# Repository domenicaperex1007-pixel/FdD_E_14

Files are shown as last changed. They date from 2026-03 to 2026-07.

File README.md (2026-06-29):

# 🌍 Equipo 14 - Fundamentos de diseño
## Carrera de Ingeniería Ambiental / Informática/ Industrial
## Universidad Peruana Cayetano Heredia
## 👥Descripción del equipo

### Somos el **equipo 14** del curso de **Fundamentos de Diseño 2026-1**, conformado por estudiantes de distintas ramas de ingeniería.

### *Nuestro objetivo es aplicar la metodología de diseño para generar soluciones innovadoras, reales y con impacto social, tecnológico y ambiental.*
## 🎯 Objetivos de Desarrollo Sostenible (ODS)

*Nuestro proyecto se alinea con los siguientes ODS:*

- 💧 **ODS 6:** Agua limpia y saneamiento  
- 🏙️ **ODS 11:** Ciudades y comunidades sostenibles  
- 🌱 **ODS 13:** Acción por el clima

## 🌊 ODS 6: Agua limpia y saneamiento    

El **Objetivo de Desarrollo Sostenible 6** plantea la necesidad de garantizar el acceso universal a agua potable y servicios de saneamiento adecuados.

En el Perú, aproximadamente el 90% de la población urbana accede a agua potable, pero en zonas rurales amazónicas esta cifra puede descender a menos del 70%, evidenciando brechas significativas<sup>1</sup> . 

En la selva peruana, las inundaciones contaminan fuentes de agua con residuos, sedimentos y agentes patógenos, incrementando enfermedades como diarreas, dengue entre otras. En regiones como Loreto, donde las inundaciones afectan cada año a miles de familias, el impacto sobre el acceso a agua segura es directo. Esta situación nos demuestra que la gestión del agua no puede desligarse de la gestión del riesgo de desastres, ya que eventos extremos deterioran rápidamente las condiciones sanitarias.

## 🏙️ ODS 11: Ciudades y comunidades sostenibles

El **Objetivo de Desarrollo Sostenible 11** plantea reducir significativamente el impacto de desastres en comunidades vulnerables. 

En el Perú, las lluvias intensas e inundaciones representan más del 60% de las emergencias registradas anualmente, afectando a más de 170,000 personas en la temporada del 2022 al 2023<sup>2</sup> . En la región Loreto, provincias como Requena presentan alta vulnerabilidad debido a su ubicación en zonas inundables y su limitada conectividad. De hecho, eventos recientes han llevado a declarar estado de emergencia en distritos de Requena por inundaciones recurrentes que afectan viviendas, cultivos y servicios básicos<sup>3</sup> . 

Esta problemática nos muestra que la planificación por parte de la comunidad es clave para reducir riesgos. A su vez, la protección de infraestructuras de agua depende de una adecuada organización del territorio, lo que muestra la dependencia recíproca entre ambos objetivos.

## 🌱 ODS 13: Acción por el clima

El **Objetivo de Desarrollo Sostenible 13** se enfoca en fortalecer la resiliencia frente al cambio climático, el cual ha incrementado la frecuencia de lluvias intensas y crecidas de ríos en el Perú<sup>4</sup> . Este fenómeno agrava tanto la disponibilidad de agua segura como la sostenibilidad de las comunidades. En este contexto, la implementación de sistemas de alerta temprana resulta clave como medida de adaptación. Estos sistemas permiten anticipar inundaciones, facilitando la protección de fuentes de agua, la evacuación oportuna y la reducción de pérdidas humanas y materiales.

Por ejemplo, un sistema de alerta temprana como Llaqta Guardian podría reducir la exposición al riesgo al emitir alertas oportunas incluso en contextos de baja conectividad. De esta manera, la integración de estos tres objetivos resulta fundamental para abordar la problemática de las inundaciones en la Amazonía peruana.

## 📸 Fotografía del Equipo
<p align="center">
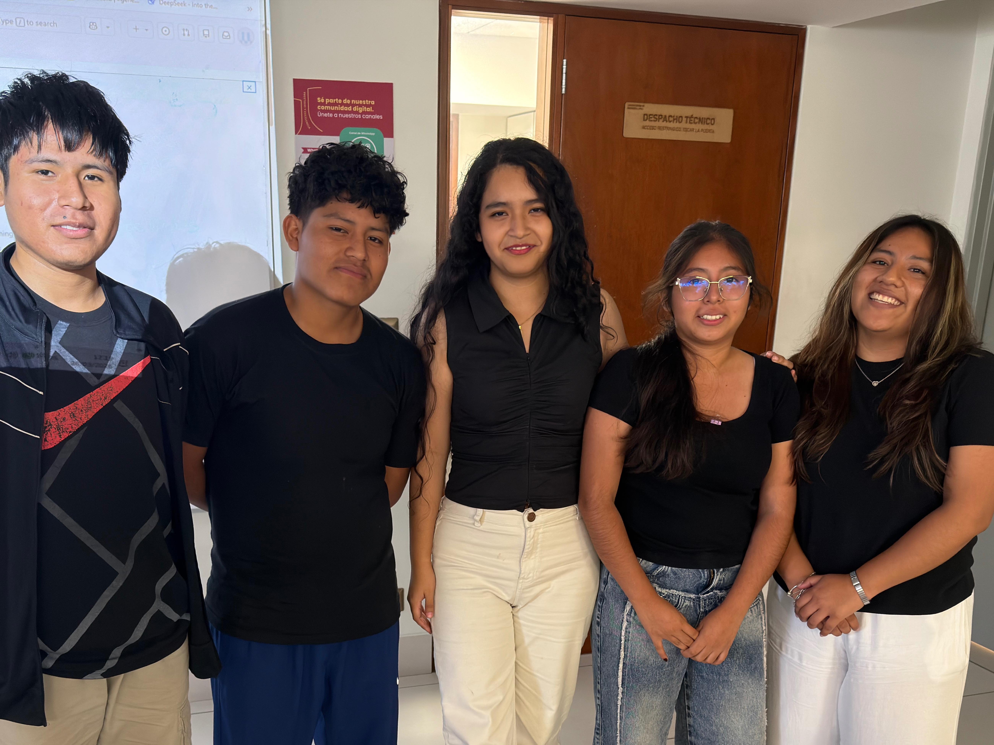
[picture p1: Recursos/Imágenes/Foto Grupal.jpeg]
  
  <br>
  <em>Figura 1. Fotografía del equipo 14</em>
</p>

## 👥 Integrantes del equipo

| Foto | Nombre | Rol | Correo electrónico | Habilidades |
|---|---|-----|---|---|
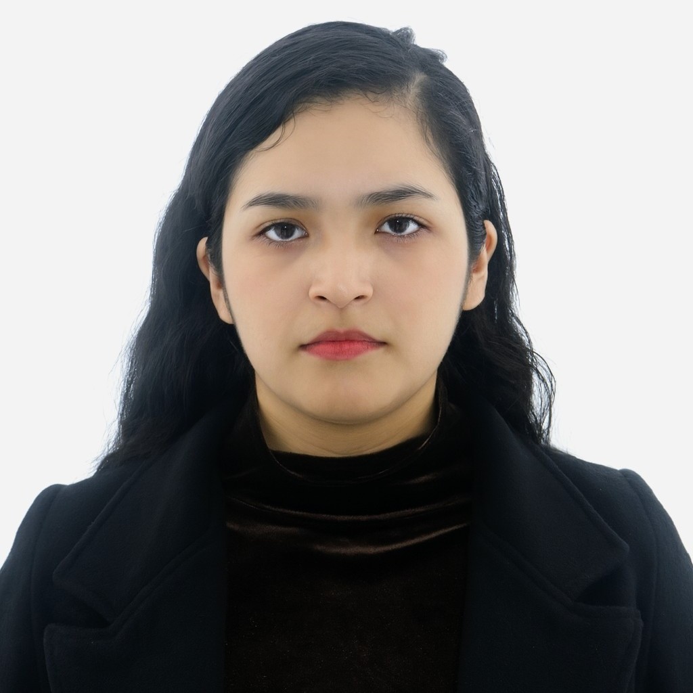
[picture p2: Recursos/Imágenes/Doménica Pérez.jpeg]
|  | Doménica Pérez | domenica.perez@upch.pe | Líder de equipo | Gestión de proyectos con enfoque en innovación social, sostenibilidad e impacto ambiental |
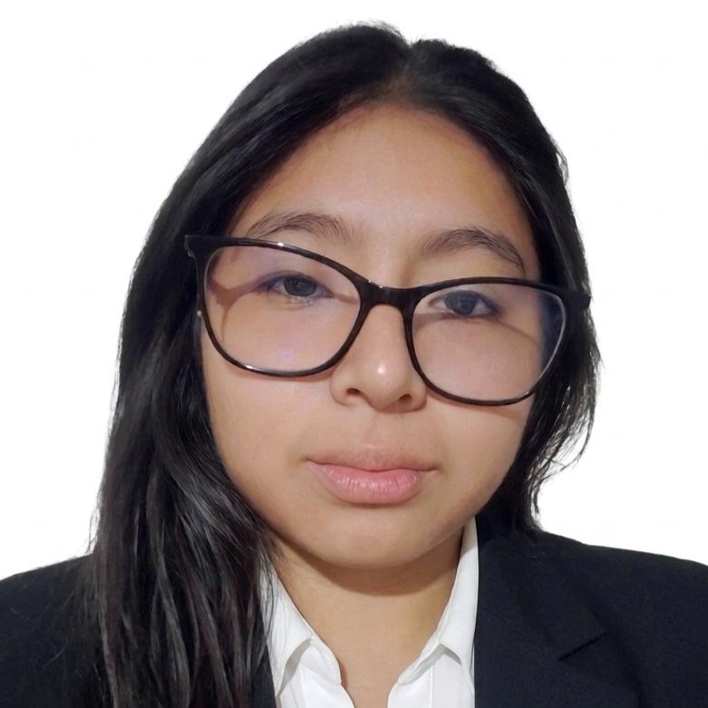
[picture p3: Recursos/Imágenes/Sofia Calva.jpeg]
|  | Sofía Calva | sofia.calva@upch.pe | Programadora | Programación, simulación y automatización de procesos |
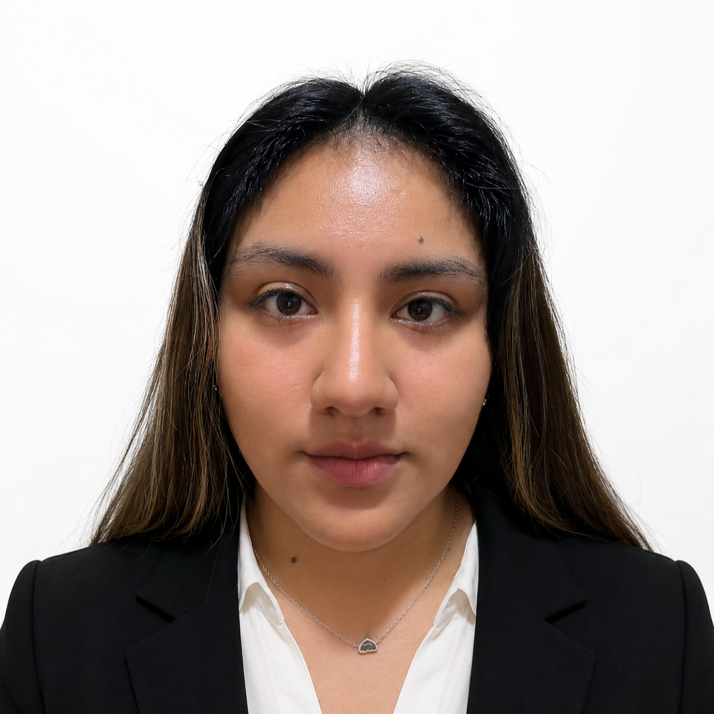
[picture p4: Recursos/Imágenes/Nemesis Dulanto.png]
|  | Némesis Dulanto | nemesis.dulanto@upch.pe | Diseñadora | Diseño de prototipos, innovación, creatividad y adaptabilidad  |
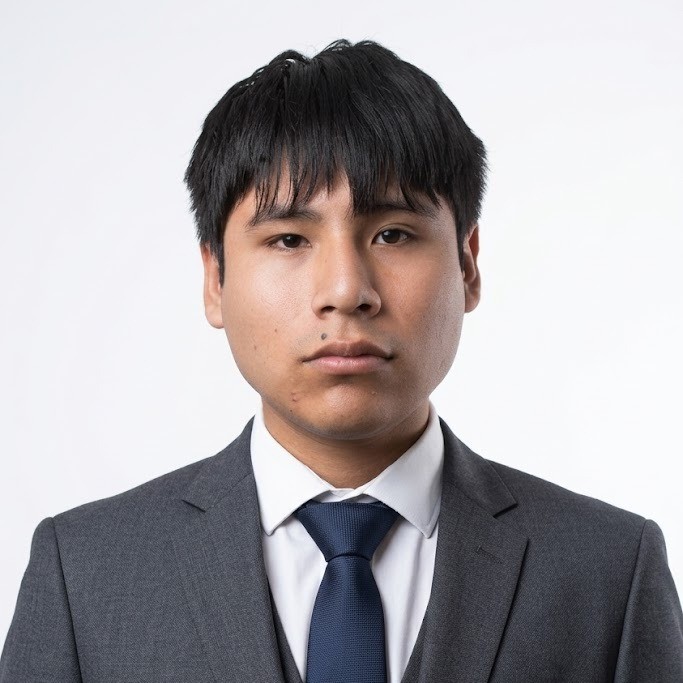
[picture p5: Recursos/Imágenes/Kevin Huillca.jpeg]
|  | Kevin Huillca | kevin.huillca@upch.pe | Investigación | Investigación de problemáticas urbanas, análisis de datos y propuestas de desarrollo comunitario sostenible |
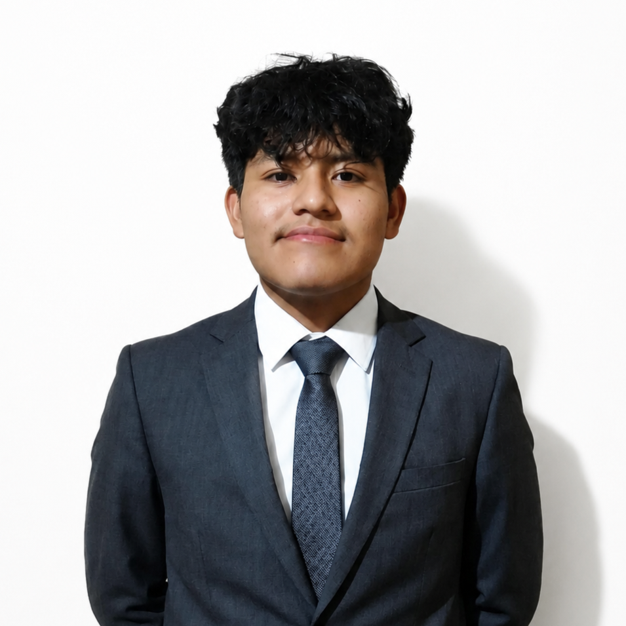
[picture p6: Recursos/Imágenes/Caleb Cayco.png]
|  | Caleb Cayco | caleb.cayco@upch.pe | Documentación | Elaboración de informes, redacción técnica y presentación de resultados |

## 📌 Resumen 

### Este repositorio presenta quiénes somos como equipo, nuestras motivaciones y los ODS en los que enfocaremos nuestro proyecto durante el curso. Buscamos desarrollar soluciones que integren tecnología, diseño e impacto social 🌍✨

### 📚 Referencias 

1. Ministerio de Vivienda, Construcción y Saneamiento (MVCS). *Acceso a agua y saneamiento en el Perú. Lima: MVCS; 2022.* Disponible en: https://www.gob.pe/vivienda

2. Instituto Nacional de Defensa Civil (INDECI). *Reporte de emergencias por lluvias intensas 2022–2023. Lima: INDECI; 2023.* Disponible en: https://sinpad.indeci.gob.pe/sinpad/

3. Gobierno del Perú. *Declaratorias de estado de emergencia por inundaciones en Loreto. Lima: PCM; 2023.* Disponible en: https://www.gob.pe/pcm

4. *Ministerio del Ambiente del Perú (MINAM). Estrategia nacional ante el cambio climático. Lima: MINAM; 2021.* Disponible en: https://www.gob.pe/minam

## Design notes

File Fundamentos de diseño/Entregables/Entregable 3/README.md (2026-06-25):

# Entregable 3: Diseño Detallado y Prototipado Final – Llaqta Guardian

Este directorio reúne la documentación técnica correspondiente al diseño físico y electrónico del sistema **Llaqta Guardian**, incluyendo los esquemáticos finales, bocetos de diseño, modelado tridimensional y los archivos necesarios para la fabricación e impresión del prototipo.

---

# Contenido del Entregable

## 1. Esquemáticos Finales

Documentación correspondiente al diseño electrónico final del sistema, donde se detallan las conexiones entre los componentes y módulos utilizados.

* [Esquemático Final del Sistema](./esquematico/EsquematicoV3final.pdf)

---

## 2. Bocetos de Diseño

Se presentan los bocetos actualizados del prototipo, incluyendo vistas externas e internas para representar la distribución física de los componentes.

* [Bocetos Actualizados (Vistas Externas e Internas)](./bocetos/README.md)

---

## 3. Modelado 3D y Fabricación

Los modelos tridimensionales del prototipo fueron desarrollados utilizando **Onshape** y posteriormente exportados en formato **STL** para su fabricación mediante impresión 3D.

---

# Modelado 3D en Onshape

## Proyecto Principal

Enlace al desarrollo del diseño tridimensional principal del sistema:

🔗 https://cad.onshape.com/documents/8baaf38552f36213a97af7a6/w/b3c742e4b1a73393e4bc2860/e/2fc9d89f6763d3e15fb233f8

---

## Ensamblaje Completo

Enlace correspondiente al ensamblaje general del prototipo con todas las piezas integradas:

🔗 https://cad.onshape.com/documents/8baaf38552f36213a97af7a6/w/b3c742e4b1a73393e4bc2860/e/559547a897bf8670bddb5d4e

---

# Archivos de Fabricación

## Plano Técnico

Documento utilizado como referencia para la fabricación y validación dimensional del prototipo.

* [Plano de Fabricación (PDF)](./modelado%20-%203D/Caja%20Drawing%201%20%281%29.pdf)

---

## Archivos STL

Archivos preparados para el proceso de impresión 3D de los componentes del prototipo.

### Caja Principal

* [Modelado Caja.stl](./modelado%20-%203D/Modelado%20Caja.stl)

### Puerta o Tapa

* [Modelado Puerta.stl](./modelado%20-%203D/Modelado%20Puerta.stl)

### Ensamblajes

* [Assembly 1 (2).stl](./modelado%20-%203D/Assembly%201%20%282%29.stl)

* [Assembly completo.stl](./modelado%20-%203D/Assembly%20completo.stl)

---

# Descripción del Prototipo

El diseño mecánico fue desarrollado para alojar y proteger los componentes electrónicos del sistema **Llaqta Guardian**, incluyendo el microcontrolador ESP32, el sistema de alimentación mediante batería recargable, la bocina de alerta, sensores ambientales y elementos estructurales de soporte.

La carcasa incorpora una puerta de acceso para facilitar el mantenimiento del sistema, además de espacios internos destinados al montaje organizado de sensores, conexiones y cableado electrónico.

Este diseño permite integrar los componentes físicos y electrónicos en una estructura compacta, resistente y adecuada para la implementación del prototipo en escenarios reales.

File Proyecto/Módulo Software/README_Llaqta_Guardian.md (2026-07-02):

# Llaqta Guardian

**Llaqta Guardian** es un prototipo de monitoreo y alerta temprana de inundaciones pensado para zonas vulnerables cercanas a ríos, como Requena, Loreto. El sistema combina un módulo físico con sensores y una plataforma web local para registrar datos, evaluar el riesgo y apoyar la toma de decisiones de dirigentes o autoridades locales.

## Funcionalidades principales

- Lectura de distancia del agua mediante sensor ultrasónico impermeable.
- Conversión de distancia a nivel de agua usando la referencia física del prototipo.
- Lectura de temperatura y humedad con DHT22.
- Detección de lluvia mediante sensor FC-37.
- Envío de datos desde ESP32 hacia una API Flask por WiFi.
- Almacenamiento histórico en SQLite.
- Dashboard web con nivel de agua, lluvia, riesgo, confianza, predicción y gráficas.
- Clasificación del estado en: `NORMAL`, `PREVENTIVO`, `ALERTA` y `CRITICO`.

## Medidas consideradas del prototipo

- Altura del sensor ultrasónico: **45 cm**.
- Distancia mínima confiable del sensor: **20 cm**.
- Nivel máximo confiable: **25 cm**.
- Umbral preventivo: **10 cm**.
- Umbral de alerta: **18 cm**.
- Umbral crítico: **23 cm**.

La fórmula usada es:

```txt
nivel_agua_cm = altura_sensor_cm - distancia_sensor_agua_cm
```

Si la distancia medida es menor o igual a 20 cm, el sistema considera que el agua llegó a la zona muerta del sensor y marca riesgo crítico por seguridad.

## Estructura del proyecto

```txt
llaqta_software/
├── app2.py
├── llaqta_guardian.db
└── templates/
    └── index2.html

sketch_jun25a/
└── sketch_jun25a.ino
```

## Tecnologías usadas

### Hardware / Arduino IDE

- ESP32.
- Sensor ultrasónico impermeable.
- DHT22.
- Sensor de lluvia.
- Módulo MP3 para mensajes de alerta.
- WiFi para comunicación con el servidor local.

### Software

- Python.
- Flask.
- Flask-CORS.
- SQLite.
- HTML, CSS y JavaScript.
- ArduinoJson para el envío de datos desde ESP32.

## Instalación del software

Instalar dependencias:

```bash
pip install flask flask-cors
```

Ejecutar el servidor:

```bash
python app2.py
```

Abrir el dashboard en el navegador:

```txt
http://127.0.0.1:5000
```

## Configuración del ESP32

En el archivo `sketch_jun25a.ino`, configurar el WiFi y la IP de la laptop donde corre Flask:

```cpp
const char* WIFI_SSID = "NOMBRE_DEL_WIFI";
const char* WIFI_PASSWORD = "CONTRASEÑA_DEL_WIFI";
const char* SERVER_URL = "http://IP_DE_LA_LAPTOP:5000/api/medicion";
```

Ejemplo:

```cpp
const char* SERVER_URL = "http://10.255.118.127:5000/api/medicion";
```

La laptop y el ESP32 deben estar conectados a la misma red WiFi.

## Endpoints principales

```txt
GET  /                 Dashboard web
POST /api/medicion     Recibe datos del ESP32
GET  /api/ultimas      Devuelve las últimas mediciones
POST /api/reiniciar    Borra el historial de mediciones
```

## Estado del proyecto

Prototipo funcional en etapa de pruebas. El sistema ya permite recibir datos del ESP32, almacenarlos, visualizarlos en un dashboard local y calcular el nivel de riesgo de inundación.

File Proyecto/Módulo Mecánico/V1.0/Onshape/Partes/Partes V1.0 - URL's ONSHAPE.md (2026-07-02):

# Modelado 3D en Onshape

## Versión 1.0

| Componente | Enlace |
|---|---|
| Caja | [Ver modelo](https://cad.onshape.com/documents/1b75a7373ed95fcd3033aad5/w/940eb8b65c2381251bd8110a/e/18b892f5a5ff7d697d1865f3) |
| Puerta | [Ver modelo](https://cad.onshape.com/documents/1b75a7373ed95fcd3033aad5/w/940eb8b65c2381251bd8110a/e/601143c99b9aa8aae80f3b4b) |
| Soporte FC37 | [Ver modelo](https://cad.onshape.com/documents/1b75a7373ed95fcd3033aad5/w/940eb8b65c2381251bd8110a/e/e0b3e0f03d1a822f4ba62ea0) |
| Estructura en L | [Ver modelo](https://cad.onshape.com/documents/430f59dfc079aeac550c5cab/w/060fb58aac5f1bf0b57e059d/e/6f8cf47fa18de8b1634f72a5) |

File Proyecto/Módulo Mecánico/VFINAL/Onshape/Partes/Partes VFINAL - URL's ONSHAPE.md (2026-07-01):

# Modelado 3D en Onshape

| Componente | Enlace |
|---|---|
| Estaca | [Ver modelo](https://cad.onshape.com/documents/173e2005808784d04f353813/w/33e4a8af6ce4369997d77d69/e/f8e8c1452dcb2406cfedd84d) |
| Puerta | [Ver modelo](https://cad.onshape.com/documents/173e2005808784d04f353813/w/33e4a8af6ce4369997d77d69/e/490dbcc43355d9157482bc95) |
| Caja | [Ver modelo](https://cad.onshape.com/documents/173e2005808784d04f353813/w/33e4a8af6ce4369997d77d69/e/a9140cbccc0b152eeb848519) |
| Dona | [Ver modelo](https://cad.onshape.com/documents/173e2005808784d04f353813/w/33e4a8af6ce4369997d77d69/e/064c26e537934850eb4c272b) |
| Ventana | [Ver modelo](https://cad.onshape.com/documents/173e2005808784d04f353813/w/33e4a8af6ce4369997d77d69/e/a6c7ab7c205cfe8a056f6825) |
| Estructura en L | [Ver modelo](https://cad.onshape.com/documents/173e2005808784d04f353813/w/33e4a8af6ce4369997d77d69/e/58b5b27754248d4fb28bbe2d) |
| Soporte FC37 | [Ver modelo](https://cad.onshape.com/documents/173e2005808784d04f353813/w/33e4a8af6ce4369997d77d69/e/971f2c3d2e04c26e01821764) |

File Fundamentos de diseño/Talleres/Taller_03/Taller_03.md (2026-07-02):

# LLAQTA GUARDIAN: Sistema Integral de Alerta Temprana para la Detección de Inundaciones Fluviales en Comunidades Rurales

# Introducción:

Las inundaciones constituyen uno de los tipos de desastres naturales más frecuentes en el Perú y el mundo. Por definición oficial, las inundaciones ocurren cuando "el agua ocupa un terreno que debería estar libre"<sup>1</sup>, es decir, por el desborde de ríos, lluvias intensas u otros eventos hídricos que cubren zonas normalmente secas. A nivel global, la Organización Meteorológica Mundial (OMM) señala que los fenómenos relacionados con el agua, entre ellos las inundaciones, dominan la lista de desastres de las últimas décadas tanto en pérdidas humanas como económicas<sup>2</sup>. Según el Atlas de la OMM sobre mortalidad y pérdidas económicas debidas a fenómenos meteorológicos, climáticos e hidrológicos extremos (1970-2019), las inundaciones causaron unas 58 700 muertes en ese período a nivel mundial<sup>2</sup>, lo que refleja el enorme impacto humano de estos eventos. En el contexto nacional, el inventario de inundaciones del SENAMHI registra que durante el período 2003-2012 las inundaciones afectaron severamente a la población peruana, documentando miles de personas damnificadas y viviendas destruidas en todo el país<sup>3</sup>. Solo en 2019 se reportaron 39 fallecidos y 8 299 afectados por inundaciones en el Perú<sup>3</sup>. Estos datos oficiales demuestran que las inundaciones son un problema recurrente y de alta prioridad en la gestión de riesgos en el Perú.

En la Amazonía peruana, las inundaciones tienen dinámicas particulares dadas la geografía y la variabilidad climática de la región. Loreto, en la cuenca del Amazonas, recibe lluvias muy intensas anualmente y está surcada por ríos de gran caudal como el Ucayali y el Marañón. Como consecuencia, la población ribereña sufre inundaciones estacionales frecuentes. Por ejemplo, durante las lluvias registradas en marzo de 2025, más de 20 000 habitantes de las provincias de Alto Amazonas, Requena y Ucayali quedaron afectados por crecidas e inundaciones<sup>4</sup>. El distrito de Requena (provincia homónima) fue especialmente golpeado: el reporte oficial indica que 53 familias y 1 500 personas quedaron damnificadas por la inundación de sus viviendas<sup>4</sup>. Estos eventos son parte de una variabilidad climática en la Amazonía peruana que implica la alternancia de fenómenos El Niño/La Niña y lluvias extremas, con crecidas cada vez más frecuentes de los ríos amazónicos.

El caso del distrito de Requena ejemplifica la vulnerabilidad local. Este distrito ribereño del Ucayali posee una topografía baja que facilita el desborde del río ante lluvias intensas. En eventos recientes, cada episodio inundó a cientos de hogares. De acuerdo con el Reporte Complementario N.º 5143 del INDECI, a consecuencia del incremento del caudal del río Ucayali y su desborde, 868 viviendas resultaron afectadas y 231 fueron destruidas en la provincia de Requena<sup>5</sup>. Estas cifras oficiales muestran que cada crecida impacta significativamente a la población y su infraestructura. Las autoridades regionales han declarado emergencias y distribuido ayuda humanitaria (albergues, insumos básicos) a los damnificados. En un territorio con alta exposición al agua, viviendas ribereñas precarias y escasas obras de defensa, este patrón evidencia que sistemas de alerta temprana locales podrían salvar vidas al ganar tiempo para la evacuación y preparación.

Ante estos daños recurrentes, el Ejecutivo ha declarado estado de emergencia en varios distritos de Loreto como Yurimaguas y Jenaro Herrera para canalizar ayuda y reforzar la prevención. Paralelamente, la Autoridad Nacional del Agua (ANA/CENEPRED) ha identificado múltiples localidades ribereñas, como Nuevo Requena y Nuevo Iquitos, en peligro inminente y con alta vulnerabilidad ante el aumento del caudal del Ucayali<sup>7</sup>. Más recientemente, el SENAMHI ha avanzado en el desarrollo de sistemas de pronóstico hidrológico para la Amazonía peruana orientados a la alerta por inundaciones, reconociendo la urgencia de proteger a las comunidades ribereñas más vulnerables<sup>6</sup>.

No obstante, pese a la existencia de sistemas de monitoreo (SENAMHI, INDECI, alertas hidrológicas, entre otros), las comunidades más vulnerables han recibido avisos tardíos o inexistentes. En muchas zonas ribereñas los canales oficiales de alerta no fueron efectivos a tiempo, lo que evidencia demoras y fallas en la comunicación. Como consecuencia, estas deficiencias en el sistema de alerta agravaron el impacto de los desastres, dejando a los pobladores sin advertencias suficientes antes de las crecidas.

Por ello, el proyecto Llaqta Guardian se plantea como un sistema de alerta temprana por inundaciones en el distrito de Requena. A través del monitoreo continuo de variables ambientales y la visualización de informacón en tiempo real, el sistema proporciona a las autoridades locales una herramienta para apoyar la toma de decisiones y coordinar acciones preventivas. Asimismo, se encuentra directamente alineado con los Objetivos de Desarrollo Sostenible (ODS) de la Agenda 2030<sup>8</sup>. Contribuye al ODS 6 (agua limpia y saneamiento) al proteger las fuentes de agua potable: anticipar crecidas puede prevenir la contaminación de pozos y asegurar la calidad del agua para las comunidades ribereñas. Fortalece el ODS 11 (ciudades y comunidades sostenibles) porque mejora la resiliencia ante desastres: una alerta oportuna permite reforzar viviendas, escuelas e infraestructura clave antes de que ocurra la inundación, reduciendo daños humanos y materiales. Además, apoya el ODS 13 (acción por el clima) al constituir una medida de adaptación ante fenómenos extremos vinculados al cambio climático. El proyecto combina ciencia hidrológica, tecnología de vigilancia y participación ciudadana para reducir las pérdidas humanas y los daños materiales. En síntesis, Llaqta Guardian traduce datos hidrológicos en acciones concretas de prevención local, promoviendo comunidades más seguras, un manejo sostenible del agua y una mayor preparación frente al cambio climático, en consonancia con la Agenda 2030<sup>8</sup>

---

# Problemática

El distrito de Requena, en Loreto, enfrenta inundaciones recurrentes provocadas por el desborde del río Ucayali. El CENEPRED identifica en la región 66 puntos críticos de inundación, casi el triple del promedio nacional, y más de 52 700 viviendas en zonas de riesgo que afectan a cerca de 211 000 personas<sup>9</sup>. La precariedad agrava esta exposición: 9 de cada 10 viviendas urbanas de Loreto fueron construidas entre 2007 y 2024 en condiciones inadecuadas<sup>9</sup>, y la inversión pública en prevención cayó un 46% anual entre 2022 y 2025, con apenas un 23% de ejecución presupuestal en 2025<sup>9</sup>.

A esto se suma la ausencia de un sistema de alerta temprana operativo a escala local. El SENAMHI reconoce que la Amazonía peruana carece de cobertura hidrometeorológica suficiente debido a la escasez de estaciones de monitoreo<sup>6</sup>, y el PNUD advierte que los sistemas de alerta existentes suelen funcionar de forma aislada de las comunidades que deben proteger, neutralizando su efectividad<sup>10</sup>. Como resultado, cada crecida del Ucayali encuentra a Requena sin avisos oportunos: el INDECI registró 868 viviendas afectadas y 231 destruidas en junio de 2023<sup>5</sup>, y en marzo de 2025 más de 1 500 personas resultaron damnificadas<sup>4</sup>. 

Frente a este escenario de vulnerabilidad estructural, desinversión y alertas ineficaces, Llaqta Guardian surge como una respuesta tecnológica urgente y necesaria para proteger a la población ribereña de Requena.

---

# Propuesta de solución innovadora: «Llaqta Guardian»

El proyecto propone el desarrollo de una red comunitaria inteligente de vigilancia ambiental de bajo costo, basada en tecnologías IoT y herramientas de código abierto, diseñada para operar de forma autónoma en contextos de alta vulnerabilidad. A diferencia de las estaciones meteorológicas tradicionales, que suelen ser costosas, centralizadas y de difícil acceso, este sistema descentralizado permite el monitoreo en tiempo real de variables ambientales críticas directamente desde el territorio, proporcionando información confiable para apoyar la toma de decisiones de las autoridades locales y fortalecer la gestión del riesgo de inundaciones. 

El dispositivo, concebido como un prototipo replicable y escalable, registra de manera continua parámetros clave asociados al comportamiento del río y a las condiciones ambientales relacionadas con posibles inundaciones. Además, integra una plataforma web para la visualización de la información, así como un sistema de alerta sonora mediante mensajes de voz para advertir a las personas que se encuentren cerca del punto de monitoreo cuando se detecten niveles críticos.

En este contexto, Llaqta Guardian puede implementarse progresivamente en diferentes comunidades vulnerables, permitiendo conformar una red local de monitoreo ambiental que fortalezca la autonomía de los gobiernos locales, facilite la respuesta oportuna ante eventos de riesgo y contribuya a una gestión más eficiente del riesgo de desastres.

---

# Referencias bibliográficas

1. Servicio Nacional de Meteorología e Hidrología (SENAMHI). Nuevo mapa del SENAMHI permite conocer zonas inundables en el Perú. https://www.gob.pe/institucion/senamhi/noticias/126363-nuevo-mapa-del-senamhi-permite-conocer-zonas-inundables-en-el-peru 

2. Organización Meteorológica Mundial (OMM). Los fenómenos peligrosos relacionados con el agua son los grandes causantes de los desastres de los últimos 50 años. Ginebra: OMM; 2021 Jul 22
https://wmo.int/es/media/los-fenomenos-peligrosos-relacionados-con-el-agua-son-los-grandes-causantes-de-los-desastres-de-los 

3. SENAMHI. Inventario de datos de eventos de inundaciones del Perú. Lima: Ministerio del Ambiente; 2022 
https://www.senamhi.gob.pe/load/file/01401SENA-99.pdf 

4. Agencia Peruana de Noticias (ANDINA). Lluvias en Loreto: suman más de 20 mil afectados en distritos declarados en emergencia. Loreto, 22 Mar 2025
https://andina.pe/agencia/noticia-lluvias-loreto-suman-mas-20-mil-afectados-distritos-declarados-emergencia-1023256.aspx 

5. Instituto Nacional de Defensa Civil (INDECI) – COEN. Reporte Complementario N.º 5143 (15 jun 2023) – Inundación por desborde de río en Requena (Loreto). Lima: INDECI, 2023. 
https://portal.indeci.gob.pe/wp-content/uploads/2023/06/REPORTE-COMPLEMENTARIO-N%C2%BA-5143-15JUN2023-INUNDACI%C3%93N-POR-DESBORDE-DE-R%C3%8DO-EN-EL-DISTRITO-DE-REQU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 

6. Servicio Nacional de Meteorología e Hidrología del Perú (SENAMHI). Pronósticos que salvan vidas: hacia un sistema de alerta por inundaciones en la Amazonía peruana (nota informativa, 17 abr 2026). Lima: SENAMHI.
https://www.gob.pe/institucion/senamhi/noticias/1380395-pronosticos-que-salvan-vidas-hacia-un-sistema-de-alerta-por-inundaciones-en-la-amazonia-peruana 

7. Autoridad Nacional del Agua (ANA) – CENEPRED. Informe N.º 008-2018-ANA-AAA-IX-UCAYALI-ALA-P-JFP: Identificación de zona de riesgo y puntos críticos en la ciudad de Requena (Loreto). Lima: ANA/CENEPRED, 2018.
https://sigrid.cenepred.gob.pe/sigridv3/documento/4343 

8. Naciones Unidas (ONU). Transformar nuestro mundo: la Agenda 2030 para el Desarrollo Sostenible 
https://unctad.org/system/files/official-document/ares70d1_es.pdf 

9. Instituto Peruano de Economía (IPE); Portal PQS. Loreto: más de 52 mil viviendas están expuestas a riesgo de inundación. Lima: PQS; 2026 Abr 27. Disponible en: https://pqs.pe/actualidad/loreto-mas-de-52-mil-viviendas-estan-expuestas-a-riesgo-de-inundacion/

10. Programa de las Naciones Unidas para el Desarrollo (PNUD). La lucha colectiva contra las inundaciones: comunidad, datos y resiliencia. Nueva York: PNUD; 2023. Disponible en: https://www.undp.org/es/panama/blog/la-lucha-colectiva-de-panama-contra-las-inundaciones-construyendo-comunidad-datos-y-resiliencia

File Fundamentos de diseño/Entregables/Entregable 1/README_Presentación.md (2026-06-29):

# 🌍 Equipo 14 - Fundamentos de diseño
## Carrera de Ingeniería Ambiental / Informática/ Industrial
## Universidad Peruana Cayetano Heredia
## 👥Descripción del equipo

### Somos el **equipo 14** del curso de **Fundamentos de Diseño 2026-1**, conformado por estudiantes de distintas ramas de ingeniería.

### *Nuestro objetivo es aplicar la metodología de diseño para generar soluciones innovadoras, reales y con impacto social, tecnológico y ambiental.*
## 🎯 Objetivos de Desarrollo Sostenible (ODS)

*Nuestro proyecto se alinea con los siguientes ODS:*

- 💧 **ODS 6:** Agua limpia y saneamiento  
- 🏙️ **ODS 11:** Ciudades y comunidades sostenibles  
- 🌱 **ODS 13:** Acción por el clima

## 🌊 ODS 6: Agua limpia y saneamiento    

El **Objetivo de Desarrollo Sostenible 6** plantea la necesidad de garantizar el acceso universal a agua potable y servicios de saneamiento adecuados.

En el Perú, aproximadamente el 90% de la población urbana accede a agua potable, pero en zonas rurales amazónicas esta cifra puede descender a menos del 70%, evidenciando brechas significativas<sup>1</sup> . 

En la selva peruana, las inundaciones contaminan fuentes de agua con residuos, sedimentos y agentes patógenos, incrementando enfermedades como diarreas, dengue entre otras. En regiones como Loreto, donde las inundaciones afectan cada año a miles de familias, el impacto sobre el acceso a agua segura es directo. Esta situación nos demuestra que la gestión del agua no puede desligarse de la gestión del riesgo de desastres, ya que eventos extremos deterioran rápidamente las condiciones sanitarias.

## 🏙️ ODS 11: Ciudades y comunidades sostenibles

El **Objetivo de Desarrollo Sostenible 11** plantea reducir significativamente el impacto de desastres en comunidades vulnerables. 

En el Perú, las lluvias intensas e inundaciones representan más del 60% de las emergencias registradas anualmente, afectando a más de 170,000 personas en la temporada del 2022 al 2023<sup>2</sup> . En la región Loreto, provincias como Requena presentan alta vulnerabilidad debido a su ubicación en zonas inundables y su limitada conectividad. De hecho, eventos recientes han llevado a declarar estado de emergencia en distritos de Requena por inundaciones recurrentes que afectan viviendas, cultivos y servicios básicos<sup>3</sup> . 

Esta problemática nos muestra que la planificación por parte de la comunidad es clave para reducir riesgos. A su vez, la protección de infraestructuras de agua depende de una adecuada organización del territorio, lo que muestra la dependencia recíproca entre ambos objetivos.

## 🌱 ODS 13: Acción por el clima

El **Objetivo de Desarrollo Sostenible 13** se enfoca en fortalecer la resiliencia frente al cambio climático, el cual ha incrementado la frecuencia de lluvias intensas y crecidas de ríos en el Perú<sup>4</sup> . Este fenómeno agrava tanto la disponibilidad de agua segura como la sostenibilidad de las comunidades. En este contexto, la implementación de sistemas de alerta temprana resulta clave como medida de adaptación. Estos sistemas permiten anticipar inundaciones, facilitando la protección de fuentes de agua, la evacuación oportuna y la reducción de pérdidas humanas y materiales.

Por ejemplo, un sistema de alerta temprana como Llaqta Guardian podría reducir la exposición al riesgo al emitir alertas oportunas incluso en contextos de baja conectividad. De esta manera, la integración de estos tres objetivos resulta fundamental para abordar la problemática de las inundaciones en la Amazonía peruana.

## 📸 Fotografía del Equipo
<p align="center">
  
  <br>
  <em>Figura 1. Fotografía del equipo 14</em>
</p>

## 👥 Integrantes del equipo

| Foto | Nombre | Correo electrónico | Rol | Habilidades |
|---|---|---|-----|---|
|  | Doménica Pérez | domenica.perez@upch.pe | Líder de equipo | Gestión de proyectos con enfoque en innovación social, sostenibilidad e impacto ambiental |
|  | Sofía Calva | sofia.calva@upch.pe | Programadora | Programación, simulación y automatización de procesos |
|  | Némesis Dulanto | nemesis.dulanto@upch.pe | Diseñadora | Diseño de prototipos, innovación, creatividad y adaptabilidad  |
|  | Kevin Huillca | kevin.huillca@upch.pe | Investigación | Investigación de problemáticas urbanas, análisis de datos y propuestas de desarrollo comunitario sostenible |
|  | Caleb Cayco | caleb.cayco@upch.pe | Documentación | Elaboración de informes, redacción técnica y presentación de resultados |

## 📌 Resumen 

### Este repositorio presenta quiénes somos como equipo, nuestras motivaciones y los ODS en los que enfocaremos nuestro proyecto durante el curso. Buscamos desarrollar soluciones que integren tecnología, diseño e impacto social 🌍✨

### 📚 Referencias 

1. Ministerio de Vivienda, Construcción y Saneamiento (MVCS). *Acceso a agua y saneamiento en el Perú. Lima: MVCS; 2022.* Disponible en: https://www.gob.pe/vivienda

2. Instituto Nacional de Defensa Civil (INDECI). *Reporte de emergencias por lluvias intensas 2022–2023. Lima: INDECI; 2023.* Disponible en: https://sinpad.indeci.gob.pe/sinpad/

3. Gobierno del Perú. *Declaratorias de estado de emergencia por inundaciones en Loreto. Lima: PCM; 2023.* Disponible en: https://www.gob.pe/pcm

4. *Ministerio del Ambiente del Perú (MINAM). Estrategia nacional ante el cambio climático. Lima: MINAM; 2021.* Disponible en: https://www.gob.pe/minam

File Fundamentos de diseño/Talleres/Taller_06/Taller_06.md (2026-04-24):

# MATRIZ DE DESK RESEARCH 

| N° | Fuente | Autor / Institución | Año  | Referencia | Estado de tecnología encontrado | Exigencia o requisito identificado | Restricción o limitación | Función principal | Aplicación al proyecto |
|----|---|---|---|---|---|---|---|---|---|
| 1  | Reporte técnico | SENAMHI | 2022 | Sardon, H.; Lavado-Casimiro, W. y Felipe, O. (2022). Inventario de datos de eventos de inundaciones del Perú. SENAMHI. https://repositorio.senamhi.gob.pe/handle/20.500.12542/1786 | Sistemas de monitoreo hidrometeorológico basados en medición de lluvia y nivel de ríos | El sistema debe monitorear variables como precipitación y nivel del agua para detectar riesgo de inundación | Limitación en la disponibilidad y consistencia de registros históricos de inundaciones | Analizar y gestionar el riesgo de inundaciones mediante datos históricos | Permite definir variables críticas (lluvia y nivel del agua) y la necesidad de monitoreo continuo para activar alertas tempranas en la comunidad |
| 2  | Norma / Informe técnico | CENEPRED | 2013 | Centro Nacional de Estimación, Prevención y Reducción del Riesgo de Desastres (2013). Informe técnico N.° A7030 | Evaluación del riesgo de inundación fluvial | Requiere información hidrológica, topografía y trabajo de campo | No incluye sistema de alerta temprana ni aviso en tiempo real | Identificación de zonas de riesgo | Sustenta la necesidad de un sistema de alerta comunitario como Llaqta Guardian |

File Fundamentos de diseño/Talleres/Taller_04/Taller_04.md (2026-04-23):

# PATENTES

## MÉTODO DE ALERTA TEMPRANA DE INUNDACIONES RURALES BASADO EN PRECIPITACIONES ANTECEDENTES Y EN LA RELACIÓN TOPOLÓGICA AGUAS ARRIBA-AGUAS ABAJO

### - PUBLICACIÓN 
WO2021003768A1·2021-01-14

### - RESUMEN
El método propone una alerta temprana de inundaciones rurales considerando dos factores clave: precipitaciones antecedentes y la relación topológica aguas arriba-aguas abajo. Primero, se vincula cada pueblo con una estación de lluvia para emitir alertas según sus registros. Luego, la precipitación medida se corrige dos veces: la primera por influencia de lluvias previas y la segunda por el efecto acumulativo de cuencas conectadas. Así, se logra un análisis dinámico y más preciso de las condiciones de riesgo, mejorando la fiabilidad de las alertas y apoyando la prevención de inundaciones en comunidades rurales.

### - Imagen
<p align="center">
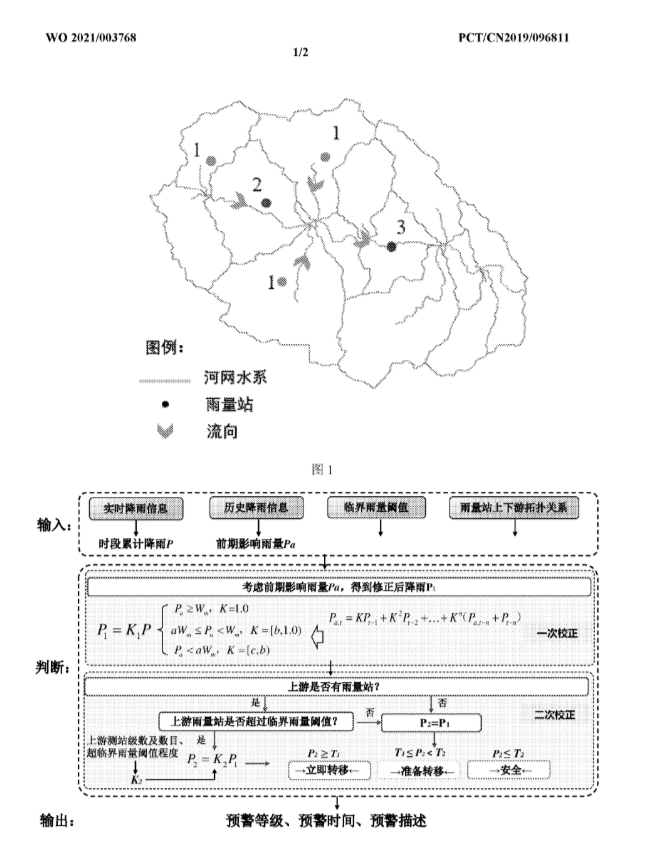
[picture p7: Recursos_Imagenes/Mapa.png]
  
</p>

### - ENLACE

https://worldwide.espacenet.com/patent/search?q=pn%3DWO2021003768A1 

---

## Alerta temprana y sistema de monitorización de inundaciones urbanas en el interior basado en análisis de big data

### - PUBLICACIÓN 
CN119181208A·2024-12-24

### - RESUMEN
El sistema de alerta temprana de inundaciones basado en análisis de big data se fundamenta en la recopilación, transmisión y procesamiento de datos en tiempo real mediante sensores, permitiendo predecir eventos de inundación, emitir alertas oportunas por múltiples canales y apoyar la toma de decisiones ante emergencias. Este enfoque mejora la precisión y rapidez de las alertas, reduciendo significativamente los daños ocasionados. 

Su relevancia para el proyecto Llaqta Guardian radica en que valida el uso de tecnologías basadas en datos y monitoreo continuo para la prevención de desastres; sin embargo, al estar orientado a entornos urbanos con alta conectividad, evidencia la necesidad de adaptar este tipo de soluciones a contextos rurales y de baja conectividad, como las comunidades amazónicas, donde se requiere un sistema accesible, eficiente y enfocado en la protección de la población vulnerable.

### - IMAGEN
<p align="center">
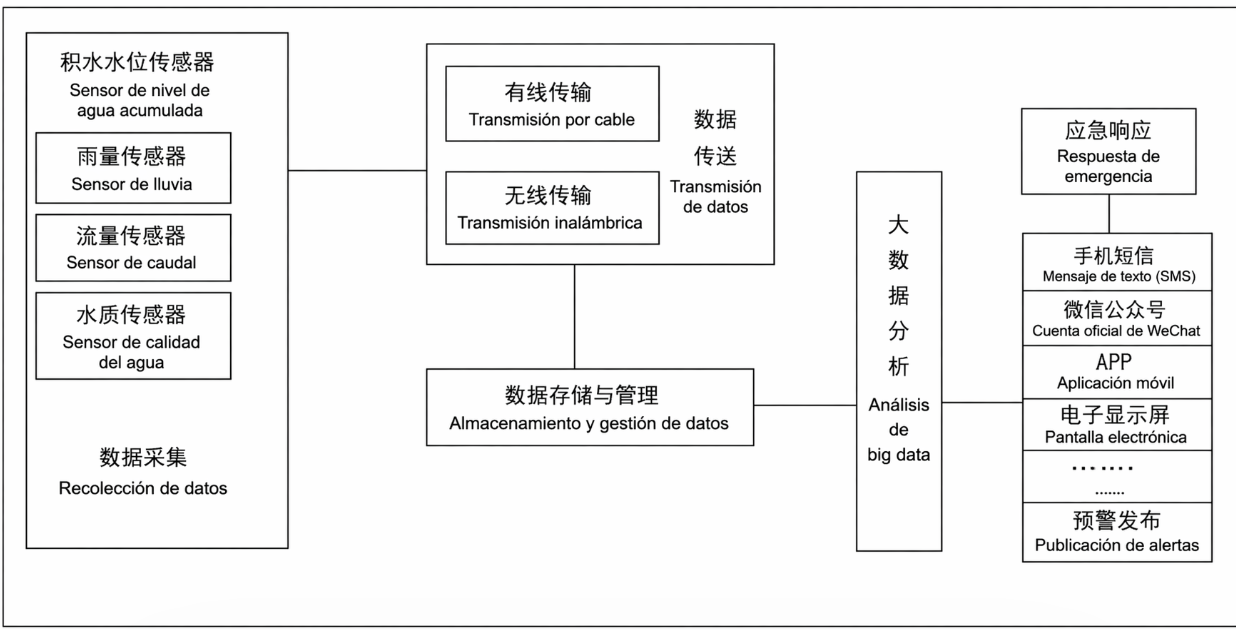
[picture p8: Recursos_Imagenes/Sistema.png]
  
</p>

### - ENLACE
https://worldwide.espacenet.com/patent/search?q=pn%3DCN119181208A

---

## MÉTODO DE PREDICCIÓN DE INUNDACIONES FLUVIALES

### - PUBLICACIÓN 
WO2023276383A1·2023-01-05

### - RESUMEN
La invención propone un método de predicción de inundaciones fluviales basado en la observación en tiempo real mediante vídeo. Incluye un paso de preparación y un paso de identificación del lugar de desbordamiento, que determina si la lluvia provocará una crecida o cuánto tiempo resta antes de la inundación. El proceso se repite durante la lluvia, permitiendo localizar dinámicamente los puntos de desbordamiento entre las partes aguas arriba y aguas abajo del río, mejorando la precisión frente a métodos convencionales.

### - IMAGEN
<p align="center">
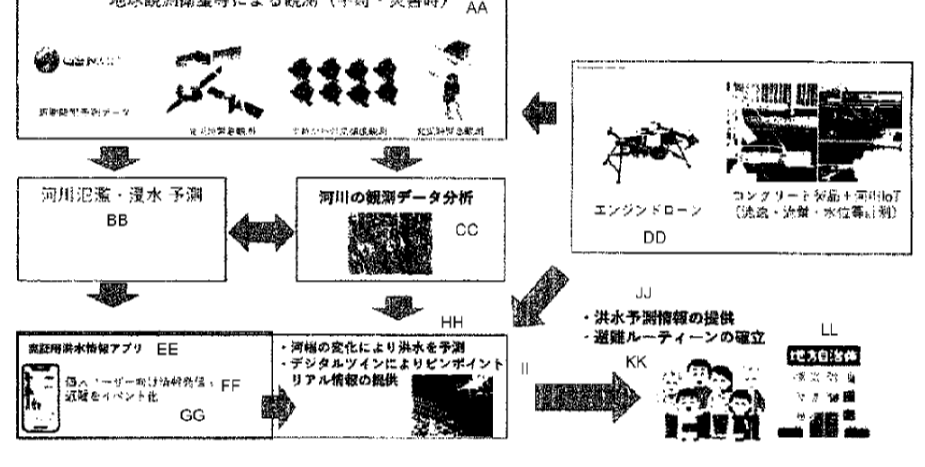
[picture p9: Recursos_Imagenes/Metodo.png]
  
</p>
<p align="center">
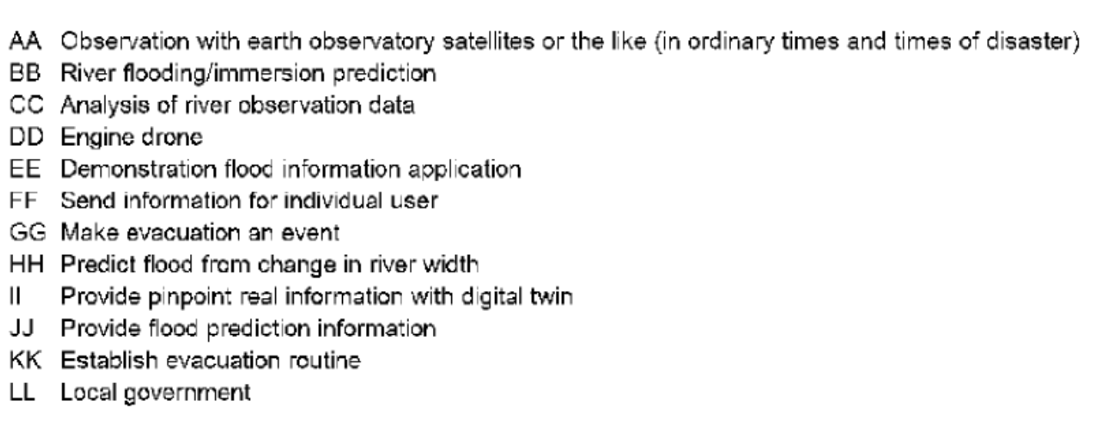
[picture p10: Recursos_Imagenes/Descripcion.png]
  
</p>

### - ENLACE
https://worldwide.espacenet.com/patent/search?q=pn%3DWO2023276383A1

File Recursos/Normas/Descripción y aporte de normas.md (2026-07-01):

# Normas Técnicas Relacionadas

## Norma 1: ISO 22328-1:2020 – *Security and Resilience — Emergency Management — Part 1: General Guidelines for the Implementation of a Community-Based Disaster Early Warning System*

### Resumen de la norma

La norma **ISO 22328-1:2020** establece directrices para la implementación de sistemas de alerta temprana comunitarios frente a desastres naturales. Propone una metodología basada en cinco componentes principales: evaluación de riesgos, difusión y comunicación de información, monitoreo y servicio de alerta, capacidad de respuesta de la comunidad y sostenibilidad del sistema. Su objetivo es que las poblaciones vulnerables puedan recibir advertencias oportunas, comprender el riesgo y actuar adecuadamente para reducir pérdidas humanas y materiales.

### Aporte de la norma al proyecto

Esta norma aporta el marco de referencia para el diseño y funcionamiento del sistema **Llaqta Guardian**, ya que el prototipo busca monitorear el nivel del agua y emitir alertas tempranas ante posibles inundaciones. Asimismo, respalda la implementación de sensores de monitoreo, niveles de alerta, sistemas de comunicación y mecanismos de respuesta comunitaria, asegurando que la información generada por el dispositivo sea útil para la prevención y mitigación de riesgos en comunidades ribereñas.

---

## Norma 2: Lineamientos para el diseño de sistemas integrados de vigilancia y pronóstico hidrometeorológico con fines de alerta temprana (SENAMHI)

### Resumen de la norma

Esta norma establece los criterios técnicos para el diseño e implementación de sistemas de vigilancia y pronóstico hidrometeorológico orientados a la alerta temprana ante inundaciones, lluvias intensas y otros peligros asociados. Asimismo, promueve la integración de redes de observación, sensores, sistemas de monitoreo, gestión de datos y mecanismos de comunicación que permitan generar información confiable y oportuna para la toma de decisiones y la reducción del riesgo de desastres.

### Aporte de la norma al proyecto

Esta norma aporta una base técnica para el desarrollo del prototipo **Llaqta Guardian**, ya que respalda el uso de sensores para el monitoreo de variables relacionadas con inundaciones y la generación de alertas tempranas dirigidas a la población. Además, orienta el diseño de un sistema integrado que garantice la recolección, procesamiento y transmisión de datos en tiempo real, contribuyendo a una respuesta más rápida y eficiente frente a situaciones de emergencia.

---

## Norma 3: Lineamientos para la conformación y funcionamiento de la Red Nacional de Alerta Temprana (RNAT) y la conformación, funcionamiento y fortalecimiento de los Sistemas de Alerta Temprana (SAT)

### Resumen de la norma

Esta norma establece los lineamientos para implementar y fortalecer los Sistemas de Alerta Temprana (SAT) en los diferentes niveles de gobierno, organizaciones comunitarias y sector privado. Define que un SAT debe contar con cuatro componentes fundamentales: conocimiento de los riesgos, servicio de seguimiento y alerta, difusión y comunicación y capacidad de respuesta. Asimismo, promueve el monitoreo permanente de amenazas, el procesamiento de información en tiempo real y la emisión de alertas y alarmas para reducir pérdidas humanas, materiales y ambientales frente a desastres previsibles.

### Aporte de la norma al proyecto

Esta norma brinda el marco técnico y organizacional para el desarrollo del prototipo **Llaqta Guardian**, ya que respalda la implementación de un sistema capaz de monitorear el nivel de riesgo mediante sensores, procesar información en tiempo real y emitir alertas oportunas a la población. Además, orienta el diseño del prototipo hacia una solución integral que incluya vigilancia continua, comunicación efectiva de alertas y fortalecimiento de la capacidad de respuesta comunitaria ante posibles inundaciones.

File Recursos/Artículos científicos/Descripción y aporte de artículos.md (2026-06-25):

# Artículos Relacionados

## Artículo 1: Sistema de alerta temprana basado en aplicación móvil para prevención de huaicos en la quebrada Pedregal, Chosica

### Resumen del artículo

El estudio se desarrolla en la quebrada Pedregal, ubicada en Chosica, una zona con condiciones geológicas y geomorfológicas que favorecen la ocurrencia de flujos de detritos (huaicos), caracterizada por afloramientos tonalíticos y granodioríticos de la superunidad Santa Rosa del Cretácico Superior, cubiertos por depósitos aluviales del Cuaternario.

A partir de esta problemática, se diseñó y desarrolló un sistema de alerta temprana basado en una aplicación móvil orientada a la prevención de los efectos de los huaicos. El sistema utiliza sensores pluviométricos para medir la precipitación y acelerómetros para detectar movimientos, integrando una aplicación con interfaces de bienvenida, visualización de mapas con ubicación de usuarios y sensores, además de un módulo de cultura preventiva con información educativa sobre cómo actuar ante estos eventos.

### Aporte del artículo al proyecto

Este trabajo aporta al proyecto **Llaqta Guardian** una referencia aplicada sobre la integración de sensores ambientales y aplicaciones móviles como herramientas de alerta temprana ante fenómenos naturales. Asimismo, refuerza la importancia de complementar la detección técnica del riesgo con componentes de información y educación preventiva dirigidos a la población, fortaleciendo el nivel usuario del sistema.

El enfoque del estudio demuestra la viabilidad de sistemas de alerta temprana adaptables a distintos fenómenos de riesgo, respaldando la escalabilidad y aplicabilidad del proyecto propuesto.

---

## Artículo 2: Monitoreo de inundaciones mediante análisis hidrológico y definición de umbrales de alerta temprana en cuencas tropicales secas

### Resumen del artículo

La investigación aborda el monitoreo de inundaciones en cuencas tropicales secas, como el río Tumbes, donde existen limitaciones en el monitoreo hidrológico convencional y escasez de información continua durante eventos extremos.

Para enfrentar esta problemática, se desarrolló un marco metodológico que integra el análisis de series temporales hidrológicas y la evaluación de umbrales de alerta temprana, permitiendo identificar la dinámica de las inundaciones y establecer relaciones entre el caudal del río y los impactos generados.

El análisis de eventos hidrológicos entre 2017 y 2024 permitió determinar niveles críticos de activación de alertas, validados mediante reportes oficiales de daños, demostrando la utilidad del enfoque para la gestión del riesgo.

### Aporte del artículo al proyecto

Este trabajo aporta al proyecto **Llaqta Guardian** un enfoque metodológico para la definición y validación de umbrales de alerta temprana a partir de la relación entre variables hidrológicas y niveles de afectación.

Aunque el proyecto no emplea imágenes satelitales ni técnicas de teledetección, el estudio respalda la importancia de vincular mediciones cuantitativas con impactos reales para mejorar la precisión de las alertas, optimizar la toma de decisiones y fortalecer la confiabilidad del sistema.

---

## Artículo 3: Proyecto PREVENIR para el fortalecimiento de sistemas de alerta temprana de inundaciones urbanas

### Resumen del artículo

El artículo presenta los avances del Proyecto PREVENIR, una iniciativa de cooperación entre Argentina y Japón orientada a fortalecer los sistemas de alerta temprana de inundaciones urbanas mediante la mejora en la estimación y pronóstico de precipitaciones intensas.

El estudio integra la expansión y calibración de redes pluviométricas, control de calidad de datos hidrometeorológicos y desarrollo de productos avanzados para la estimación cuantitativa de la lluvia y su predicción a corto plazo.

Asimismo, incorpora modelos determinísticos, probabilísticos y técnicas de aprendizaje automático para mejorar la anticipación de eventos extremos, validándose mediante un caso de estudio real.

### Aporte del artículo al proyecto

Este artículo aporta al proyecto **Llaqta Guardian** un enfoque integral para fortalecer sistemas de alerta temprana mediante la integración de múltiples fuentes de datos, validación de información y definición de umbrales de alerta.

Aunque el proyecto no utiliza sensores remotos ni técnicas avanzadas de predicción, el estudio respalda la importancia de contar con datos confiables, procesos de validación y análisis previo a la emisión de alertas, contribuyendo a mejorar la precisión y confiabilidad del sistema.

---

## Artículo 4: Sistema de monitoreo y alerta temprana de inundaciones basado en tecnología LoRaWAN

### Resumen del artículo

El estudio presenta un sistema de monitoreo y alerta temprana de inundaciones (FMWS) basado en tecnología LoRaWAN, diseñado para ofrecer amplia cobertura de comunicación, bajo consumo energético y transmisión eficiente de datos.

El sistema emplea un sensor ultrasónico HC-SR04 integrado a un microcontrolador Arduino para medir en tiempo real el nivel del agua y sus variaciones, clasificando el estado de riesgo en diferentes niveles.

La información recopilada se transmite mediante una red LoRaWAN hacia plataformas IoT y paneles web, permitiendo la visualización y seguimiento continuo. El sistema funciona de manera autónoma mediante energía solar y fue validado en escenarios reales, demostrando su eficacia y posibilidad de expansión con múltiples nodos de monitoreo.

### Aporte del artículo al proyecto

Este estudio aporta al proyecto **Llaqta Guardian** una referencia técnica directa sobre la implementación de sistemas de alerta temprana basados en LoRaWAN, sensores de nivel y arquitecturas de bajo consumo energético.

Asimismo, respalda el uso de nodos autónomos y escalables para el monitoreo distribuido de condiciones hidrológicas, fortaleciendo el diseño del sistema propuesto en términos de eficiencia energética, confiabilidad en la transmisión de datos y capacidad de emitir alertas oportunas ante escenarios de riesgo.

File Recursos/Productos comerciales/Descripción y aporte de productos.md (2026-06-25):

# Productos de Referencia

## Producto 1: SensiFlood EVX2000B-FSN

### Resumen del producto

SensiFlood EVX2000B-FSN es un sistema autónomo de monitoreo y detección de inundaciones diseñado para aplicaciones ambientales y de alerta temprana. Integra sensores de nivel de agua mediante tecnologías ultrasónicas, radar y transductores de presión, además de incorporar sensores complementarios como pluviómetros, GPS y sensores de temperatura.

El sistema permite la comunicación mediante redes celulares, satélite, LoRaWAN y WiFi, además del almacenamiento de datos y monitoreo en tiempo real mediante una plataforma en la nube.

### Aporte del producto al proyecto

Este producto aporta al proyecto **Llaqta Guardian** una referencia para la integración de múltiples sensores dentro de una plataforma inteligente de monitoreo. Además, proporciona una base para el desarrollo de sistemas autónomos alimentados mediante energía solar y con capacidad de monitoreo remoto, permitiendo mejorar la detección del incremento del nivel del río y optimizar la generación de alertas tempranas para comunidades vulnerables.

---

## Producto 2: Vantage Flood Station (AEM)

### Resumen del producto

Vantage Flood Station es un sistema de detección y advertencia de inundaciones que permite monitorear continuamente el incremento del nivel del agua y emitir alertas automáticas en tiempo real. Su propósito principal es aumentar la seguridad pública mediante la detección rápida de situaciones peligrosas, reduciendo la necesidad de supervisión manual y permitiendo una respuesta inmediata ante posibles eventos de inundación.

### Aporte del producto al proyecto

Este producto aporta al proyecto **Llaqta Guardian** un modelo de funcionamiento basado en alertas automáticas y monitoreo continuo de variables hidrológicas. Su diseño sirve como referencia para implementar un sistema capaz de disminuir la dependencia de la supervisión humana y emitir advertencias oportunas a la población frente al aumento del nivel del río.

---

## Producto 3: OTT Flood Monitoring System (OTT FMS)

### Resumen del producto

OTT Flood Monitoring System es un sistema integrado para el monitoreo de inundaciones y crecimiento de ríos que utiliza sensores radar sin contacto para medir el nivel del agua con alta precisión. El sistema incorpora registradores de datos, comunicación inalámbrica y alimentación mediante batería o paneles solares, permitiendo un monitoreo continuo y remoto de las condiciones hidrológicas.

### Aporte del producto al proyecto

Este producto aporta al proyecto **Llaqta Guardian** una referencia tecnológica para la implementación de sensores de medición sin contacto y sistemas de monitoreo remoto de alta precisión. Asimismo, su integración con fuentes de energía autónoma y transmisión de datos contribuye al diseño de un sistema confiable para detectar el crecimiento de los ríos y generar alertas tempranas en zonas vulnerables.

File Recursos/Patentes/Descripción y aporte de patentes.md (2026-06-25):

# Patentes Relacionadas

## Patente 1: Método de alerta temprana de inundaciones en áreas rurales basado en la precipitación antecedente y la relación topológica aguas arriba–aguas abajo

### Resumen de la patente

La patente propone un método de alerta temprana de inundaciones para zonas rurales que considera tanto la precipitación antecedente como la relación hidrológica entre las áreas ubicadas aguas arriba y aguas abajo de una cuenca. Para ello, corrige progresivamente los datos de lluvia registrados, evaluando la influencia de eventos previos y el efecto acumulativo del flujo de agua dentro de la cuenca. Este procedimiento permite realizar una evaluación dinámica del riesgo y mejorar la precisión de las alertas tempranas frente a posibles inundaciones.

### Aporte de la patente al proyecto

Esta patente aporta al proyecto LLAQTA GUARDIAN una base metodológica para el análisis del riesgo de inundaciones mediante la integración de múltiples variables hidrológicas. Su enfoque fortalece la generación de alertas tempranas más precisas, permitiendo una mejor evaluación de las condiciones de riesgo y contribuyendo a la toma de decisiones oportunas para la prevención de desastres en comunidades vulnerables.

---

## Patente 2: Sistema de alerta temprana de inundaciones basado en análisis de Big Data

### Resumen de la patente

La patente presenta un sistema de alerta temprana que utiliza tecnologías de Big Data para recopilar, transmitir y procesar información en tiempo real mediante sensores distribuidos. A partir del análisis de grandes volúmenes de datos, el sistema puede predecir eventos de inundación, emitir alertas oportunas a través de diversos canales de comunicación y apoyar la gestión de emergencias. Su implementación mejora la rapidez y precisión de las alertas, reduciendo los impactos generados por estos eventos.

### Aporte de la patente al proyecto

Esta patente aporta al proyecto LLAQTA GUARDIAN el concepto de monitoreo continuo y procesamiento de datos para la detección temprana de riesgos. Además, respalda la importancia de utilizar información en tiempo real para mejorar la capacidad de respuesta ante inundaciones. Asimismo, evidencia la necesidad de adaptar estas tecnologías a contextos rurales y de limitada conectividad, aspecto que constituye uno de los principales enfoques del proyecto.

---

## Patente 3: Método de predicción de inundaciones fluviales mediante identificación de puntos de desbordamiento

### Resumen de la patente

La patente describe un método de predicción de inundaciones fluviales que permite identificar de manera temprana los puntos de desbordamiento de un río durante eventos de lluvia. El procedimiento contempla una etapa de preparación y otra de monitoreo continuo, mediante las cuales se determina la probabilidad de ocurrencia de una inundación y el tiempo estimado antes de que esta suceda. Gracias a la observación constante del comportamiento del cauce, el sistema mejora la precisión en la detección de situaciones de riesgo.

### Aporte de la patente al proyecto

Esta patente aporta al proyecto LLAQTA GUARDIAN un enfoque orientado a la identificación temprana de puntos críticos de desbordamiento y al monitoreo continuo de las condiciones del río. Aunque el proyecto no utiliza video en tiempo real, adopta el principio de seguimiento constante del comportamiento hídrico para establecer umbrales de riesgo, fortalecer la lógica de las alertas tempranas y mejorar la anticipación ante posibles inundaciones.

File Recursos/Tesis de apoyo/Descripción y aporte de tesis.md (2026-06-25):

## Tesis 1: Sistema automático de alerta temprana mediante sensores de nivel y tecnología LoRa para prevención de desbordes en canales de riego en Jayanca, Lambayeque

### Resumen de la tesis

La tesis tiene como objetivo implementar un sistema automático de alerta temprana para prevenir desbordes en canales de riego del distrito de Jayanca, Lambayeque, mediante el uso de sensores de nivel de agua y tecnología de comunicación LoRa. La investigación es de tipo aplicada y contempla el diagnóstico técnico y social de los canales, la identificación de puntos críticos de desborde, el diseño de nodos de monitoreo y la validación del sistema. El prototipo desarrollado permitió medir el nivel del agua en tiempo real, clasificar estados de riesgo y emitir alertas visuales y sonoras, logrando una transmisión de datos estable y continua hacia una estación central.

### Aporte de la tesis al proyecto

Esta tesis aporta a LLAQTA GUARDIAN una base técnica sólida para el diseño del sistema de monitoreo, especialmente en el uso de sensores de nivel, microcontroladores y tecnologías de comunicación inalámbrica de bajo consumo como LoRa. Además, justifica la eficacia de los sistemas automáticos de alerta temprana en contextos rurales, fortaleciendo el dominio electrónico y la confiabilidad del sistema propuesto, así como la viabilidad de su implementación en escenarios reales de riesgo.

---

## Tesis 2: Implementación de un sistema de alerta temprana como soporte a la prevención, atención de incidentes y ejecución de planes de contingencia frente a desbordes en el río La Leche, Lambayeque

### Resumen de la tesis

La tesis propone la implementación de un sistema de alerta temprana orientado a apoyar la prevención, atención de incidentes y ejecución de planes de contingencia frente a desbordes del río La Leche en el departamento de Lambayeque. El estudio emplea un enfoque cuantitativo y una metodología tipo SCADA, integrando hardware, algoritmos de predicción y plataformas de información para alertar a la población y autoridades. Los resultados demostraron que el sistema permitió mejorar la capacidad de respuesta ante desbordes, logrando que más del 90 % de la población evaluada evacúe oportunamente y ejecute planes de contingencia de manera eficiente.

### Aporte de la tesis al proyecto

Esta tesis contribuye al proyecto LLAQTA GUARDIAN desde el enfoque de ingeniería, aportando criterios para la gestión de la información, la toma de decisiones y la interacción con los usuarios finales. Asimismo, refuerza la importancia del sistema de alerta temprana como herramienta de apoyo a la prevención y gestión del riesgo, fortaleciendo el nivel usuario, la estructura funcional del sistema y el impacto social del proyecto.

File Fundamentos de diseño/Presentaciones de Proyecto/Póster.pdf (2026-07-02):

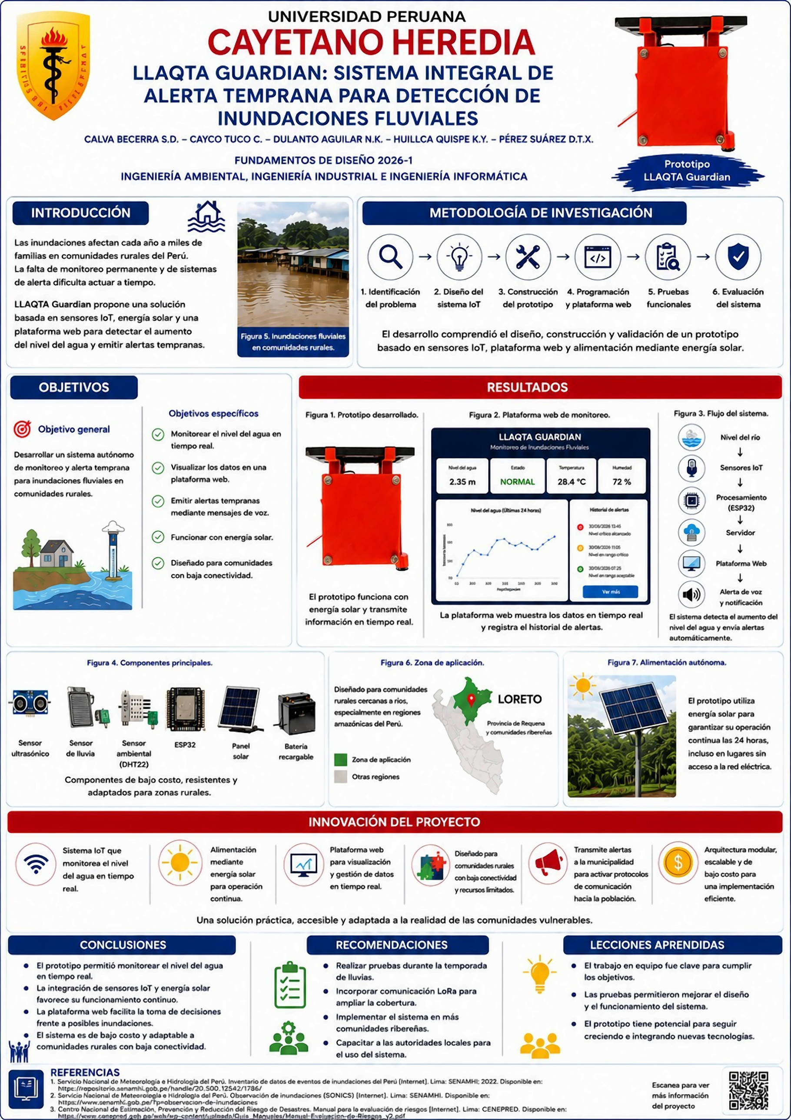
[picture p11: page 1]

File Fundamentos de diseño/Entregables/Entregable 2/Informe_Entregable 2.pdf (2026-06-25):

## UNIVERSIDAD PERUANA CAYETANO HEREDIA

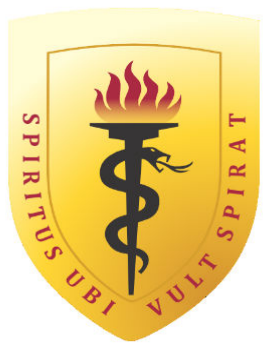
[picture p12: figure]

## FACULTAD DE CIENCIAS E INGENIERÍA

## LLAQTA GUARDIAN: Sistema integral de alerta temprana comunitaria para detección de inundaciones fluviales

INFORME TÉCNICO

### Curso: Fundamentos de Diseño

Integrantes - E14:

Calva Becerra, Sofia Dayanna Cayco Tucto, Caleb
Dulanto Aguilar, Nemesis Krystel Huillca Quispe, Kevin Yandel Perez Suarez, Doménica Tiziana Ximena

Docentes:

Contreras Paucca, Jhomer Rodrigo Huanambal Sovero, Victor Alberto Mugaburu Celi, Marco Antonio

2026

CONTENIDO

1. Introducción
2. Problemática
3. Estado de la tecnología
3.1 Tecnología existente en el ámbito comercial 3.2 Tecnología existente en el ámbito de patentes 3.3 Factores comunes en el estado del arte 3.3.1 Artículos ciéntificos
3.3.2 Tesis de repositorios
4. Lista de exigencias
5. Estructura de Funciones 5.1 Caja negra (Black Box) 5.1.1 Entradas
5.1.2 Salidas
5.2 Secuencia de Operaciones 5.2.1 Nivel usuario
5.2.2 Nivel dispositivo
5.3 Estructura de Funciones 5.3.1 Dominio Electrónico
5.3.2 Dominio Mecánico
5.3.3 Dominio de Energía
5.3.4 Dominio de Control
5.3.5 Dominio de Software
6. Concepto de solución por Dominio
6.1 Matriz morfológica del dominio electrónico
6.1.1 Disposición básica de soluciones del dominio electrónico 6.1.2 Evaluación de conceptos y selección del concepto óptimo 6.2 Matriz morfológica del dominio mecánico

6.2.1 Disposición básica de soluciones del dominio mecánico 6.2.2 Evaluación de conceptos y selección del concepto óptimo 6.3 Matriz morfológica del dominio de energía

6.3.1 Disposición básica de soluciones del dominio de energía

6.3.2 Evaluación de conceptos y selección del concepto óptimo 6.4 Matriz morfológica del dominio de control
6.4.1 Disposición básica de soluciones del dominio de control 6.4.2 Evaluación de conceptos y selección del concepto óptimo 6.5 Matriz morfológica del dominio de software
6.5.1 Disposición básica de soluciones del dominio de software 6.5.2 Evaluación de conceptos y selección del concepto óptimo
7. Bocetos de los 3 conceptos de solución
7.1 Bocetos del Concepto de solución 1
7.2 Bocetos del Concepto de solución 2
7.3 Bocetos del Concepto de solución 3
8. Evaluación de Matriz de Pugh
8.1 Selección y explicación de los criterios técnico/económicos 8.2 Justificación de asignación de puntajes

8.2.1 Concepto de Solución 1
8.2.2 Concepto de Solución 2
8.2.3 Concepto de Solución 3
8.3 Concepto de Solución Óptimo
9. Referencias Bibliográficas

### 1. Introducción

Las inundaciones constituyen uno de los tipos de desastres naturales más frecuentes en el Perú y el mundo. Por definición oficial, las inundaciones ocurren cuando "el agua ocupa un terreno que debería estar libre"

1
, es decir, por el desborde de ríos, lluvias intensas u otros eventos hídricos que cubren zonas normalmente secas. A nivel global, la Organización Meteorológica Mundial (OMM) señala que los fenómenos relacionados con el agua, entre ellos las inundaciones, dominan la lista de desastres de las últimas décadas tanto en pérdidas humanas como económicas

2
. Según el Atlas de la OMM sobre mortalidad y pérdidas económicas debidas a fenómenos meteorológicos, climáticos e hidrológicos extremos (1970-2019), las inundaciones causaron unas 58 700 muertes en ese período a nivel mundial

2
, lo que refleja el enorme impacto humano de estos eventos. En el contexto nacional, el inventario de inundaciones del SENAMHI registra que durante el período 2003-2012 las inundaciones afectaron severamente a la población peruana, documentando miles de personas damnificadas y viviendas destruidas en todo el país

3
. Solo en 2019 se reportaron 39 fallecidos y 8 299 afectados por inundaciones en el Perú

3
. Estos datos oficiales demuestran que las inundaciones son un problema recurrente y de alta prioridad en la gestión de riesgos en el Perú.

En la Amazonía peruana, las inundaciones tienen dinámicas particulares dadas la geografía y la variabilidad climática de la región. Loreto, en la cuenca del Amazonas, recibe lluvias muy intensas anualmente y está surcada por ríos de gran caudal como el Ucayali y el Marañón. Como consecuencia, la población ribereña sufre inundaciones estacionales frecuentes. Por ejemplo, durante las lluvias registradas en marzo de 2025, más de 20 000 habitantes de las provincias de Alto Amazonas, Requena y Ucayali quedaron afectados por crecidas e inundaciones

4
. El distrito de Requena (provincia homónima) fue especialmente golpeado: el reporte oficial indica que 53 familias y 1 500 personas quedaron damnificadas por la inundación de sus viviendas

4
. Estos eventos son
parte de una variabilidad climática en la Amazonía peruana que implica la alternancia de fenómenos El Niño/La Niña y lluvias extremas, con crecidas cada vez más frecuentes de los ríos amazónicos.

El caso del distrito de Requena ejemplifica la vulnerabilidad local. Este distrito ribereño del Ucayali posee una topografía baja que facilita el desborde del río ante lluvias intensas. En eventos recientes, cada episodio inundó a cientos de hogares. De acuerdo con el Reporte Complementario N.º 5143 del INDECI, a consecuencia del incremento del caudal del río Ucayali y su desborde, 868 viviendas resultaron afectadas y 231 fueron destruidas en la provincia de Requena

5
. Estas cifras oficiales muestran que cada crecida impacta significativamente a la población y su infraestructura. Las autoridades regionales han declarado emergencias y distribuido ayuda humanitaria (albergues, insumos básicos) a los damnificados. En un territorio con alta exposición al agua, viviendas ribereñas precarias y escasas obras de defensa, este patrón evidencia que sistemas de alerta temprana locales podrían salvar vidas al ganar tiempo para la evacuación y preparación.

Ante estos daños recurrentes, el Ejecutivo ha declarado estado de emergencia en varios distritos de Loreto como Yurimaguas y Jenaro Herrera para canalizar ayuda y reforzar la prevención. Paralelamente, la Autoridad Nacional del Agua (ANA/CENEPRED) ha identificado múltiples localidades ribereñas, como Nuevo Requena y Nuevo Iquitos, en peligro inminente y con alta vulnerabilidad ante el aumento del caudal del Ucayali

7
. Más
recientemente, el SENAMHI ha avanzado en el desarrollo de sistemas de pronóstico hidrológico para la Amazonía peruana orientados a la alerta por inundaciones, reconociendo la urgencia de proteger a las comunidades ribereñas más vulnerables

6

No obstante, pese a la existencia de sistemas de monitoreo (SENAMHI, INDECI, alertas hidrológicas, entre otros), las comunidades más vulnerables han recibido avisos tardíos o inexistentes. En muchas zonas ribereñas los canales oficiales de alerta no fueron efectivos a tiempo, lo que evidencia demoras y fallas en la comunicación. Como consecuencia, estas deficiencias en el sistema de alerta agravaron el impacto de los desastres, dejando a los pobladores sin advertencias suficientes antes de las crecidas.

Por ello, el proyecto Llaqta Guardian, un sistema de alerta temprana por inundaciones en el distrito de Requena, se encuentra directamente alineado con los Objetivos de Desarrollo Sostenible (ODS) de la Agenda 2030

8
. Contribuye al ODS 6 (agua limpia y saneamiento) al proteger las fuentes de agua potable: anticipar crecidas puede prevenir la contaminación de pozos y asegurar la calidad del agua para las comunidades ribereñas. Fortalece el ODS 11 (ciudades y comunidades sostenibles) porque mejora la resiliencia ante desastres: una alerta oportuna permite reforzar viviendas, escuelas e infraestructura clave antes de que ocurra la inundación, reduciendo daños humanos y materiales. Además, apoya el ODS 13 (acción por el clima) al constituir una medida de adaptación ante fenómenos extremos vinculados al cambio climático. El proyecto combina ciencia hidrológica, tecnología de vigilancia y participación ciudadana para reducir las pérdidas humanas y los daños materiales. En síntesis, Llaqta Guardian traduce datos hidrológicos en acciones concretas de prevención local, promoviendo comunidades más seguras, un manejo sostenible del agua y una mayor preparación frente al cambio climático, en consonancia con la Agenda 2030

8

### 2. Problemática

El distrito de Requena, en Loreto, enfrenta inundaciones recurrentes provocadas por el desborde del río Ucayali. El CENEPRED identifica en la región 66 puntos críticos de inundación, casi el triple del promedio nacional, y más de 52 700 viviendas en zonas de riesgo que afectan a cerca de 211 000 personas

9
. La precariedad agrava esta exposición: 9 de cada 10 viviendas urbanas de Loreto fueron construidas entre 2007 y 2024 en

condiciones inadecuadas

9
, y la inversión pública en prevención cayó un 46% anual entre 2022 y 2025, con apenas un 23% de ejecución presupuestal en 2025

9

A esto se suma la ausencia de un sistema de alerta temprana operativo a escala local. El SENAMHI reconoce que la Amazonía peruana carece de cobertura hidrometeorológica suficiente debido a la escasez de estaciones de monitoreo

6
, y el PNUD advierte que los sistemas de alerta existentes suelen funcionar de forma aislada de las comunidades que deben proteger, neutralizando su efectividad

10
. Como resultado, cada crecida del Ucayali encuentra a Requena sin avisos oportunos: el INDECI registró 868 viviendas afectadas y 231 destruidas en junio de 2023

5
, y en marzo de 2025 más de 1 500 personas resultaron damnificadas

4

Frente a este escenario de vulnerabilidad estructural, desinversión y alertas ineficaces, Llaqta Guardian surge como una respuesta tecnológica urgente y necesaria para proteger a la población ribereña de Requena.

### 3. Estado de la tecnología

### 3.1 Tecnología existente en el ámbito comercial

a. La empresa Campbell Scientific (https://www.campbellsci.com/?utm_source=chatgpt.com) está especializada en sistemas de monitoreo ambiental, adquisición de datos y alerta temprana para aplicaciones hidrológicas y meteorológicas. Sus tecnologías se utilizan en monitoreo de ríos, calidad de agua, estaciones climáticas y sistemas de prevención de inundaciones.

Características generales :

Características principales:

- Monitoreo del nivel del agua en tiempo real.
- Sistema de alerta temprana para inundaciones.
- Transmisión inalámbrica de datos.
- Funcionamiento autónomo con panel solar y batería.
- Registro automático de datos ambientales.
- Monitoreo remoto desde estaciones de control.
- Diseño resistente para exteriores y clima extremo.

Sensores utilizados:

- Sensor de nivel de agua.
- Sensor radar de nivel.
- Sensor de presión hidrostática.
- Pluviómetro (sensor de lluvia).

- Sensores meteorológicos.
- Datalogger y módulos de comunicación inalámbrica.

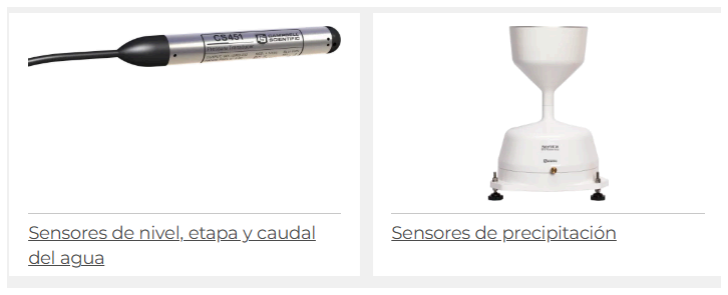
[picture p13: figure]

b. La empresa High Sierra Electronics (https://hsierra.com/?utm_source=chatgpt.com) está especializada en sistemas de monitoreo ambiental, alerta temprana y seguridad pública. Sus tecnologías se enfocan en el monitoreo de inundaciones, detección de niveles altos de agua, estaciones meteorológicas y sistemas automáticos de advertencia para comunidades vulnerables y organismos de seguridad pública.

Características principales:

- Monitoreo en tiempo real del nivel del agua y lluvias.
- Sistema automático de alerta temprana.
- Registro y transmisión de datos ambientales.
- Comunicación inalámbrica y monitoreo remoto.
- Activación de alarmas y notificaciones automáticas.
- Uso de software para análisis hidrológico y pronóstico de inundaciones.
- Funcionamiento autónomo con energía solar y baterías.
- Diseño resistente para exteriores y condiciones climáticas extremas.

Sensores utilizados:

- Sensor de nivel de agua: evalúa el aumento o disminución del nivel del río.
- Sensor de presión sumergible: mide la presión ejercida por el agua para determinar la profundidad.
- Pluviómetro: evalúa la cantidad de lluvia registrada en un periodo de tiempo.
- Sensores meteorológicos: monitorean variables ambientales como temperatura, humedad y viento.
- Módulos de comunicación inalámbrica: transmiten los datos hacia centros de monitoreo remoto.

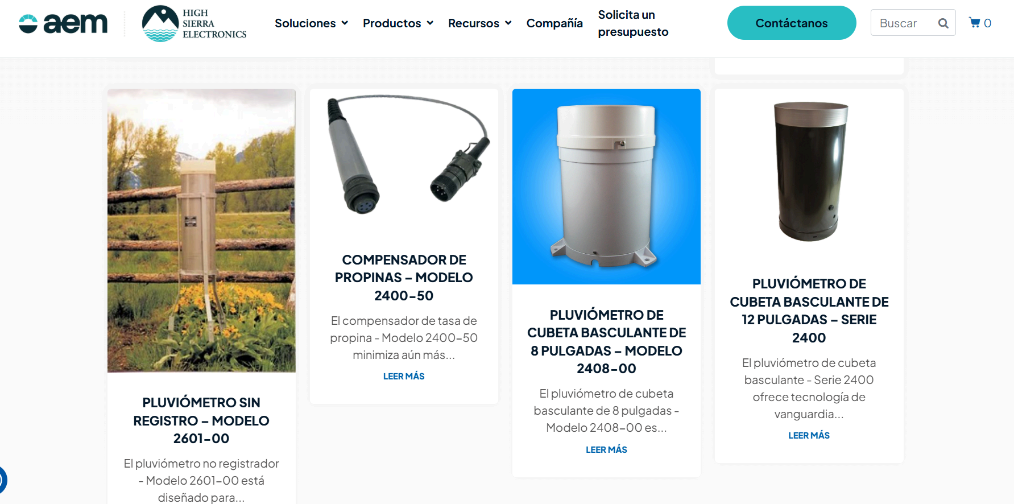
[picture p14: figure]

### 3.2 Tecnología existente en el ámbito de patentes:

MÉTODO DE ALERTA TEMPRANA DE INUNDACIONES RURALES BASADO EN PRECIPITACIONES ANTECEDENTES Y EN LA RELACIÓN TOPOLÓGICA AGUAS ARRIBA-AGUAS ABAJO

El método propone una alerta temprana de inundaciones rurales considerando dos factores clave: precipitaciones antecedentes y la relación topológica aguas arriba-aguas abajo. Primero, se vincula cada pueblo con una estación de lluvia para emitir alertas según sus registros. Luego, la medida de precipitación se corrige dos veces: la primera por influencia de lluvias previas y la segunda por el efecto acumulativo de cuencas conectadas. Así, se logra un análisis dinámico y más preciso de las condiciones de riesgo, mejorando la confiabilidad de las alertas y apoyando la prevención de inundaciones en comunidades rurales.

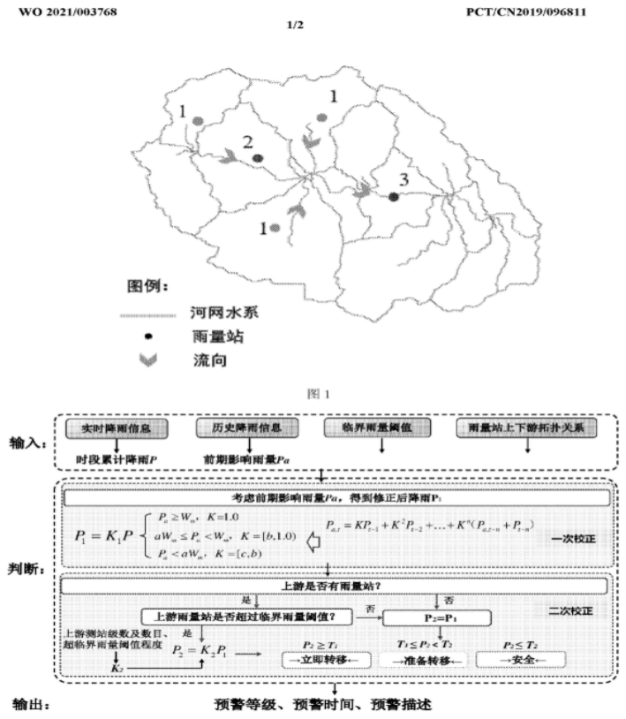
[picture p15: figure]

Link: https://worldwide.espacenet.com/patent/search?q=pn%3DWO2021003768A1

ALERTA TEMPRANA Y SISTEMA DE MONITORIZACIÓN DE INUNDACIONES URBANAS EN EL INTERIOR BASADO EN ANÁLISIS DE BIG DATA

El sistema de alerta temprana de inundaciones basado en análisis de big data se fundamenta en la recopilación, transmisión y procesamiento de datos en tiempo real mediante sensores, permitiendo predecir eventos de inundación, emitir alertas oportunas por múltiples canales y apoyar la toma de decisiones ante emergencias. Este enfoque mejora la precisión y rapidez de las alertas, reduciendo significativamente los daños ocasionados.

Su relevancia para el proyecto Llaqta Guardian radica en que valida el uso de tecnologías basadas en datos y monitoreo continuo para la prevención de desastres; Sin embargo, al estar orientado a entornos urbanos con alta conectividad, evidencia la necesidad de adaptar este tipo de soluciones a contextos rurales y de baja conectividad, como las comunidades amazónicas, donde se requiere un sistema accesible, eficiente y enfocado en la protección de la población vulnerable

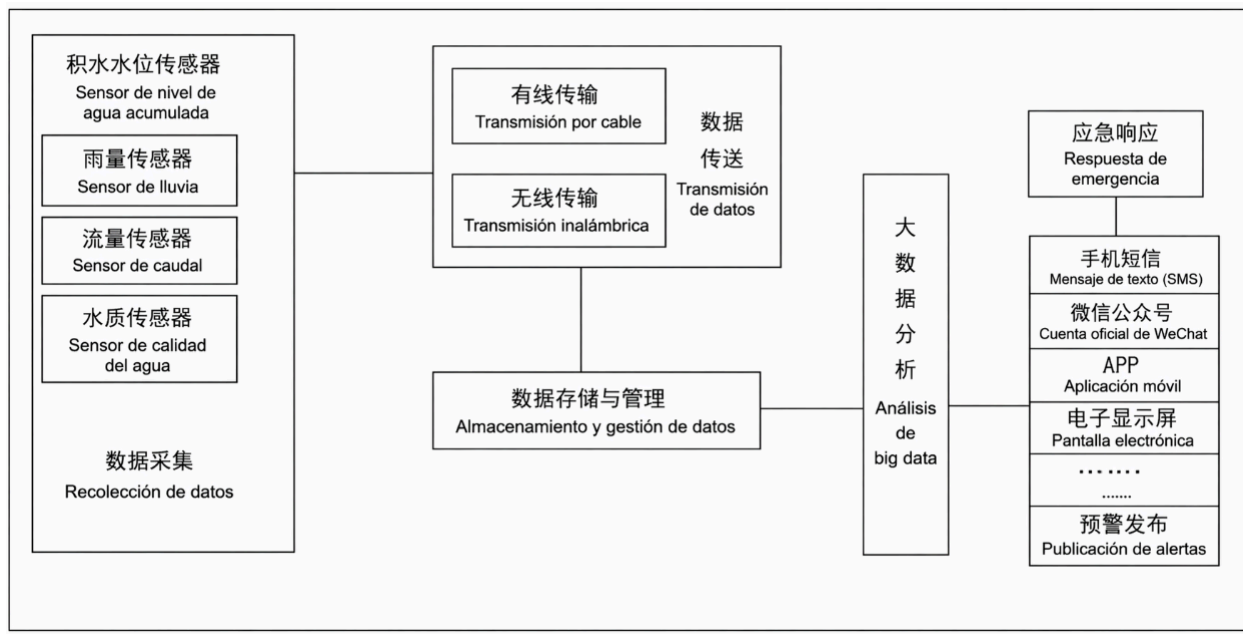
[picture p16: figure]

link: https://worldwide.espacenet.com/patent/search?q=pn%3DCN119181208A

MÉTODO DE PREDICCIÓN DE INUNDACIONES FLUVIALES

La invención propone un método de predicción de inundaciones fluviales basado en la observación en tiempo real mediante vídeo. Incluye un paso de preparación y un paso de identificación del lugar de desbordamiento, que determina si la lluvia provocará una crecida o cuánto tiempo resta antes de la inundación. El proceso se repite durante la lluvia, permitiendo localizar dinámicamente los puntos de desbordamiento entre las partes aguas arriba y aguas abajo del río, mejorando la precisión frente a métodos convencionales.

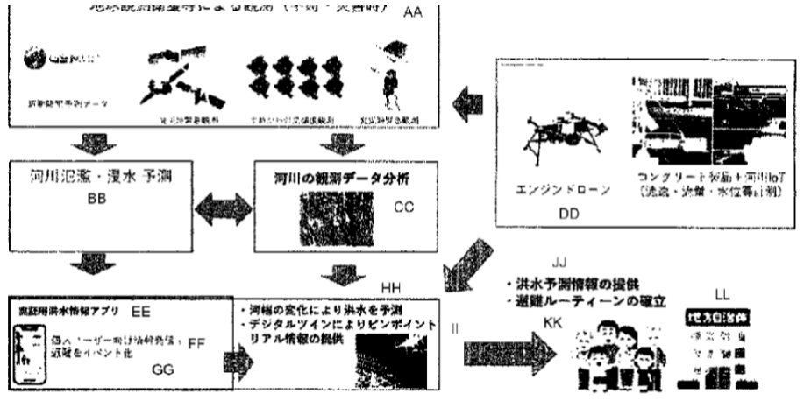
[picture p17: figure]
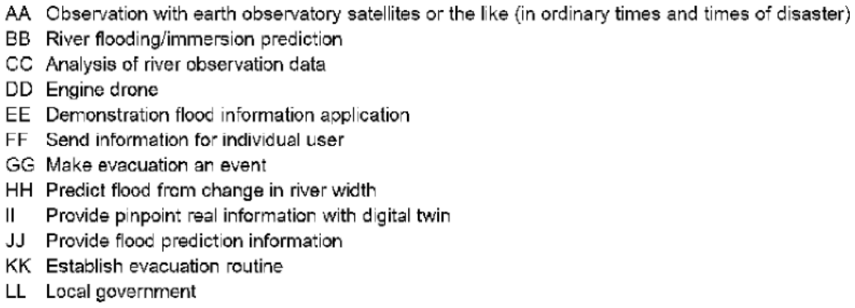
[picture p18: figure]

link: https://worldwide.espacenet.com/patent/search?q=pn%3DWO2023276383A1

### 3.3 Factores comunes en el estado del arte

### 3.3.1 Artículos científicos

N° | Fuente | Autor/Institución | Año | Referencias | Estado de tecnología encontrado | Exigencia o requisito identifica do | Restricció n o limitación | Función Principal | Aplicació al proyecto
1 | Artículo científico | Luciano Vidal, Maite Cancelada, Daichi Kitahara, Martin Rugna, Paul Fernández Chomik, Maria Paula Hobouchian, Gonzalo Díaz, Sergio González, Ezequiel Geslin, Aldana Arruti, Leandro Axel Aguirre, Juan Ruiz, Pablo Negri, Manuel Pulido, Paola Salio y Tomoo Ushio | 2025 | https://cenamet.org.ar/congremet/wp-content/uploads/2025/11/A2_T127. pdf | Tecnología basada en sensores remotos, radares meteorológico s, estaciones pluviométrica s y modelos de aprendizaje automático para monitoreo de precipitación | -Integraci ón de redes pluviomét ricas. -Calibraci ón y validación de datos. -Uso de algoritmo s de machine learning y nowcastin g. | -Necesita redes densas de sensores. -Depende ncia de calidad de datos meteoroló gicos. -Procesam iento complejo y alto volumen de datos. | Monitore ar y predecir precipita ciones en tiempo real mediante sensores remotos y modelos inteligent es. | Servir como base para implementar monitoreo ambiental inteligente y sistemas de alerta temprana en el proyecto.
2 | Artículo científico | Muhammad Izzat Zakaria, Waheb A. Jabbar y Noorazliza Sulaiman | 2023 | https://www. sciencedirec t.com/scienc e/article/pii/ S266734522 3000263 | Sistema IoT basado en LaRaWAN con sensores ultrasónicos HC‑SR04 y Arduino para monitoreo de inundaciones | -Conexión LaRaWA N. -Uso de sensores ultrasónic os. -Microcon trolador Arduino y plataform as IoT. -Alimenta ción energética estable. | -Depende de la cobertura y conectivid ad LaRaWA N. -Puede verse afectado por condicion es climáticas extremas. -Requiere mantenimi ento de sensores y gateway. | Detectar y monitore ar niveles de agua en tiempo real y generar alertas temprana s de inundaci ón. | Fundamentar el uso de sensores IoT y comunicación inalámbrica para automatizar el monitoreo y envío de alertas en el proyecto.

### 3.3.2 Tesis de repositorios

Sistema automático de alerta temprana mediante sensores de nivel y tecnología LoRa para prevención de desbordes en canales de riego en Jayanca, Lambayeque – 2025

Este trabajo presenta el diseño e implementación de un sistema automático de alerta temprana basado en Internet de las Cosas (IoT) para prevenir desbordes en canales de riego del distrito de Jayanca, Lambayeque. El sistema utiliza sensores de nivel de agua conectados a módulos de comunicación LoRa, permitiendo la transmisión de datos a largas distancias con bajo consumo energético. La información recolectada es enviada a una plataforma de monitoreo donde se visualizan los niveles del canal en tiempo real y se generan alertas automáticas ante posibles incrementos peligrosos del caudal. El objetivo principal es reducir riesgos de inundación y mejorar la gestión hídrica mediante monitoreo remoto y tecnología inalámbrica.

Fuente:
Sistema automático de alerta temprana mediante sensores de nivel y tecnología LoRa para prevención de desbordes en canales de riego en Jayanca, Lambayeque – 2025 [tesis para optar el título profesional]. Lambayeque (PE): Universidad Nacional Pedro Ruiz Gallo; 2025. Disponible en:
https://repositorio.unprg.edu.pe/handle/20.500.12893/16329

### 4. Lista de Exigencias

LISTA DE EXIGENCIAS

Páginas 4

Edición: Rev 2.0

PROYECTO:

Llaqta Guardian: Sistema de alerta temprana comunitario para la detección de inundaciones fluviales en zonas rurales amazónicas.

Fecha: 23/04/2026

Revisado:

CLIENTE: | Profesores del curso de Fundamentos de Diseño | Elaborado: Equipo 14 FdD: - Doménica - Sofía - Nemesis - Caleb - Kevin
Fecha | Deseo o Exigencia | DESCRIPCIÓN | Responsable
(cambios)
29/04/2026 | E

FUNCIÓN PRINCIPAL:

Todos

El sistema monitorea el nivel del agua, intensidad de lluvia y estado de boyas, activando automáticamente una alerta sonora y visual cuando se supera un umbral crítico, sin depender de internet o señal móvil.

29/04/2026 | E | GEOMETRÍA: El módulo electrónico presenta dimensiones máximas de 300x200x150 mm (LxAxP), definidas tomando como referencia sistemas de monitoreo de nivel 11, 12 de agua . | Nemesis
| E | El sistema está diseñado para instalarse en la ribera del río anclado, con sensores hacia las variables a medir.
29/04/2026 | E | CINEMÁTICA: No aplica
29/04/2026 | E | FUERZAS: El sistema tiene un peso total máximo de 5 kg permitiendo su transporte manual y facilitando su instalación, asegurando estabilidad estructural en la ribera del 13 río . | Caleb
29/04/2026 | E | MATERIA: No aplica
29/04/2026 | E | ENERGÍA: El sistema funciona principalmente con una fuente de energía eléctrica externa, que alimenta el equipo y recarga una batería para asegurar su funcionamiento continuo. Además, cuenta con un panel solar como apoyo, que ayuda a mantener la batería cargada y aumentar su autonomía. | Kevin
29/04/2026 | E | SEÑALES: Entradas: ● Señal de nivel de agua mediante sensor ultrasónico. | Todos
| E | ● Señal de detección de lluvias mediante sensor de lluvia

29/04/2026 | E | ● Señal discreta de nivel mediante boyas eléctricas.
| E | ● Señal de encendido/apagado del sistema. Salidas:
| E | ● Señal de nivel de alerta
29/04/2026 | E | CONTROL: El sistema define al menos dos niveles de alerta (preventivo y crítico) y activa la alerta al superar el umbral crítico definido . | Sofía
| E | El sistema disminuye falsas alarmas mediante validación de mediciones continuas.
29/04/2026 | E | ELECTRONICA (Hardware) El sistema emplea sensores como el ultrasónico para la medición del nivel del agua, un sensor de lluvia para la detección de precipitación y sensores tipo boya para niveles discretos. Estos son gestionados por un microcontrolador ESP32 encargado de la adquisición y procesamiento de datos. | Kevin
| E | El sistema incluye módulo de activación de sirena y luces.
29/04/2026 | E | SOFTWARE: El sistema procesa datos en tiempo real y ejecuta lógica de alerta. | Sofía
| E | El sistema puede almacenar datos históricos de medición.
29/04/2026 | E | COMUNICACIONES: La alerta se transmite mediante señales físicas (luz y sonido). | Sofía
| E | El sistema no depende de internet ni red móvil. | Kevin

SEGURIDAD:

29/04/2026 | E

El sistema no representa riesgo eléctrico
para los usuarios.

Kevin

E | El sistema resiste contacto continuo con agua, lluvia intensa y humedad. | Nemesis
29/04/2026 | E | ERGONOMÍA: El sistema es fácil de interpretar por cualquier miembro de la comunidad. | Doménica
| E | La alerta es claramente identificable mediante sonido y luz.
29/04/2026 | E | FABRICACIÓN: Materiales resistentes a humedad, corrosión y ambiente amazónico. | Némesis
| E | El sistema cuenta con sellado contra ingreso de agua (IP65 o superior). | Caleb
29/04/2026 | E | CONTROL DE CALIDAD: El sistema garantiza una medición confiable del nivel de agua. | Caleb
| E | El sistema es probado para asegurar correcta activación de alertas. | Doménica
29/04/2026 | E | MONTAJE: El sistema debe instalarse en la ribera del río mediante un mecanismo de anclaje estable. | Némesis
| E | El sistema debe evitar interferencias con el flujo del agua y asegurar estabilidad. | Kevin
29/04/2026 | E | TRANSPORTE: El sistema puede ser transportado manualmente por una persona (peso ≤ 5 kg) 13 . | Caleb
29/04/2026 | E | USO: El sistema está diseñado para operar cerca a ríos. | Doménica
| E | El sistema funciona en condiciones de alta humedad (>90%) y lluvias intensas. | Kevin
| E | El sistema opera en temperatura de 0°C a 50°C. | Sofía

29/04/2026 | E | MANTENIMIENTO: El sensor debe limpiarse periódicamente para asegurar medición. | Caleb
| E | El sistema permite una verificación sencilla del estado de la batería. | Kevin
| D | Puede incluir indicadores de diagnóstico. | Caleb
29/04/2026 | E | COSTOS: El costo total de fabricación del sistema asciende a S/ 1,800. Este monto se desglosa en S/. 800 a materiales y S/. 1,000 en mano de obra, calculados sobre la base de 20 horas hombre con una tarifa de S/. 50 por hora. | Todos
29/04/2026 | E | PLAZOS: La entrega del sistema funcional está programada para el 2 de julio de 2026, correspondiente a la semana 16 del calendario UPCH | Todos

### 5. Estructura de Funciones

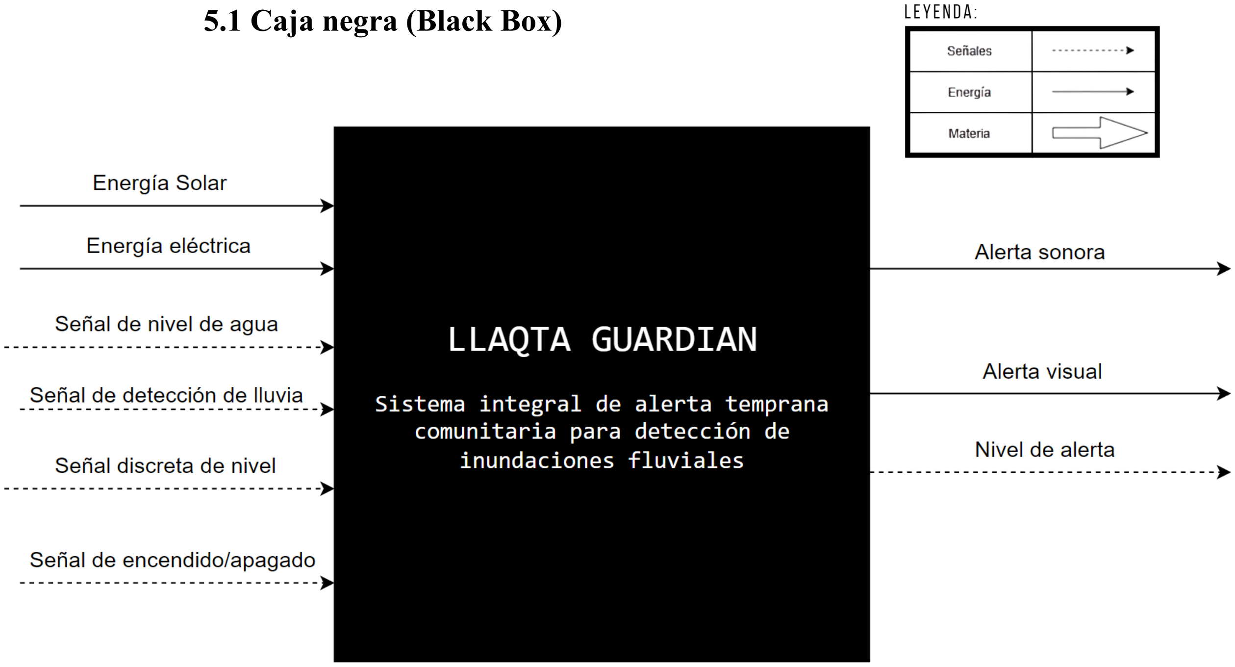
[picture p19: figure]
5.1 Caja negra (Black Box)

Caja negra de Llaqta Guardian

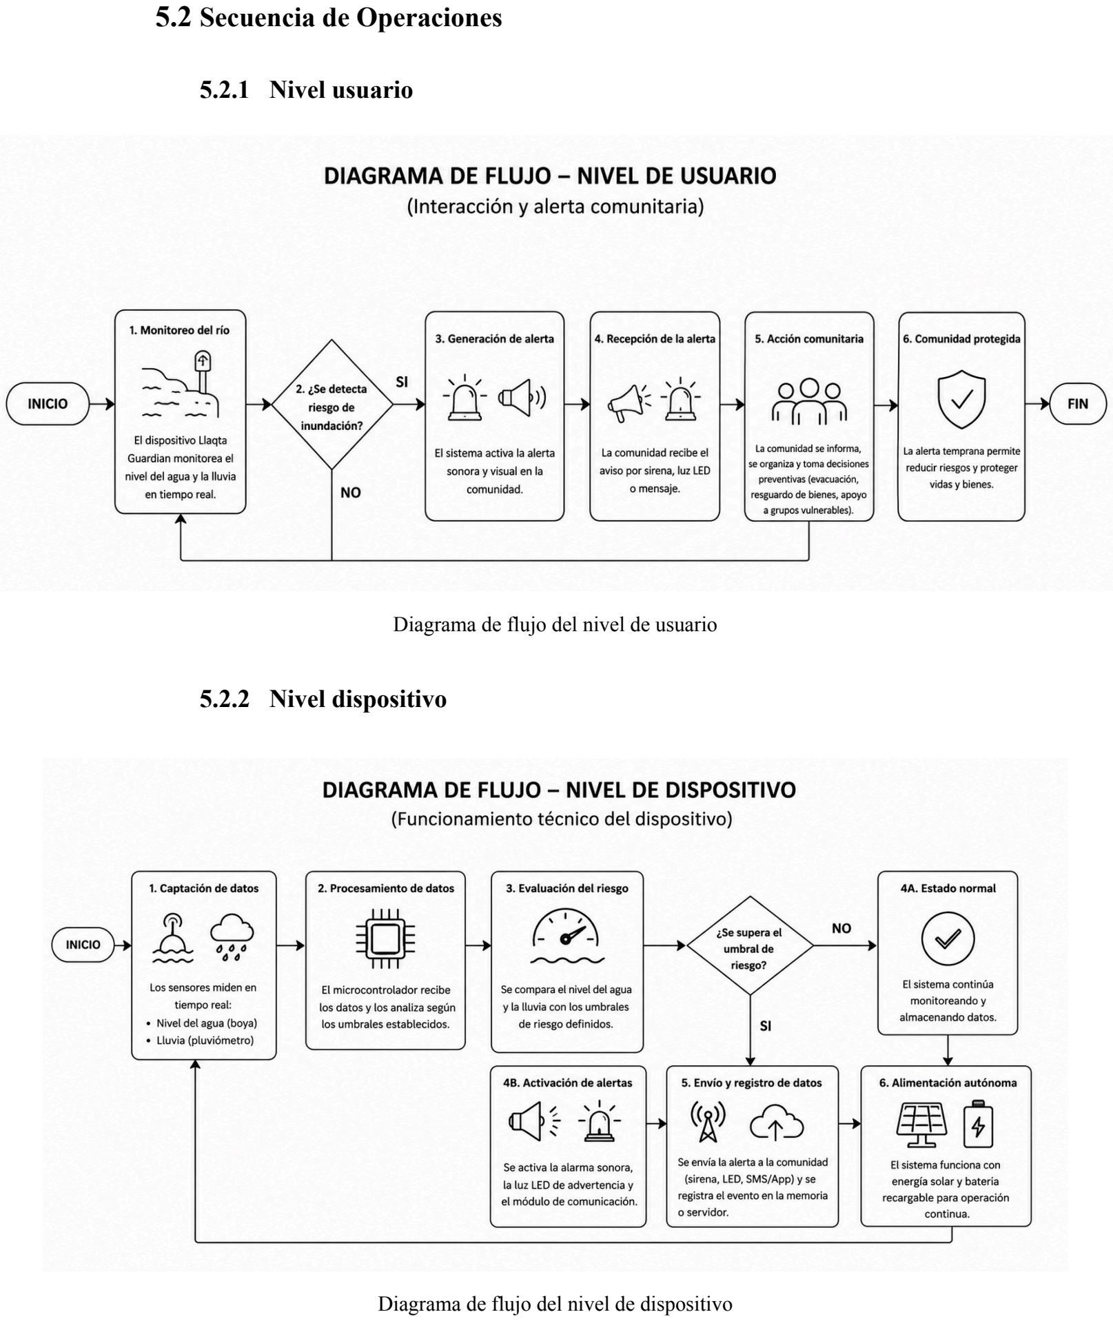
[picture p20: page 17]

### 5.2 Secuencia de Operaciones

### 5.2.1 Nivel usuario

Diagrama de flujo del nivel de usuario

### 5.2.2 Nivel dispositivo

Diagrama de flujo del nivel de dispositivo

### 5.3 Estructura de Funciones

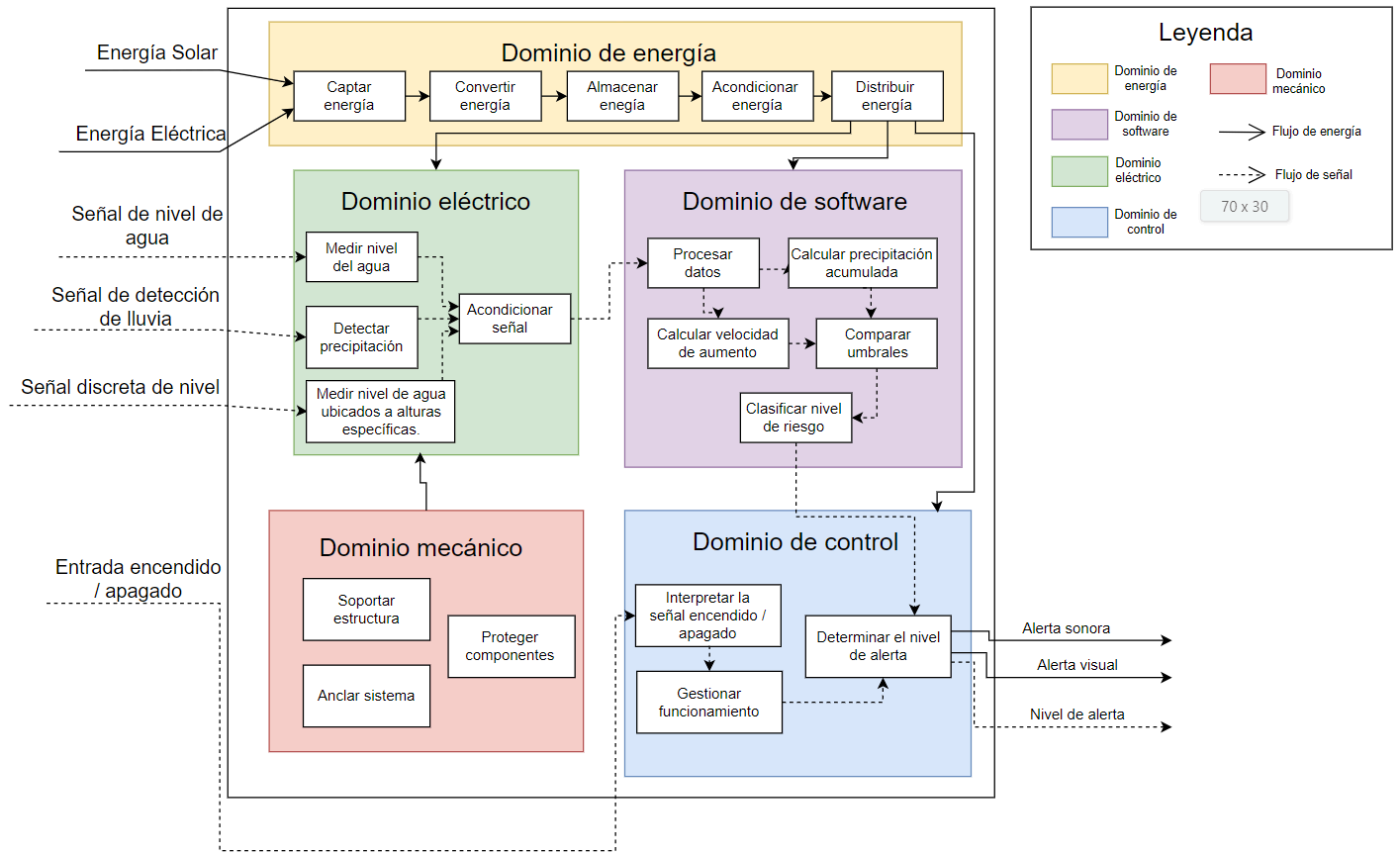
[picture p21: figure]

Figura 6: Estructura de Funciones (Caja Blanca)

### 6. Concepto de solución por Dominio

En esta sección se detallan las soluciones técnicas seleccionadas para cada uno de los dominios que integran el sistema “Llaqta Guardian”. Asimismo, se justifica la elección de cada tecnología considerando criterios de precisión, estabilidad, consumo energético, facilidad de implementación y resistencia ambiental para su funcionamiento en zonas ribereñas.

6.1 Matriz morfológica del dominio electrónico.

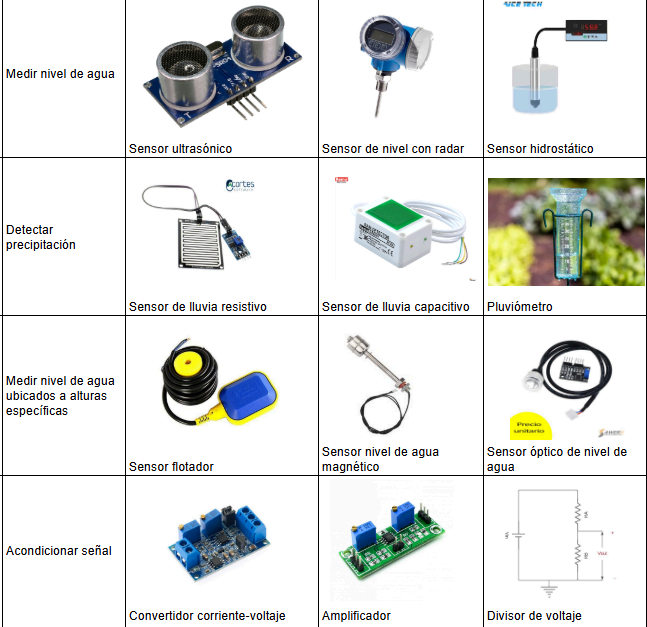
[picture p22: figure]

### 6.1.1 Disposición básica de soluciones del dominio electrónico

La solución parcial 1 emplea un sensor ultrasónico para medir el nivel del agua, un sensor de lluvia resistivo para detectar precipitaciones y un sensor flotador para identificar niveles críticos. El acondicionamiento de señal se realiza mediante un divisor de voltaje y el procesamiento principal mediante un ESP32.
Asimismo, el análisis de datos utiliza la diferencia entre lecturas y suma de pulsos para determinar el comportamiento del nivel del agua y la precipitación acumulada. Esta solución prioriza simplicidad y bajo costo de implementación.

La solución parcial 2 utiliza un sensor ultrasónico para medir el nivel del agua, un sensor de lluvia capacitivo y un sensor magnético para detección discreta de niveles. El acondicionamiento de señal se realiza mediante un amplificador y el procesamiento mediante un ESP32.

Además, el análisis de datos emplea tasa de cambio por intervalo y acumulación por intervalos, junto con umbrales con histéresis para reducir falsas alarmas y mejorar la estabilidad del sistema.

La solución parcial 3 emplea un sensor radar para medición del nivel, un pluviómetro para detección de lluvia y un sensor óptico para detección de niveles específicos. El acondicionamiento de señal utiliza un convertidor corriente-voltaje y el procesamiento se realiza mediante un ESP8266.
Asimismo, incorpora derivada aproximada e integración en el tiempo para realizar un análisis más avanzado del comportamiento hidrológico.

### 6.1.2 Evaluación de conceptos y selección del concepto óptimo

La solución parcial 1 presenta bajo costo y facilidad de implementación, sin embargo, algunos sensores pueden verse afectados por la humedad y condiciones ambientales adversas.
La solución parcial 3 ofrece mayor capacidad de análisis y automatización, aunque incrementa considerablemente la complejidad y el costo del sistema.
Por otro lado, la solución parcial 2 representa un mejor equilibrio entre precisión, estabilidad y viabilidad de implementación. Además, el sensor ultrasónico y el sensor capacitivo proporcionan mediciones confiables y permiten un adecuado funcionamiento del sistema en ambientes exteriores.
Por ello, se selecciona la solución parcial 2 como alternativa óptima para el dominio electrónico.

### 6.2 Matriz morfológica del dominio mecánico

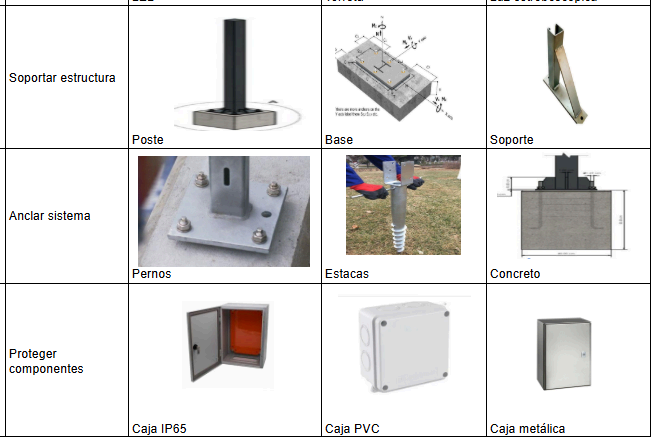
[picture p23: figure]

### 6.2.1 Disposición básica de soluciones del dominio mecánico

- La solución parcial 1 utiliza postes metálicos como estructura principal, anclajes mediante pernos y cajas PVC para protección básica de los componentes electrónicos.
- La solución parcial 2 emplea una base estructural reforzada, anclajes mediante estacas y una caja IP65 para mejorar la protección frente a lluvia, humedad y polvo.
- La solución parcial 3 incorpora soportes metálicos reforzados, cimentación de concreto y cajas metálicas para proporcionar mayor resistencia estructural y protección ambiental.

### 6.2.2 Evaluación de conceptos y selección del concepto óptimo

- La solución parcial 1 ofrece facilidad de instalación y bajo costo, aunque presenta menor protección frente a ambientes húmedos.
- La solución parcial 3 proporciona alta resistencia estructural, pero incrementa considerablemente el peso, complejidad y costo del sistema.

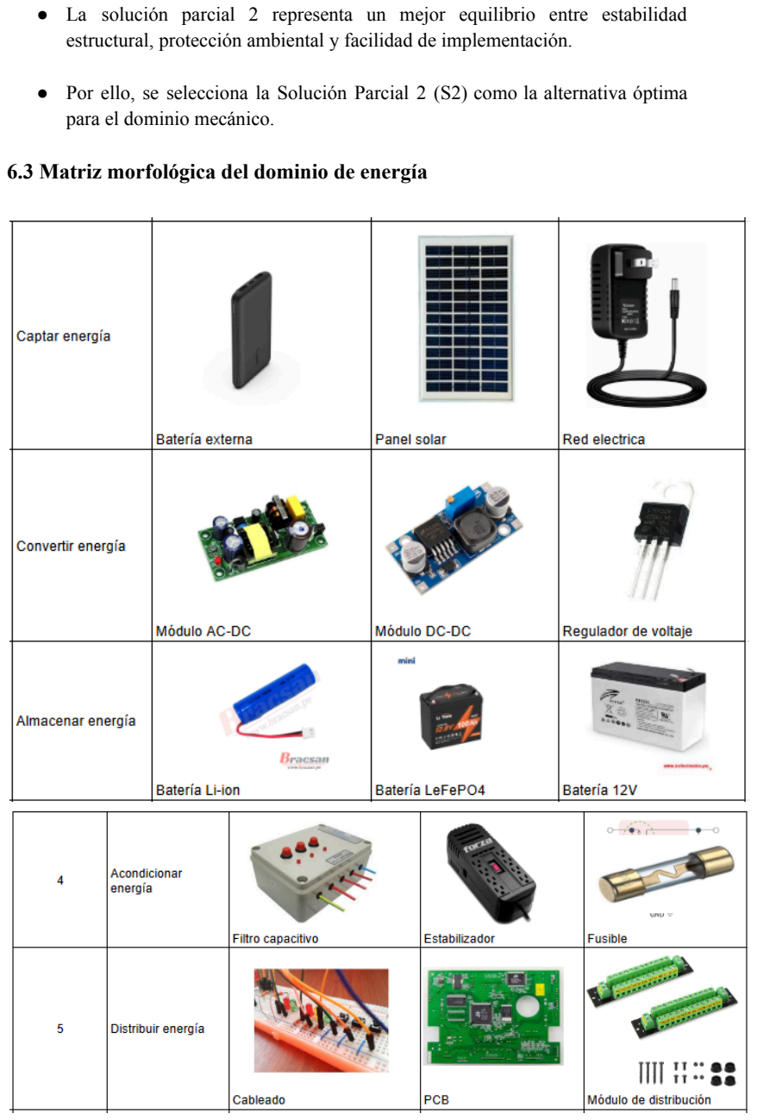
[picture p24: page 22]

- La solución parcial 2 representa un mejor equilibrio entre estabilidad estructural, protección ambiental y facilidad de implementación.
- Por ello, se selecciona la Solución Parcial 2 (S2) como la alternativa óptima para el dominio mecánico.

### 6.3 Matriz morfológica del dominio de energía

### 6.3.1 Disposición básica de soluciones del dominio de energía

- La solución parcial 1 emplea un panel solar como fuente principal de energía, un módulo DC-DC para conversión de voltaje y una batería Li-ion para almacenamiento energético. Asimismo, incorpora fusibles y cableado para distribución eléctrica.
- La solución parcial 2 utiliza panel solar, módulo DC-DC y batería LiFePO4 para almacenamiento energético. Además, incorpora un estabilizador y una PCB para mejorar la calidad y distribución de energía.
- La solución parcial 3 emplea una batería externa junto con regulador de voltaje y batería de 12V. También incorpora filtros capacitivos y módulos de distribución energética.

### 6.3.2 Evaluación de conceptos y selección del concepto óptimo

- La solución parcial 1 presenta simplicidad y bajo costo, aunque posee menor autonomía y estabilidad energética.
- La solución parcial 3 ofrece mayor capacidad energética y respaldo de alimentación, pero incrementa el tamaño y complejidad del sistema.
- La solución parcial 2 proporciona un mejor equilibrio entre autonomía, estabilidad energética y facilidad de implementación. Además, la batería LiFePO4 ofrece mayor vida útil y seguridad operativa.
- Por ello, se selecciona la Solución Parcial 2 (S2) como la alternativa óptima para el dominio de energía.

### 6.4 Matriz morfológica del dominio de control

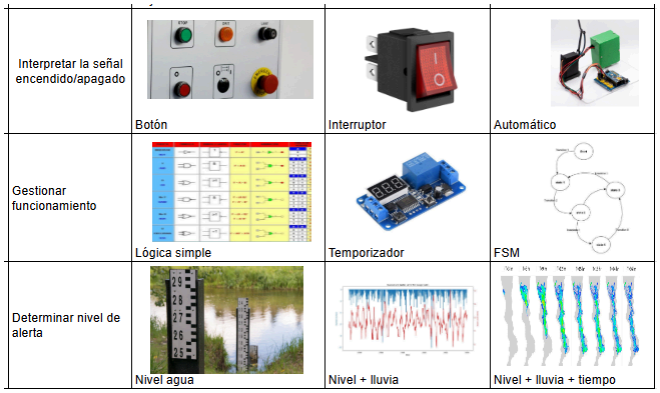
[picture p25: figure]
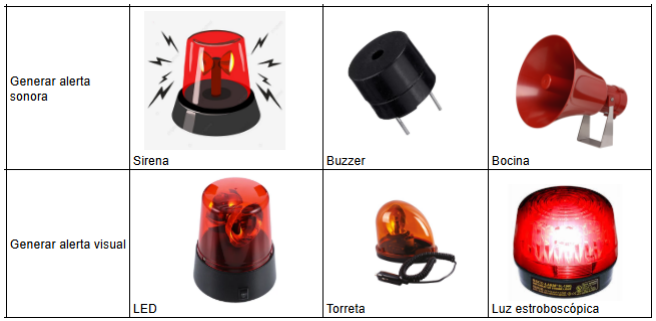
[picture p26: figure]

### 6.4.1 Disposición básica de soluciones del dominio de control

- La solución parcial 1 utiliza un botón para el encendido y apagado del sistema, lógica simple para la gestión del funcionamiento y evaluación del nivel del agua como criterio principal de alerta. Las alertas son emitidas mediante buzzer y LED.
- La solución parcial 2 incorpora un interruptor para control del sistema, temporizadores para la gestión del funcionamiento y evaluación conjunta de nivel del agua y lluvia para determinar el nivel de alerta. Las alertas son generadas mediante sirena y torreta luminosa.

- La solución parcial 3 emplea funcionamiento automático y una máquina de estados finitos (FSM) para gestionar el sistema. Además, evalúa simultáneamente nivel, lluvia y tiempo para determinar el nivel de riesgo. Las alertas son emitidas mediante bocina y luz estroboscópica.

### 6.4.2 Evaluación de conceptos y selección del concepto óptimo

- La solución parcial 1 presenta facilidad de implementación, aunque ofrece menor capacidad de análisis y automatización.
- La solución parcial 3 proporciona un control más avanzado y automatizado, pero incrementa considerablemente la complejidad del sistema.
- La solución parcial 2 representa un equilibrio adecuado entre automatización, estabilidad y facilidad de implementación, reduciendo falsas alarmas y mejorando la confiabilidad del sistema.
- Por ello, se selecciona la Solución Parcial 2 (S2) como la alternativa óptima para el dominio de control.

### 6.5 Matriz morfológica del dominio de software

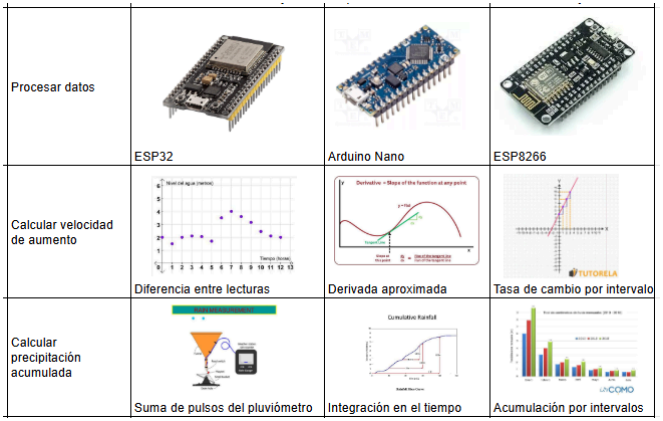
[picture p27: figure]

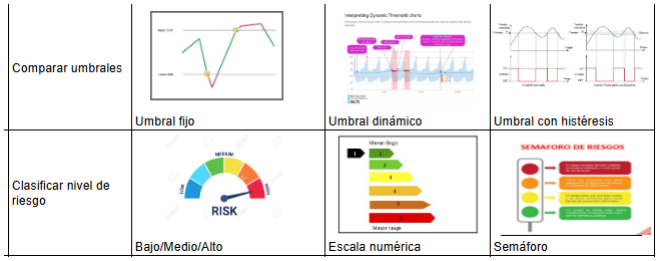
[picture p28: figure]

### 6.5.1 Disposición básica de soluciones del dominio de software

- La solución parcial 1 emplea diferencia entre lecturas para calcular la velocidad de aumento del nivel del agua, suma de pulsos para calcular precipitación acumulada y umbrales fijos para clasificar el riesgo.
- La solución parcial 2 utiliza tasa de cambio por intervalo para evaluar el comportamiento del nivel del agua, acumulación por intervalos para precipitación y umbrales con histéresis para reducir falsas activaciones.
- La solución parcial 3 emplea derivada aproximada e integración en el tiempo para el análisis de datos, utilizando umbrales dinámicos y clasificación mediante escalas numéricas.

### 6.5.2 Evaluación de conceptos y selección del concepto óptimo

- La solución parcial 1 ofrece simplicidad de programación y bajo requerimiento computacional, aunque presenta menor precisión en la evaluación del riesgo.
- La solución parcial 3 proporciona mayor capacidad de análisis y automatización, pero aumenta considerablemente la complejidad del software.
- La solución parcial 2 ofrece un mejor equilibrio entre precisión, estabilidad y facilidad de implementación, permitiendo reducir falsas alarmas y mejorar la confiabilidad del sistema.
- Por ello, se selecciona la Solución Parcial 2 (S2) como la alternativa óptima para el dominio de software.

### 6.6 Matriz morfológica Integrada

SOLUCIÓN 1 | SOLUCIÓN 2 | SOLUCIÓN 3

⬇ | ⬇ | ⬇

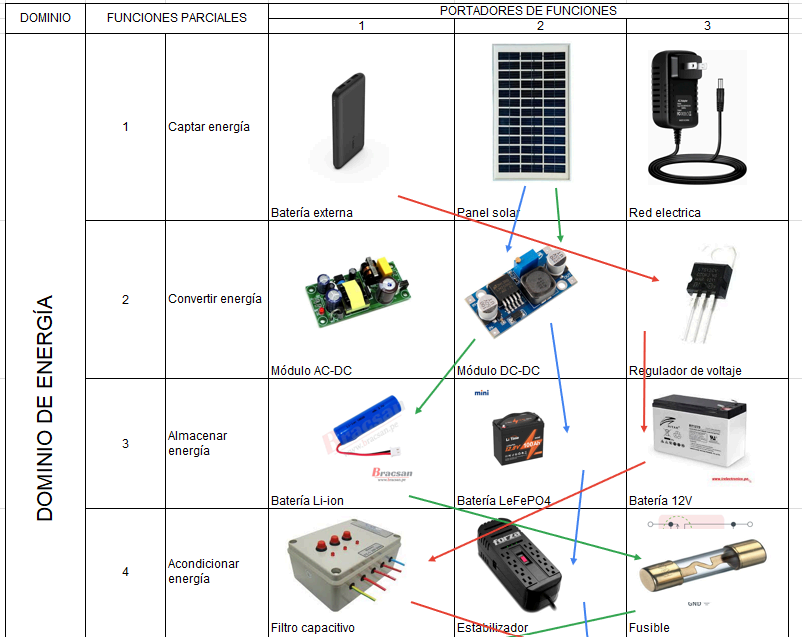
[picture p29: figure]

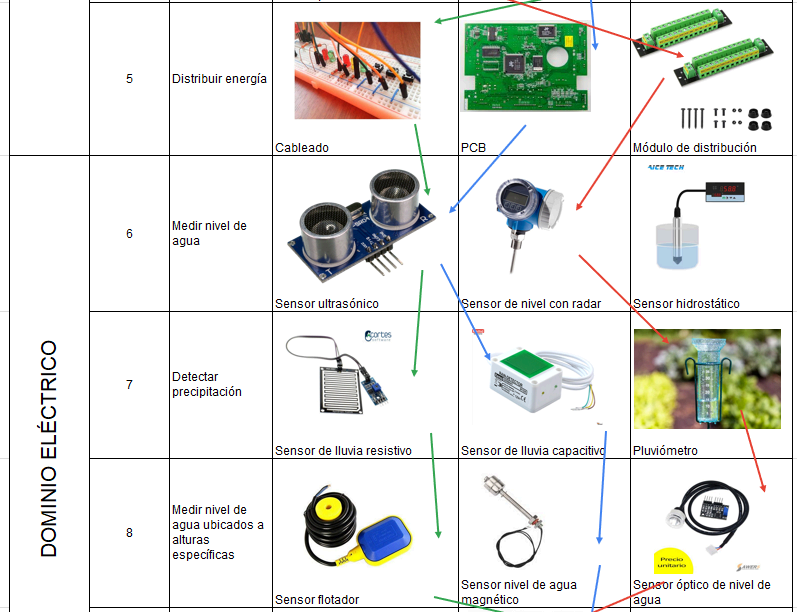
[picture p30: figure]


### 7. Bocetos de los 3 conceptos de solución

7.1 Bocetos del Concepto de solución 1


Descripción de Funcionamiento:

El dispositivo monitorea el nivel del agua mediante un sensor ultrasónico orientado hacia el río, permitiendo medir continuamente la distancia entre el equipo y la superficie del agua. La estructura externa protege los componentes internos y facilita el acceso para mantenimiento mediante la puerta frontal.

En la parte superior, el sensor de lluvia detecta precipitaciones intensas y el panel solar suministra energía al sistema para su funcionamiento autónomo. Además, el LED indicador muestra el estado operativo del dispositivo.

El sistema electrónico procesa la información obtenida por los sensores y activa los indicadores de nivel: verde para nivel bajo, amarillo para nivel medio y rojo para nivel alto. Cuando se detecta un nivel crítico, la bocina emite una alerta sonora para advertir sobre posibles inundaciones.

La estructura está diseñada para resistir condiciones ambientales exteriores, garantizando protección frente a lluvia, humedad y exposición continua al entorno.

### 7.2 Bocetos del Concepto de solución 2


Descripción de Funcionamiento:

El dispositivo monitorea el nivel del agua mediante un sensor ultrasónico orientado hacia el río, el cual mide continuamente la distancia entre el equipo y la superficie del agua. La estructura elevada protege los componentes internos y facilita el acceso al sistema mediante una puerta frontal.

En la parte superior, el sensor de lluvia detecta precipitaciones intensas y el panel solar proporciona energía para el funcionamiento autónomo del dispositivo. Asimismo, el LED indicador muestra el estado operativo del sistema y la bocina emite alertas sonoras en situaciones de riesgo.

En la parte lateral, las boyas indicadoras muestran el nivel del agua: verde para nivel bajo, amarillo para nivel medio y rojo para nivel alto. El sistema electrónico procesa la información de los sensores y activa las alertas correspondientes cuando el nivel del río aumenta.

La estructura está diseñada para operar en exteriores, ofreciendo protección frente a lluvia, humedad y condiciones ambientales del entorno fluvial.

### 7.3 Bocetos del Concepto de solución 3


Descripción de Funcionamiento:

El dispositivo monitorea el nivel del agua mediante un sensor ultrasónico orientado hacia el río, el cual mide continuamente la distancia entre el equipo y la superficie del agua. La estructura principal protege los componentes internos y permite el acceso al sistema mediante una puerta frontal.

En la parte superior, el sensor de lluvia detecta precipitaciones intensas y el panel solar suministra energía para el funcionamiento autónomo del dispositivo. Asimismo, el LED indicador muestra el estado operativo y la sirena emite alertas sonoras en situaciones de riesgo.

En la parte inferior lateral, las boyas indicadoras muestran el nivel del agua mediante colores: verde para nivel bajo, amarillo para nivel medio y rojo para nivel alto. El sistema electrónico procesa la información obtenida por los sensores y activa las alertas correspondientes cuando se detecta un aumento del caudal del río.

La estructura está diseñada para operar en exteriores, brindando protección frente a lluvia, humedad y condiciones ambientales del entorno fluvial.

### 8. Evaluación de Matriz de Pugh

Escala de puntuación:

1: Deficiente / Bajo (No cumple adecuadamente con las exigencias) 2: Suficiente / Regular (Cumple de manera aceptable)
3: Bueno / Óptimo (Solución ideal para el criterio)
N.º | Criterio técnico/económ ico | Solución 1 | Solución 2 | Solución 3
1 | Precisión de medición | 1 | 3 | 3
2 | Autonomía y estabilidad energética | 2 | 3 | 2
3 | Confiabilidad de procesamiento y control | 1 | 3 | 2
4 | Eficacia del sistema de alertas | 1 | 3 | 3
5 | Protección mecánica y ambiental | 1 | 3 | 3
6 | Facilidad de implementación en campo | 3 | 2 | 1
7 | Facilidad de mantenimiento | 3 | 2 | 1

N.º | Criterio técnico/económ ico | Solución 1 | Solución 2 | Solución 3
8 | Costo de componentes | 3 | 2 | 1
9 | Disponibilidad de materiales | 3 | 3 | 1
PUNTAJE TOTAL | | 18 | 24 | 17

### 8.1 Selección y explicación de los criterios técnico/económicos

Los criterios fueron seleccionados de acuerdo con las funciones principales del sistema Llaqta Guardian: monitoreo del comportamiento hidrológico ante inundaciones fluviales, autonomía en zonas rurales, resistencia a la intemperie y viabilidad de implementación para la simulación del prototipo.

N.º | Criterio técnico/económico | Explicación
1 | Precisión de medición | Evalúa la capacidad y exactitud para medir el nivel del agua y la precipitación pluvial en el entorno ribereño.
2 | Autonomía y estabilidad energética | Considera la capacidad de operar de forma ininterrumpida utilizando fuentes renovables y la eficiencia del almacenamiento de energía.
3 | Confiabilidad de procesamiento y control | Evalúa la robustez de los algoritmos (cálculo de tasas,

N.º | Criterio técnico/económico | Explicación
| | umbrales) y la capacidad del microcontrolador para evitar falsas alarmas.
4 | Eficacia del sistema de alertas | Analiza el alcance y claridad de las advertencias sonoras y visuales emitidas a la comunidad.
5 | Protección mecánica y ambiental | Considera el grado de hermeticidad frente a la lluvia, humedad, polvo y la estabilidad de la estructura física cerca al río.
6 | Facilidad de implementación en campo | Evalúa la viabilidad de instalar la estructura, anclajes y componentes en zonas rurales de difícil acceso.
7 | Facilidad de mantenimiento | Considera la accesibilidad para limpiar sensores, reemplazar baterías o revisar las conexiones electrónicas.
8 | Costo de componentes | Evalúa la inversión requerida para la fabricación del módulo, priorizando la viabilidad económica del proyecto.
9 | Disponibilidad de materiales | Considera la facilidad para adquirir los sensores, baterías y componentes estructurales en el mercado local.

### 8.2 Justificación de asignación de puntajes

La asignación de puntajes se realizó considerando el nivel de cumplimiento de cada solución frente a las exigencias operativas en entornos rurales. La Solución 1 presenta la puntuación más alta (3) en economía y facilidad de instalación, pero tiene deficiencias graves (1) en precisión y resistencia. La Solución 2 obtiene el mejor equilibrio general, con puntajes óptimos (3) en precisión, protección y autonomía, manteniendo niveles aceptables en costos para asegurar un ensamblaje funcional a tiempo para las pruebas. La Solución 3 alcanza buenos puntajes en capacidad tecnológica de medición y alertas, pero su excesiva complejidad y alto costo penalizan severamente su puntaje final.

### 8.2.1 Concepto de Solución 1

La Solución 1 corresponde a un enfoque económico y de implementación sencilla. Utiliza un panel solar, un módulo DC-DC y una batería Li-ion básica. En el dominio electrónico, emplea un sensor ultrasónico, un sensor de lluvia resistivo y un sensor flotador, procesados mediante un microcontrolador ESP32 con algoritmos de diferencia entre lecturas y umbrales fijos.
Esta alternativa obtiene un puntaje óptimo (3) en facilidad de implementación, costo de componentes, mantenimiento y disponibilidad de materiales, dado que el uso de un poste metálico simple, pernos y caja de PVC simplifica el ensamblaje y reduce gastos. Sin embargo, recibe puntajes deficientes (1) en precisión de medición, confiabilidad de procesamiento y protección ambiental. El sensor de lluvia resistivo se corroe rápidamente, los umbrales fijos son propensos a generar falsas alarmas y la caja de PVC no garantiza hermeticidad.

### 8.2.2 Concepto de Solución 2

La Solución 2 corresponde a una alternativa balanceada y robusta. Emplea un panel solar con batería LiFePO4 y módulo DC-DC, asegurando una autonomía estable y con mayor vida útil. Para la medición, emplea un sensor ultrasónico, un sensor de lluvia capacitivo y un sensor magnético, procesados por un ESP32 mediante tasas de cambio y acumulación por intervalos.
Esta solución alcanza un puntaje óptimo (3) en precisión, autonomía, confiabilidad de procesamiento, eficacia de alertas y protección mecánica y ambiental, ya que la caja IP65 garantiza hermeticidad contra la lluvia y polvo. El uso de umbrales con histéresis es altamente confiable para evitar falsas alarmas por el oleaje del río. Recibe un puntaje suficiente (2) en costo e implementación, ya que exige mayor presupuesto y esfuerzo de ensamblaje que la Solución 1, pero se justifica plenamente por su estabilidad operativa frente a desastres.

### 8.2.3 Concepto de Solución 3

La Solución 3 es una alternativa de respaldo avanzado con alta automatización. Funciona con una batería externa de 12V y regulador de voltaje. Incorpora tecnología como un sensor radar, pluviómetro y sensor óptico, gestionados por un ESP8266 mediante una Máquina de Estados Finitos (FSM) y umbrales dinámicos.
Esta solución obtiene un puntaje óptimo (3) en precisión de medición (gracias al sensor radar) y en eficacia del sistema de alertas (la luz estroboscópica y bocina tienen un alcance superior). Sin embargo, resulta deficiente (1) para un contexto de prototipado rural. El uso de cimentación de concreto dificulta enormemente la implementación y mantenimiento en riberas. Adicionalmente, el alto costo de sus componentes y la baja disponibilidad en el mercado local penalizan fuertemente su viabilidad general.

### 8.3 Concepto de Solución Óptimo

De acuerdo con la evaluación de la Matriz de Pugh mediante suma directa, la alternativa con mayor puntaje total es la Solución 2, con 24 puntos, seguida por la Solución 1 con 18 puntos y la Solución 3 con 17 puntos.

Concepto de solución | Puntaje total | Orden de prioridad
Solución 2 | 24 | 1
Solución 1 | 18 | 2
Solución 3 | 17 | 3

Por lo tanto, se selecciona como concepto de solución óptima la Solución 2 (Balanceado / Recomendado). Esta alternativa es la más idónea para Llaqta Guardian porque integra componentes altamente confiables frente a la humedad (sensores capacitivos y ultrasónicos, caja IP65) y un procesamiento robusto mediante algoritmos de histéresis en el ESP32, sin llegar a niveles inviables de costo o complejidad de instalación.
En conclusión, la Solución 2 permite cumplir de manera realista y eficiente con el objetivo del proyecto: disponer de un sistema de alerta temprana autónomo, resistente a las condiciones ribereñas y que sea fácilmente interpretable (sistema de semáforo) por la comunidad para la mitigación del riesgo de inundaciones fluviales.

Referencias bibliográficas

1. Servicio Nacional de Meteorología e Hidrología (SENAMHI). Nuevo mapa del SENAMHI permite conocer zonas inundables en el Perú. https://www.gob.pe/institucion/senamhi/noticias/126363-nuevo-mapa-del-senamhi-pe rmite-conocer-zonas-inundables-en-el-peru (https://www.gob.pe/institucion/senamhi/noticias/126363-nuevo-mapa-del-senamhi-permite-conocer-zonas-inundables-en-el-peru)
2. Organización Meteorológica Mundial (OMM). Los fenómenos peligrosos relacionados con el agua son los grandes causantes de los desastres de los últimos 50 años. Ginebra: OMM; 2021 Jul 22 https://wmo.int/es/media/los-fenomenos-peligrosos-relacionados-con-el-agua-son-los-grandes-causantes-de-los-desastres-de-los (https://wmo.int/es/media/los-fenomenos-peligrosos-relacionados-con-el-agua-son-los-grandes-causantes-de-los-desastres-de-los)
3. SENAMHI. Inventario de datos de eventos de inundaciones del Perú. Lima: Ministerio del Ambiente; 2022 https://www.senamhi.gob.pe/load/file/01401SENA-99.pdf
4. Agencia Peruana de Noticias (ANDINA). Lluvias en Loreto: suman más de 20 mil afectados en distritos declarados en emergencia. Loreto, 22 Mar 2025 https://andina.pe/agencia/noticia-lluvias-loreto-suman-mas-20-mil-afectados-distritos-declarados-emergencia-1023256.aspx (https://andina.pe/agencia/noticia-lluvias-loreto-suman-mas-20-mil-afectados-distritos-declarados-emergencia-1023256.aspx)
5. Instituto Nacional de Defensa Civil (INDECI) – COEN. Reporte Complementario N.º 5143 (15 jun 2023) – Inundación por desborde de río en Requena (Loreto). Lima: INDECI, 2023.
https://portal.indeci.gob.pe/wp-content/uploads/2023/06/REPORTE-COMPLEMENT ARIO-N%C2%BA-5143-15JUN2023-INUNDACI%C3%93N-POR-DESBORDE-D E-R%C3%8DO-EN-EL-DISTRITO-DE-REQUENA-LORETO-9.pdf (https://portal.indeci.gob.pe/wp-content/uploads/2023/06/REPORTE-COMPLEMENTARIO-N%C2%BA-5143-15JUN2023-INUNDACI%C3%93N-POR-DESBORDE-DE-R%C3%8DO-EN-EL-DISTRITO-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)
6. Servicio Nacional de Meteorología e Hidrología del Perú (SENAMHI). Pronósticos que salvan vidas: hacia un sistema de alerta por inundaciones en la Amazonía peruana (nota informativa, 17 abr 2026). Lima: SENAMHI. https://www.gob.pe/institucion/senamhi/noticias/1380395-pronosticos-que-salvan-vid as-hacia-un-sistema-de-alerta-por-inundaciones-en-la-amazonia-peruana (https://www.gob.pe/institucion/senamhi/noticias/1380395-pronosticos-que-salvan-vidas-hacia-un-sistema-de-alerta-por-inundaciones-en-la-amazonia-peruana)
7. Autoridad Nacional del Agua (ANA) – CENEPRED. Informe N.º 008-2018-ANA-AAA-IX-UCAYALI-ALA-P-JFP: Identificación de zona de riesgo y puntos críticos en la ciudad de Requena (Loreto). Lima: ANA/CENEPRED, 2018. https://sigrid.cenepred.gob.pe/sigridv3/documento/4343
8. Naciones Unidas (ONU). Transformar nuestro mundo: la Agenda 2030 para el Desarrollo Sostenible
https://unctad.org/system/files/official-document/ares70d1_es.pdf

9. Instituto Peruano de Economía (IPE); Portal PQS. Loreto: más de 52 mil viviendas están expuestas a riesgo de inundación. Lima: PQS; 2026 Abr 27 https://pqs.pe/actualidad/loreto-mas-de-52-mil-viviendas-estan-expuestas-a-riesgo-de-inundacion/ (https://pqs.pe/actualidad/loreto-mas-de-52-mil-viviendas-estan-expuestas-a-riesgo-de-inundacion/)
10. Programa de las Naciones Unidas para el Desarrollo (PNUD). La lucha colectiva contra las inundaciones: comunidad, datos y resiliencia. Nueva York: PNUD; 2023 https://www.undp.org/es/panama/blog/la-lucha-colectiva-de-panama-contra-las-inund aciones-construyendo-comunidad-datos-y-resiliencia (https://www.undp.org/es/panama/blog/la-lucha-colectiva-de-panama-contra-las-inundaciones-construyendo-comunidad-datos-y-resiliencia)
11. World Intellectual Property Organization. Flood monitoring system.
WO2021003768A1. 2021.
https://worldwide.espacenet.com/patent/search?q=pn%3DWO2021003768A1
12. World Intellectual Property Organization. Water level detection system. WO2023276383A1. 2023.
https://worldwide.espacenet.com/patent/search?q=pn%3DWO2023276383A1
13. Instituto Nacional de Seguridad y Salud en el Trabajo (INSST). ISO 11228: Manipulación manual de cargas (guía técnica). Madrid: INSST; s.f. https://www.insst.es/documents/94886/509319/SyC_ISO+11228.pdf/a1838f7f-6592-4 d68-b91f-fd9495895ea2 (https://www.insst.es/documents/94886/509319/SyC_ISO+11228.pdf/a1838f7f-6592-4d68-b91f-fd9495895ea2)

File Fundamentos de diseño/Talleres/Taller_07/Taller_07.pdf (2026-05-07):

## UNIVERSIDAD PERUANA CAYETANO HEREDIA


## DOCUMENTACIÓN TÉCNICA

## Sistema de alerta temprana para inundaciones

## Fundamentos de Diseño

## Grupo: 14

## Integrantes:

## Perez Suarez, Doménica

## Calva Becerra, Sofía

## Dulanto Aguilar, Némesis

## Huillca Quispe, Kevin

## Cayco Tucto, Caleb

### Lima - Perú

2026

- LISTA DE EXIGENCIAS:

LISTA DE EXIGENCIAS

Páginas 4

Edición: Rev 2.0

PROYECT
O:

Llaqta Guardian: Sistema de alerta temprana comunitario para la detección de inundaciones fluviales en zonas rurales amazónicas.

Fecha: 23/04/2026

Revisado:

CLIENTE: | Profesores del curso de Fundamentos de Diseño | Elaborado: Equipo 14 FdD: - Doménica - Sofía - Nemesis - Caleb - Kevin
Fecha | Deseo o Exigencia | DESCRIPCIÓN | Responsable
(cambios)

29/04/2026 E

FUNCIÓN PRINCIPAL:

Todos

El sistema monitorea el nivel del agua, intensidad de lluvia y estado de boyas, activando automáticamente una alerta sonora y visual cuando se supera un umbral crítico, sin depender de internet o señal móvil.

| | GEOMETRÍA:
29/04/2026 | E | El módulo electrónico presenta dimensiones máximas de 300x200x150 mm (LxAxP), definidas tomando como referencia sistemas de monitoreo de nivel de agua [1][2]. | Nemesis
29/04/2026 | E | El sistema está diseñado para instalarse en la ribera del río anclado, con sensores hacia las variables a medir. | Némesis
29/04/2026 | E | CINEMÁTICA:

No aplica

29/04/2026 | E | FUERZAS:

| | El sistema tiene un peso total máximo de 5 kg permitiendo su transporte manual y facilitando su instalación, asegurando estabilidad estructural en la ribera del río.[3] | Caleb
29/04/2026 | E | MATERIA:

No aplica

29/04/2026 | E | ENERGÍA:
| | El sistema funciona principalmente con una fuente de energía eléctrica externa, que alimenta el equipo y recarga una batería para asegurar su funcionamiento continuo. Además, cuenta con un panel solar como apoyo, que ayuda a mantener la batería cargada y aumentar su autonomía. | Kevin
| | SEÑALES:

Todos

| | Entradas:
29/04/2026 | E | Señal de nivel de agua mediante sensor ultrasónico.
| E | Señal de detección de lluvias mediante sensor de lluvia
| E | Señal discreta de nivel mediante boyas eléctricas.
| E | Señal de encendido/apagado del sistema.
| | Salidas:
29/04/2026 | E | Señal de nivel de alerta
| | CONTROL:
29/04/2026 | E | El sistema define al menos dos niveles de alerta (preventivo y crítico) y activa la alerta al superar el umbral crítico definido . | Sofía
29/04/2026 | E | El sistema disminuye falsas alarmas mediante validación de mediciones continuas. | Sofía
| | ELECTRONICA (Hardware)

29/04/2026 | E | El sistema emplea sensores como el ultrasónico para la medición del nivel del agua, un sensor de lluvia para la detección de precipitación y sensores tipo boya para niveles discretos. Estos son gestionados por un microcontrolador ESP32 encargado de la adquisición y procesamiento de datos. | Kevin
29/04/2026 | E | El sistema incluye módulo de activación de sirena y luces. | Kevin
| | SOFTWARE:
29/04/2026 | E | El sistema procesa datos en tiempo real y ejecuta lógica de alerta. | Sofía
29/04/2026 | E | El sistema puede almacenar datos históricos de medición. | Sofía
| | COMUNICACIONES:
29/04/2026 | E | La alerta se transmite mediante señales físicas (luz y sonido). | Sofía
29/04/2026 | E | El sistema no depende de internet ni red móvil. | Kevin
| | SEGURIDAD:
29/04/2026 | E | El sistema no representa riesgo eléctrico para los usuarios. | Kevin
29/04/2026 | E | El sistema resiste contacto continuo con agua, lluvia intensa y humedad. | Nemesis
| | ERGONOMÍA:
29/04/2026 | E | El sistema es fácil de interpretar por cualquier miembro de la comunidad. | Doménica
29/04/2026 | E | La alerta es claramente identificable mediante sonido y luz. | Doménica
| | FABRICACIÓN:
29/04/2026 | E | Materiales resistentes a humedad, corrosión y ambiente amazónico. | Némesis
29/04/2026 | E | El sistema cuenta con sellado contra ingreso de agua (IP65 o superior). | Caleb
| | CONTROL DE CALIDAD:
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

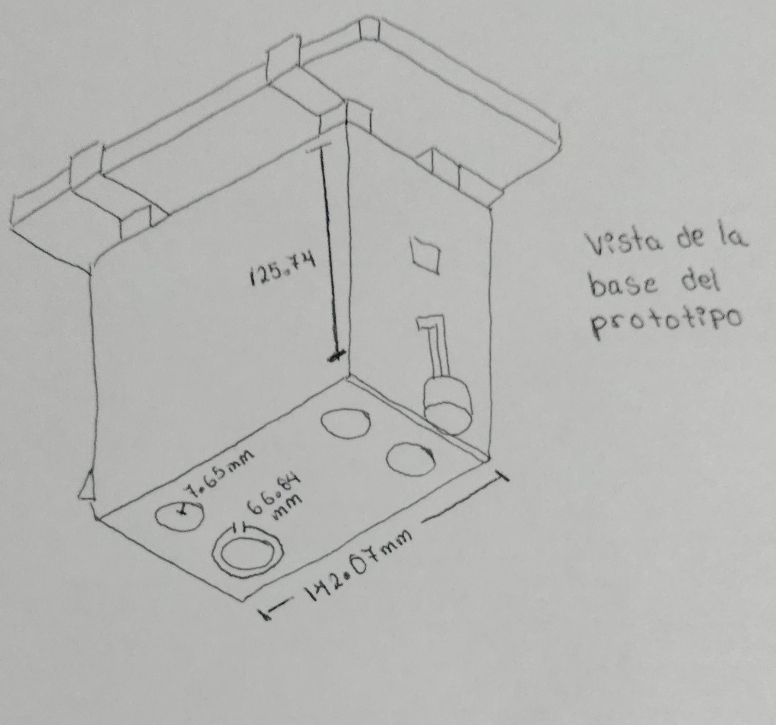
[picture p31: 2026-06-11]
Fundamentos de diseño/Entregables/Entregable 3/Imágenes/boceto_vista_base.jpg

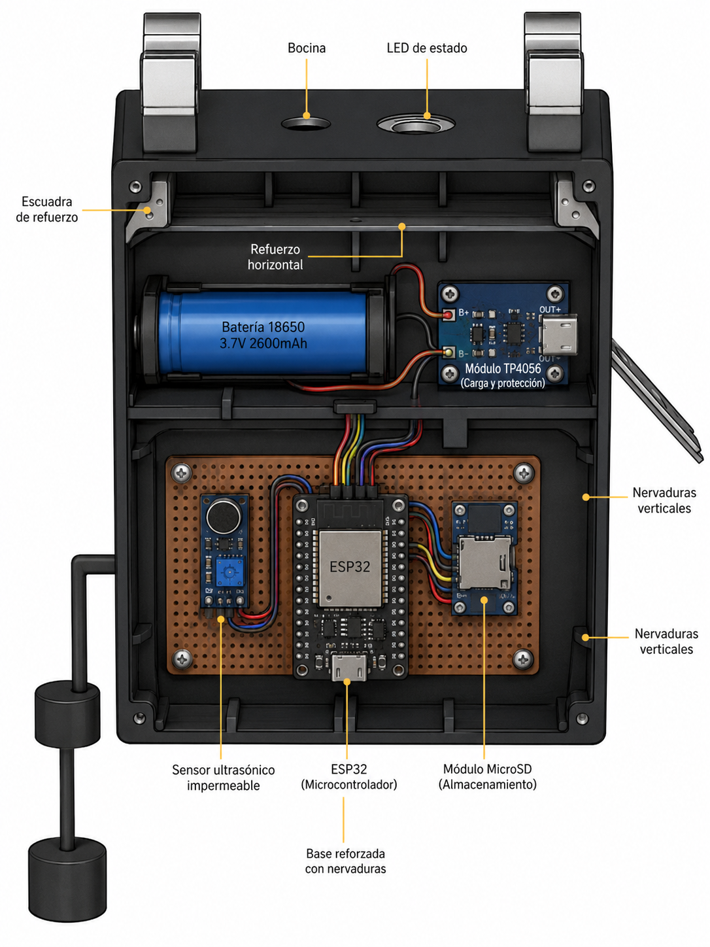
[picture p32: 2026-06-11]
Fundamentos de diseño/Entregables/Entregable 3/Imágenes/boceto_interior.png

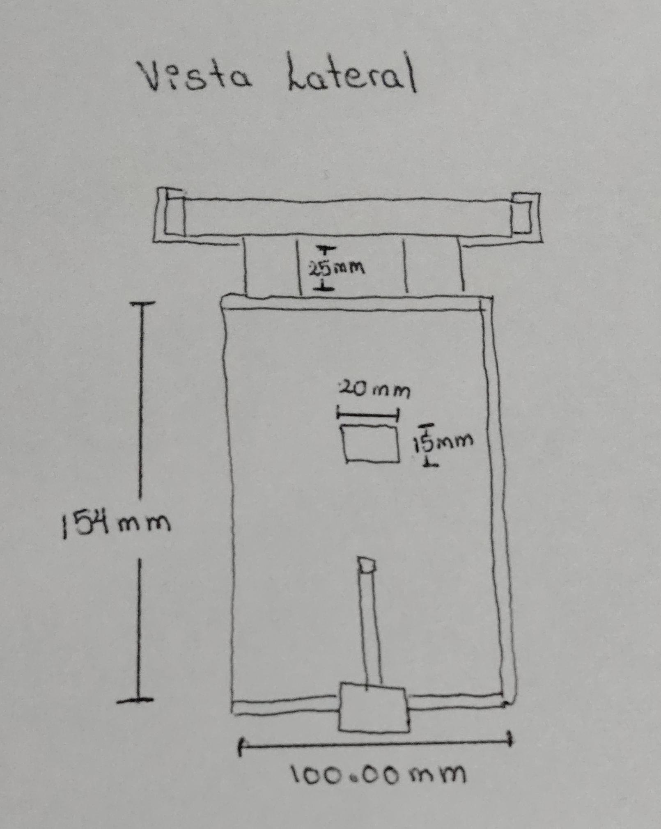
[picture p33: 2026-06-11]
Fundamentos de diseño/Entregables/Entregable 3/Imágenes/boceto_vista_lateral.jpg

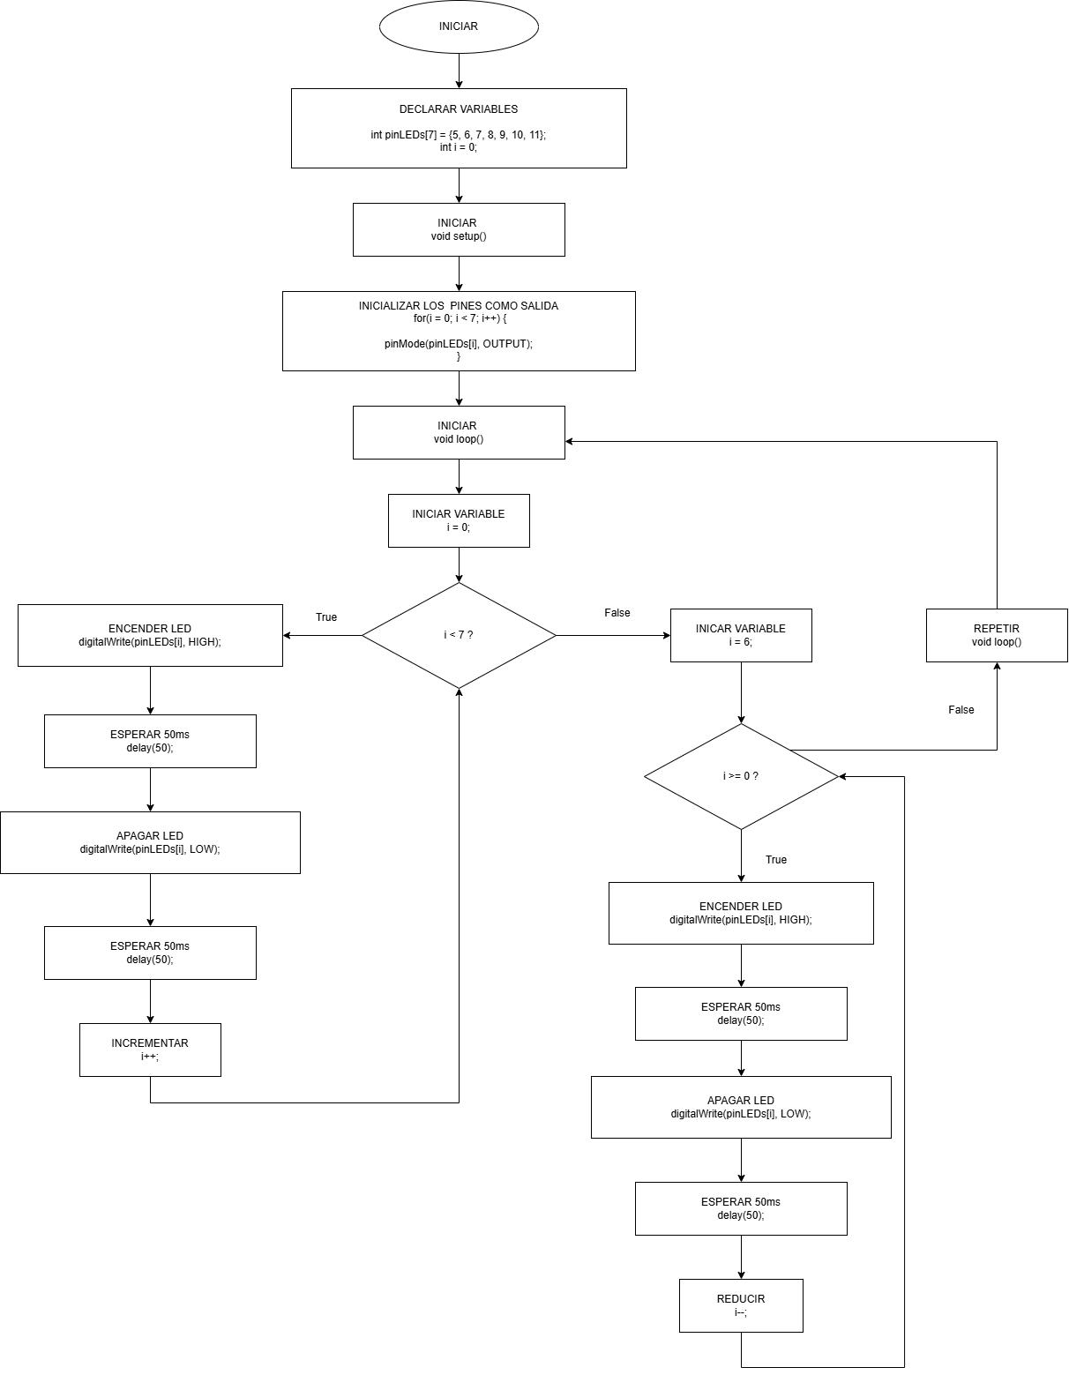
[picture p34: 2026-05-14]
Fundamentos de diseño/Talleres/Taller_09/Taller_09_Diagrama_Flujo.png

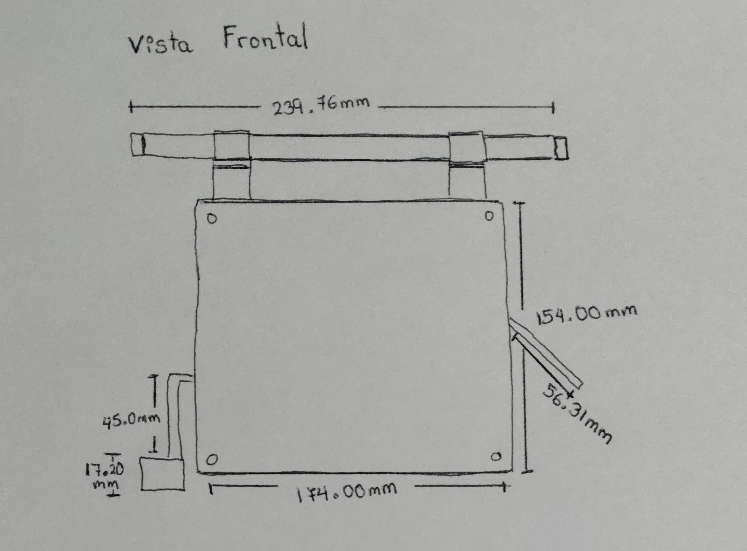
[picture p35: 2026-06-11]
Fundamentos de diseño/Entregables/Entregable 3/Imágenes/boceto_vista_frontal.jpg

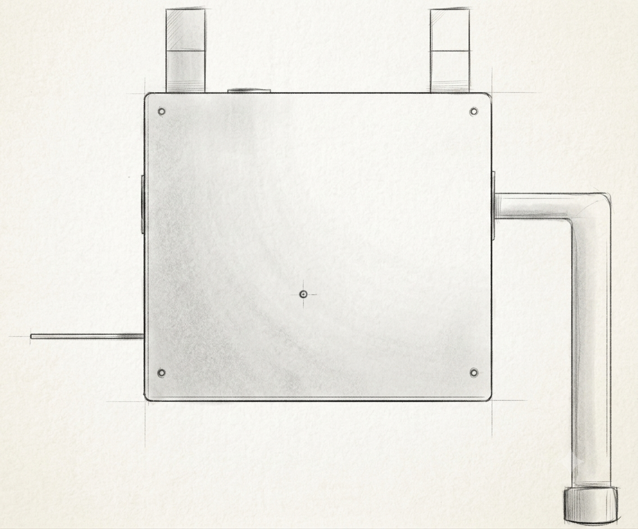
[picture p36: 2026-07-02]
Proyecto/Módulo Mecánico/VFINAL/Bocetos/Boceto frontal VFINAL.png

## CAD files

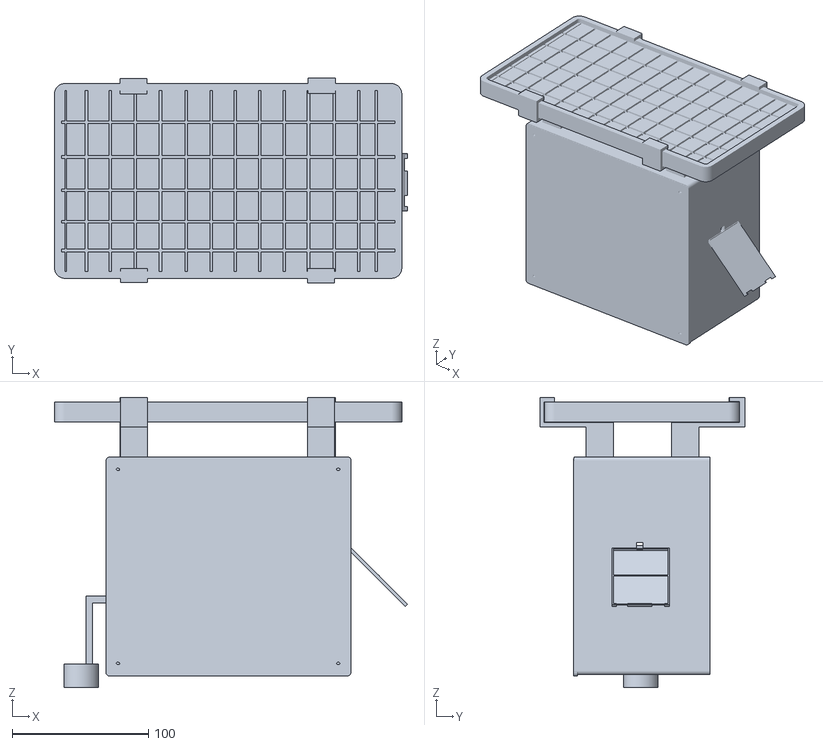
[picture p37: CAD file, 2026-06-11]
Fundamentos de diseño/Entregables/Entregable 3/OnShape/Assembly completo.stl
259.2 x 150.4 x 213.0

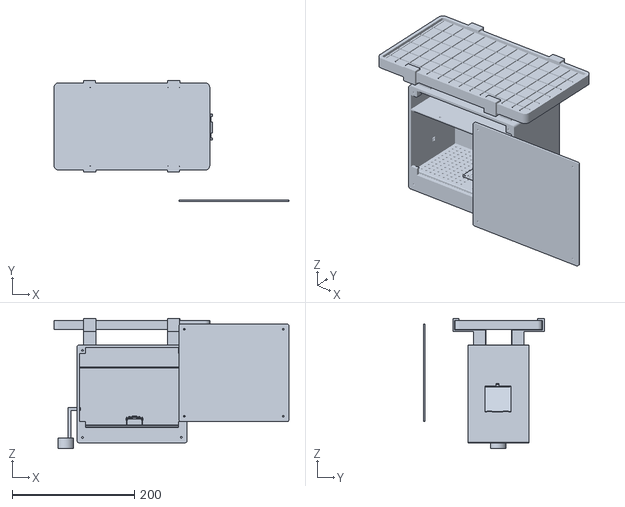
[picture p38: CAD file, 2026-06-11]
Fundamentos de diseño/Entregables/Entregable 3/OnShape/Assembly.stl
384.7 x 198.7 x 213.0

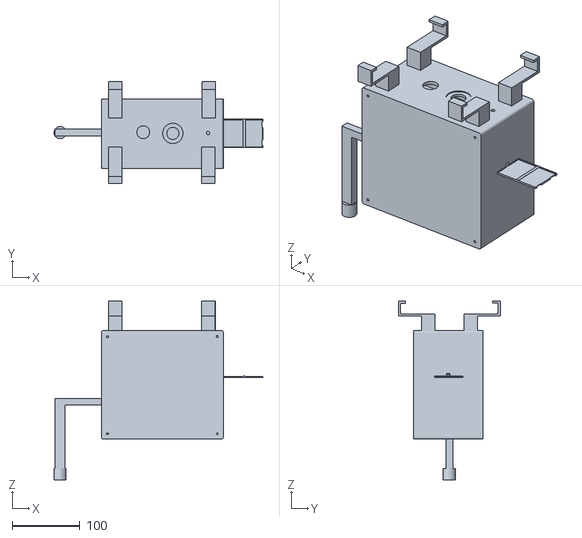
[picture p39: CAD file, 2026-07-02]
Proyecto/Módulo Mecánico/V1.0/Onshape/Ensamble/Modelo Integrado LLAQTA Guardian V1.0.stl
308.4 x 150.4 x 263.6

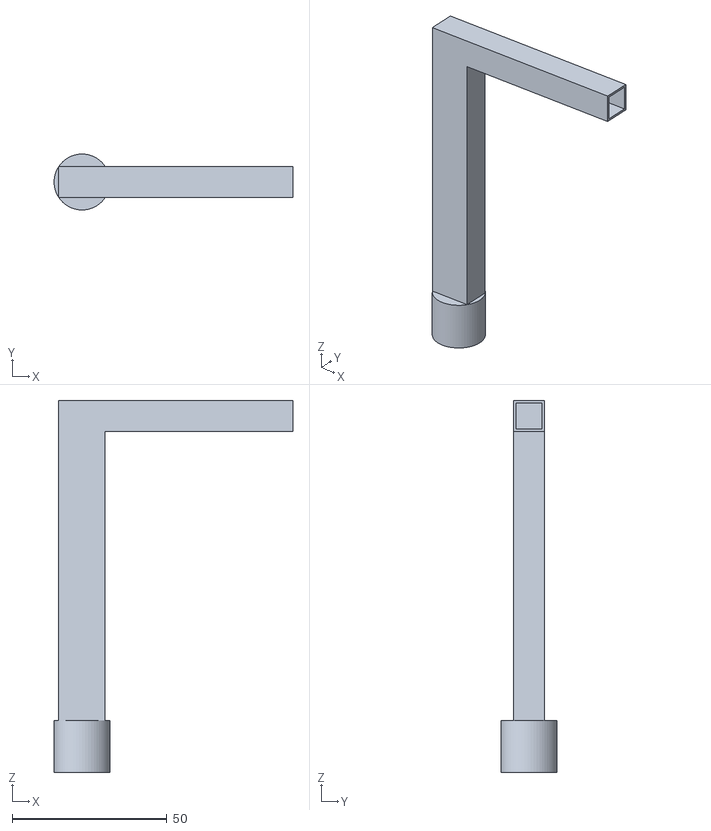
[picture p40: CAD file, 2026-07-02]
Proyecto/Módulo Mecánico/V1.0/Onshape/Partes/Estructura en L V1.0.stl
77.2 x 18.1 x 120.2

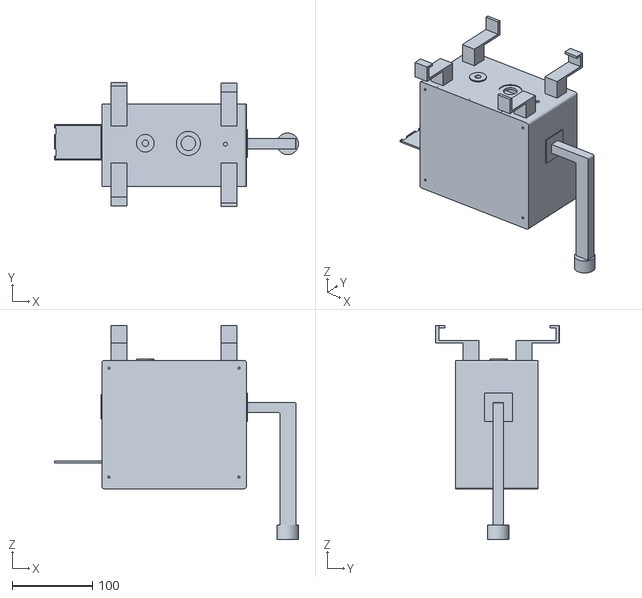
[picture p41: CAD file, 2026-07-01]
Proyecto/Módulo Mecánico/VFINAL/Onshape/Ensamble/Modelo Integrago LLAQTA GUARDIAN VFINAL.stl
303.9 x 153.9 x 266.7

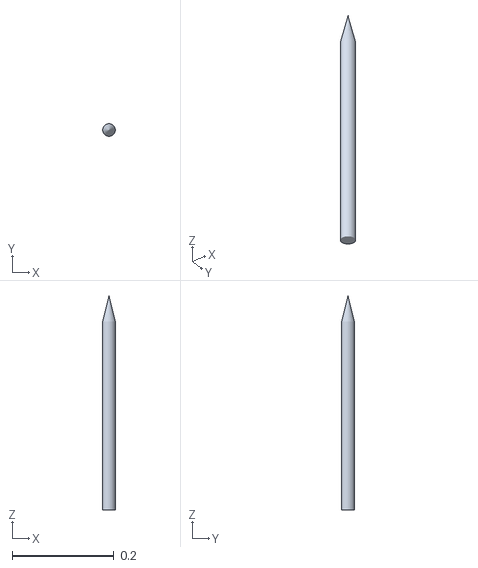
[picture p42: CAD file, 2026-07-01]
Proyecto/Módulo Mecánico/VFINAL/Onshape/Partes/Estaca VFINAL.stl
0.025 x 0.025 x 0.42

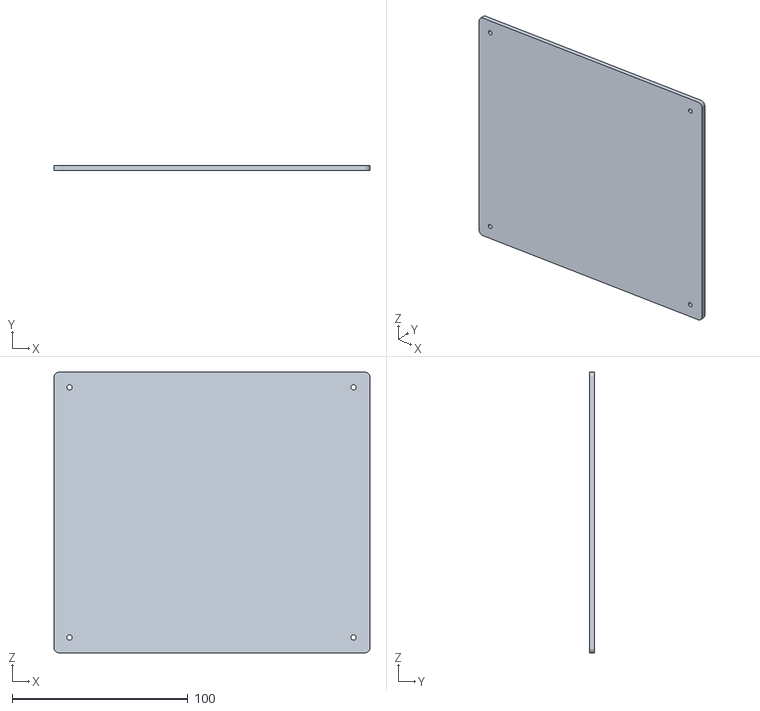
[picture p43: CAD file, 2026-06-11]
Fundamentos de diseño/Entregables/Entregable 3/OnShape/Modelado Puerta.stl
180.0 x 3.00 x 160.0

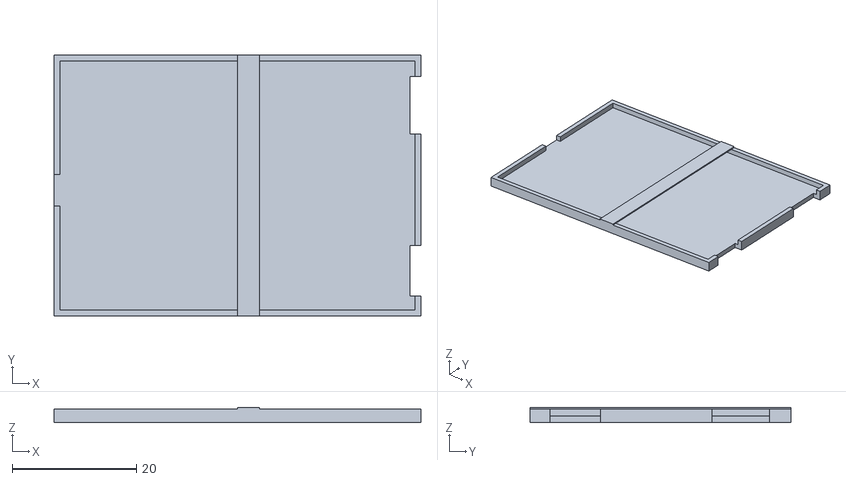
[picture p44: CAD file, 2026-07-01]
Proyecto/Módulo Mecánico/V1.0/Onshape/Partes/Soporte FC37 V1.0.stl
59.0 x 42.0 x 2.37

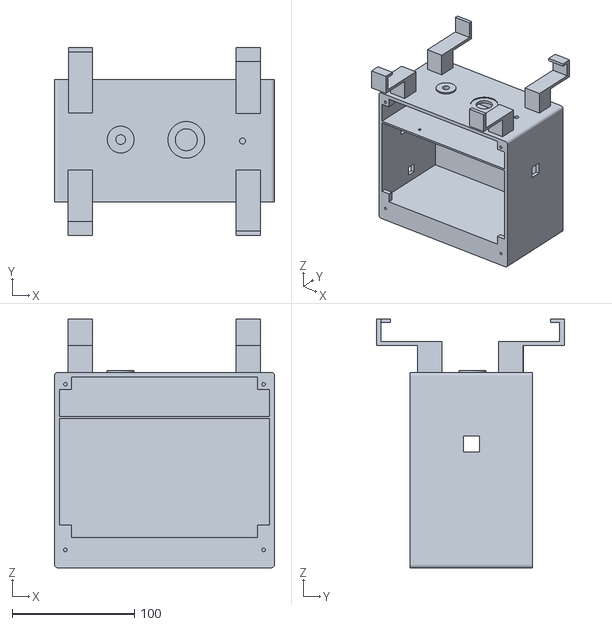
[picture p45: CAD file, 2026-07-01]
Proyecto/Módulo Mecánico/VFINAL/Onshape/Partes/Caja VFINAL.stl
180.0 x 153.9 x 203.5

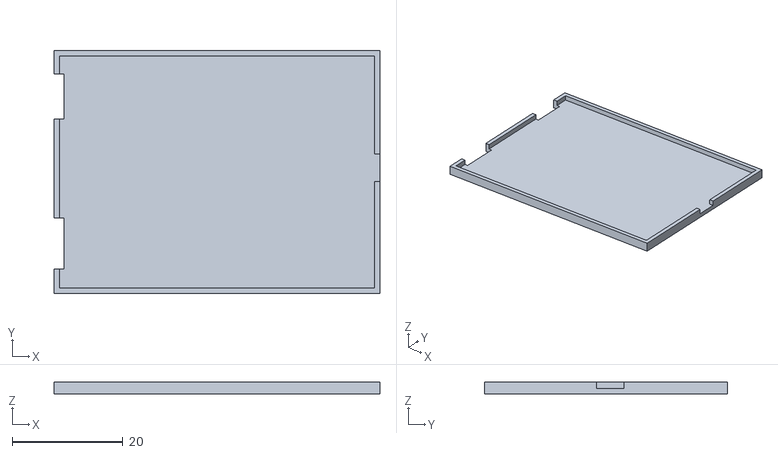
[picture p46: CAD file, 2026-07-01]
Proyecto/Módulo Mecánico/VFINAL/Onshape/Partes/Soporte FC37 VFINAL.stl
59.0 x 44.0 x 2.17

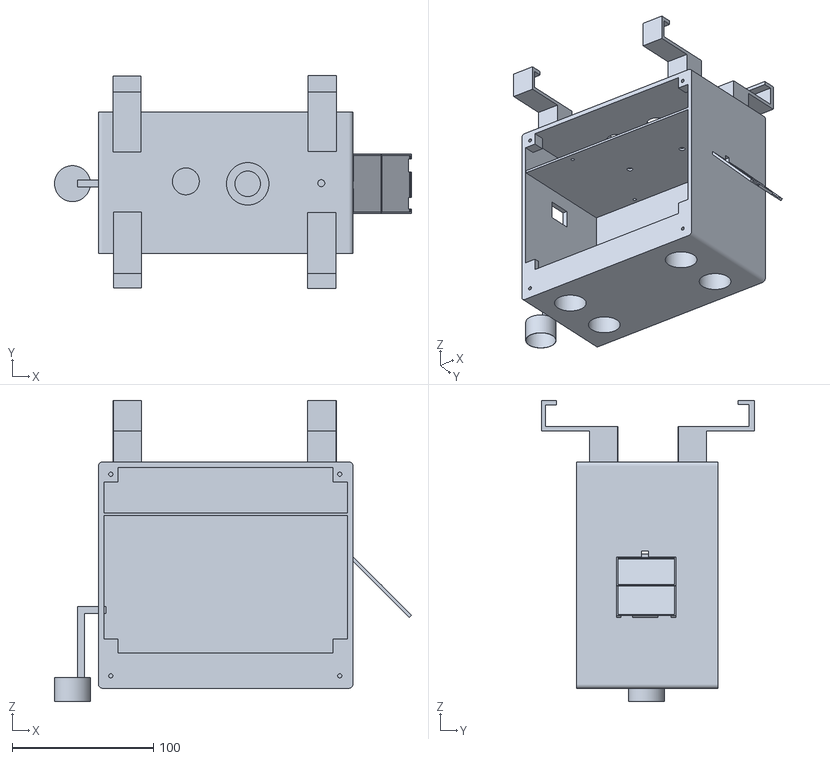
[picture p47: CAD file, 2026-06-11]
Fundamentos de diseño/Entregables/Entregable 3/OnShape/Modelado Caja.stl
252.3 x 150.4 x 213.0

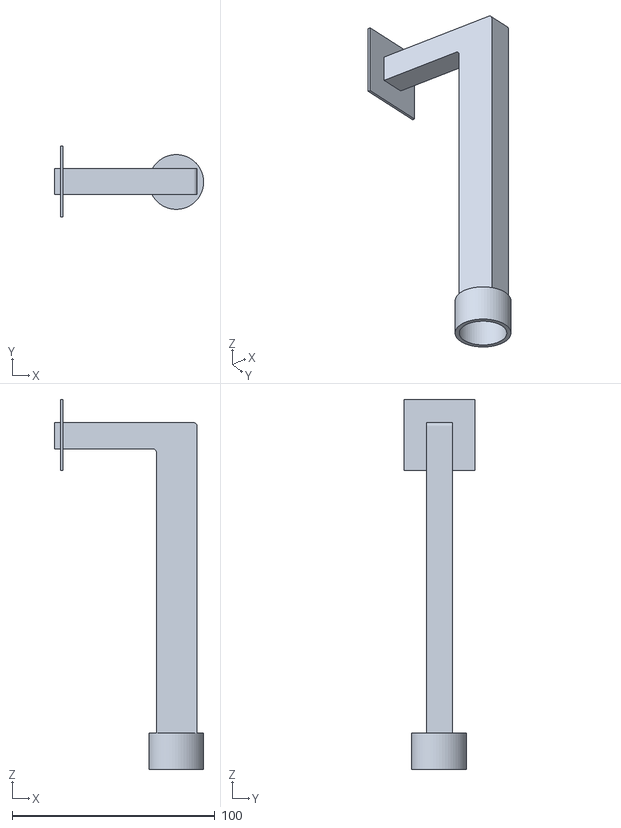
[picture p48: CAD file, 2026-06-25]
Proyecto/Módulo Mecánico/VFINAL/Onshape/Partes/Estructura en L VFINAL.STL
73.6 x 35.0 x 182.4

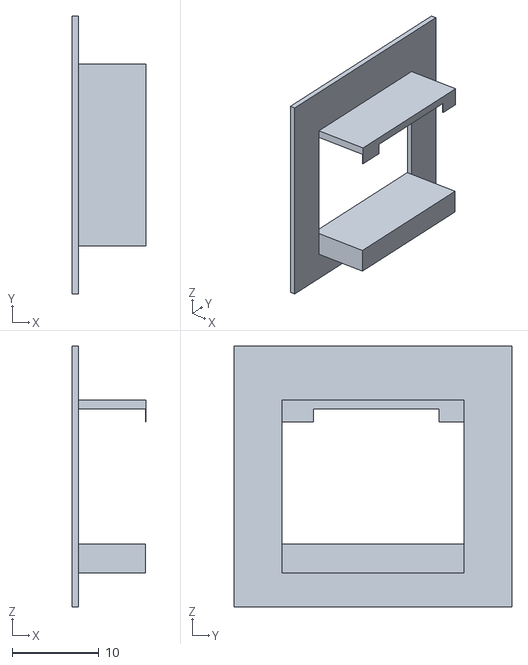
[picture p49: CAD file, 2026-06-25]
Proyecto/Módulo Mecánico/VFINAL/Onshape/Partes/Ventana VFINAL.STL
8.56 x 32.0 x 30.0

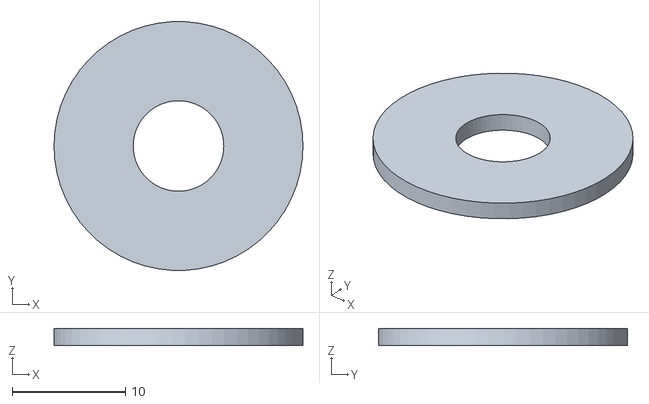
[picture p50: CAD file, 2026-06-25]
Proyecto/Módulo Mecánico/VFINAL/Onshape/Partes/Dona VFINAL.STL
22.0 x 22.0 x 1.52

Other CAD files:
Proyecto/Módulo Mecánico/V1.0/Onshape/Partes/Puerta V1.0.STL
Proyecto/Módulo Mecánico/V1.0/Onshape/Partes/Caja V1.0.STL
Proyecto/Módulo Mecánico/VFINAL/Onshape/Partes/Puerta VFINAL.stl

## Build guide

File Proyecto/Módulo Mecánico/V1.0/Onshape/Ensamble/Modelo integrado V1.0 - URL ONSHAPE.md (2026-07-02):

| Modelado integrado (ensamblaje) | [Ver modelo](https://cad.onshape.com/documents/430f59dfc079aeac550c5cab/w/060fb58aac5f1bf0b57e059d/e/191eff5bff01dd2660d429a1) |

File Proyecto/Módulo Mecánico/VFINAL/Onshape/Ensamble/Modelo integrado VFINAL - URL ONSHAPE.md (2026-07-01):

## Ensamblaje Completo

[Ver ensamblaje completo de LLAQTA Guardian](https://cad.onshape.com/documents/173e2005808784d04f353813/w/33e4a8af6ce4369997d77d69/e/b04d9702f3d523d3e3d65570)

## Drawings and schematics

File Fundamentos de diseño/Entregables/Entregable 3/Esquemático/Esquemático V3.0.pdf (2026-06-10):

# ESP 32 Sensor de temperatura y humedad Sensor ultrasónico impermeable

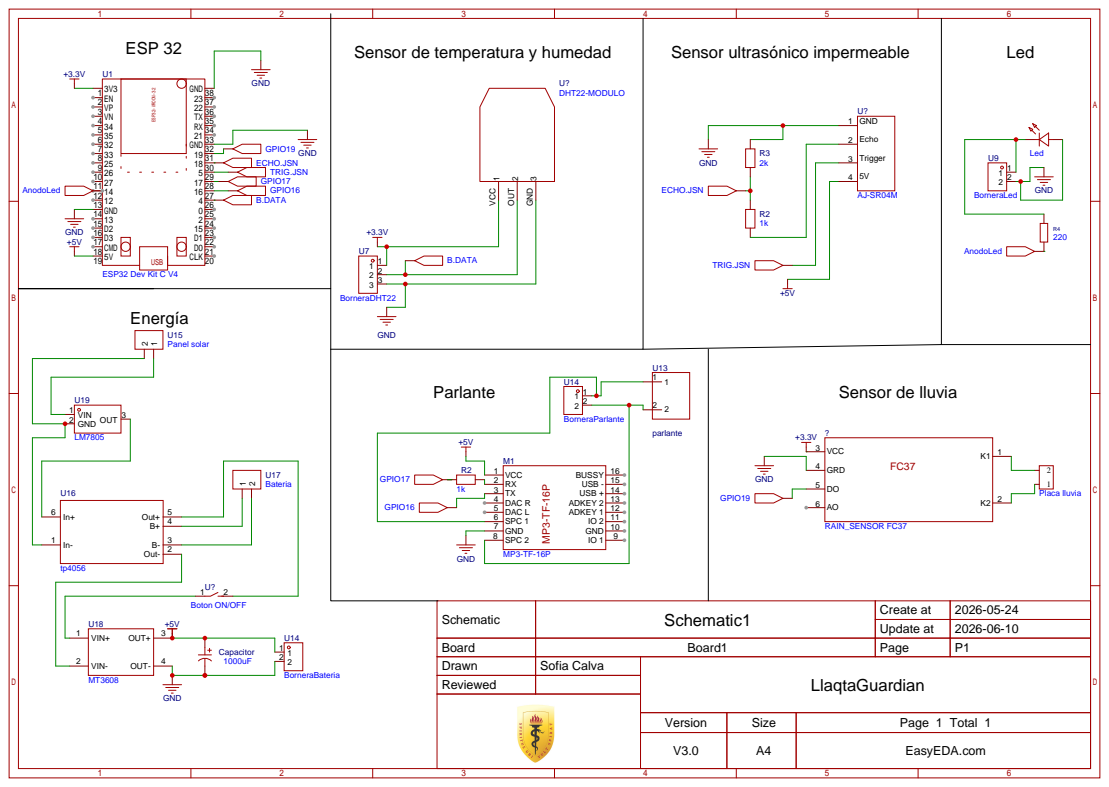
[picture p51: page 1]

GND 10 IO 2 11 ADKEY 1 12 ADKEY 2 13 USB + 14 USB - 15 BUSSY 16

Schematic | Schematic1 | Create at | 2026-05-24

Update at | 2026-06-10

Board | Board1 | Page | P1
Drawn | Sofia Calva | LlaqtaGuardian
Reviewed

Version | Size | Page 1 Total 1
V3.0 | A4 | EasyEDA.com

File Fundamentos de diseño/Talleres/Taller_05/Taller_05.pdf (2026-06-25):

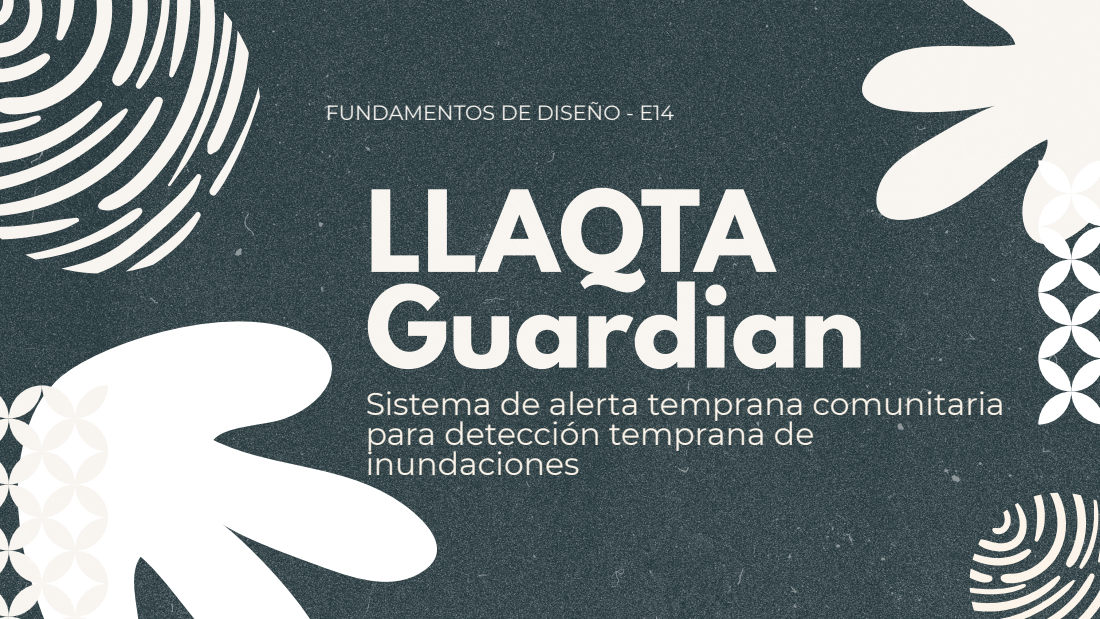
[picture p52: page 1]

FUNDAMENTOS DE DISEÑO - E14
LLAQTA
Guardian

Sistema de alerta temprana comunitaria
para detección temprana de
inundaciones

+

+ +

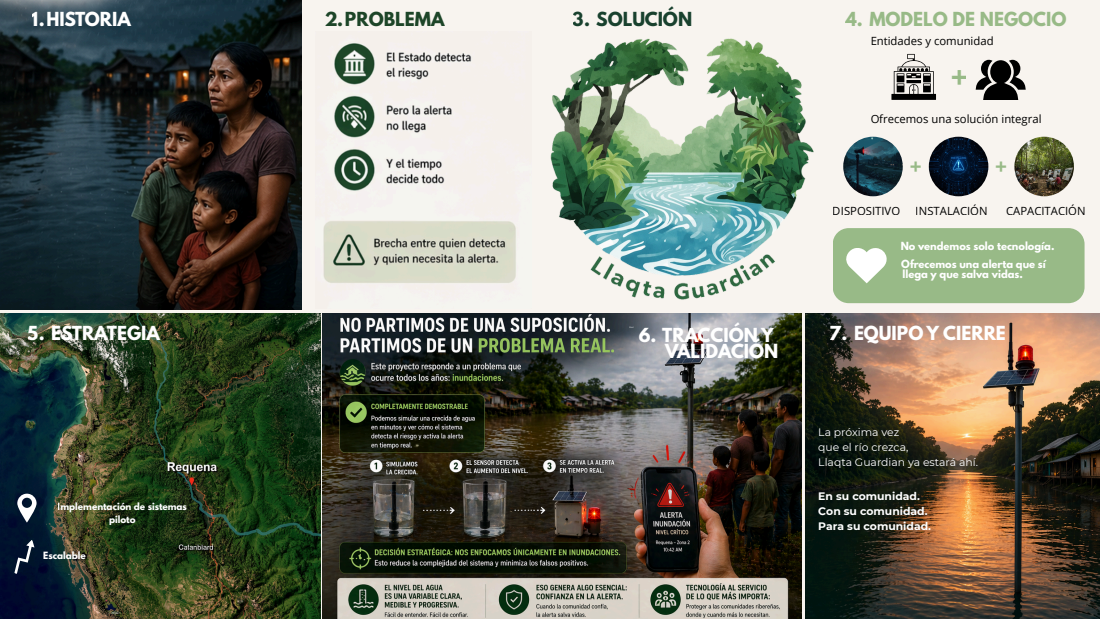
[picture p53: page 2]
1.HISTORIA; 2.PROBLEMA; 3. SOLUCIÓN; 4. MODELO DE NEGOCIO; 5. ESTRATEGIA; 7. EQUIPO Y CIERRE; Entidades y comunidad; DISPOSITIVO INSTALACIÓN; CAPACITACIÓN; piloto; Escalable; TRAC; 6. TRACCIÓN Y; VALIDACIÓN

Ofrecemos una solución integral

No vendemos solo tecnología.
Ofrecemos una alerta que sí
llega y que salva vidas.

La próxima vez
que el río crezca,
Llaqta Guardian ya estará ahí.

En su comunidad.
Con su comunidad.
Para su comunidad.

Implementación de sistemas

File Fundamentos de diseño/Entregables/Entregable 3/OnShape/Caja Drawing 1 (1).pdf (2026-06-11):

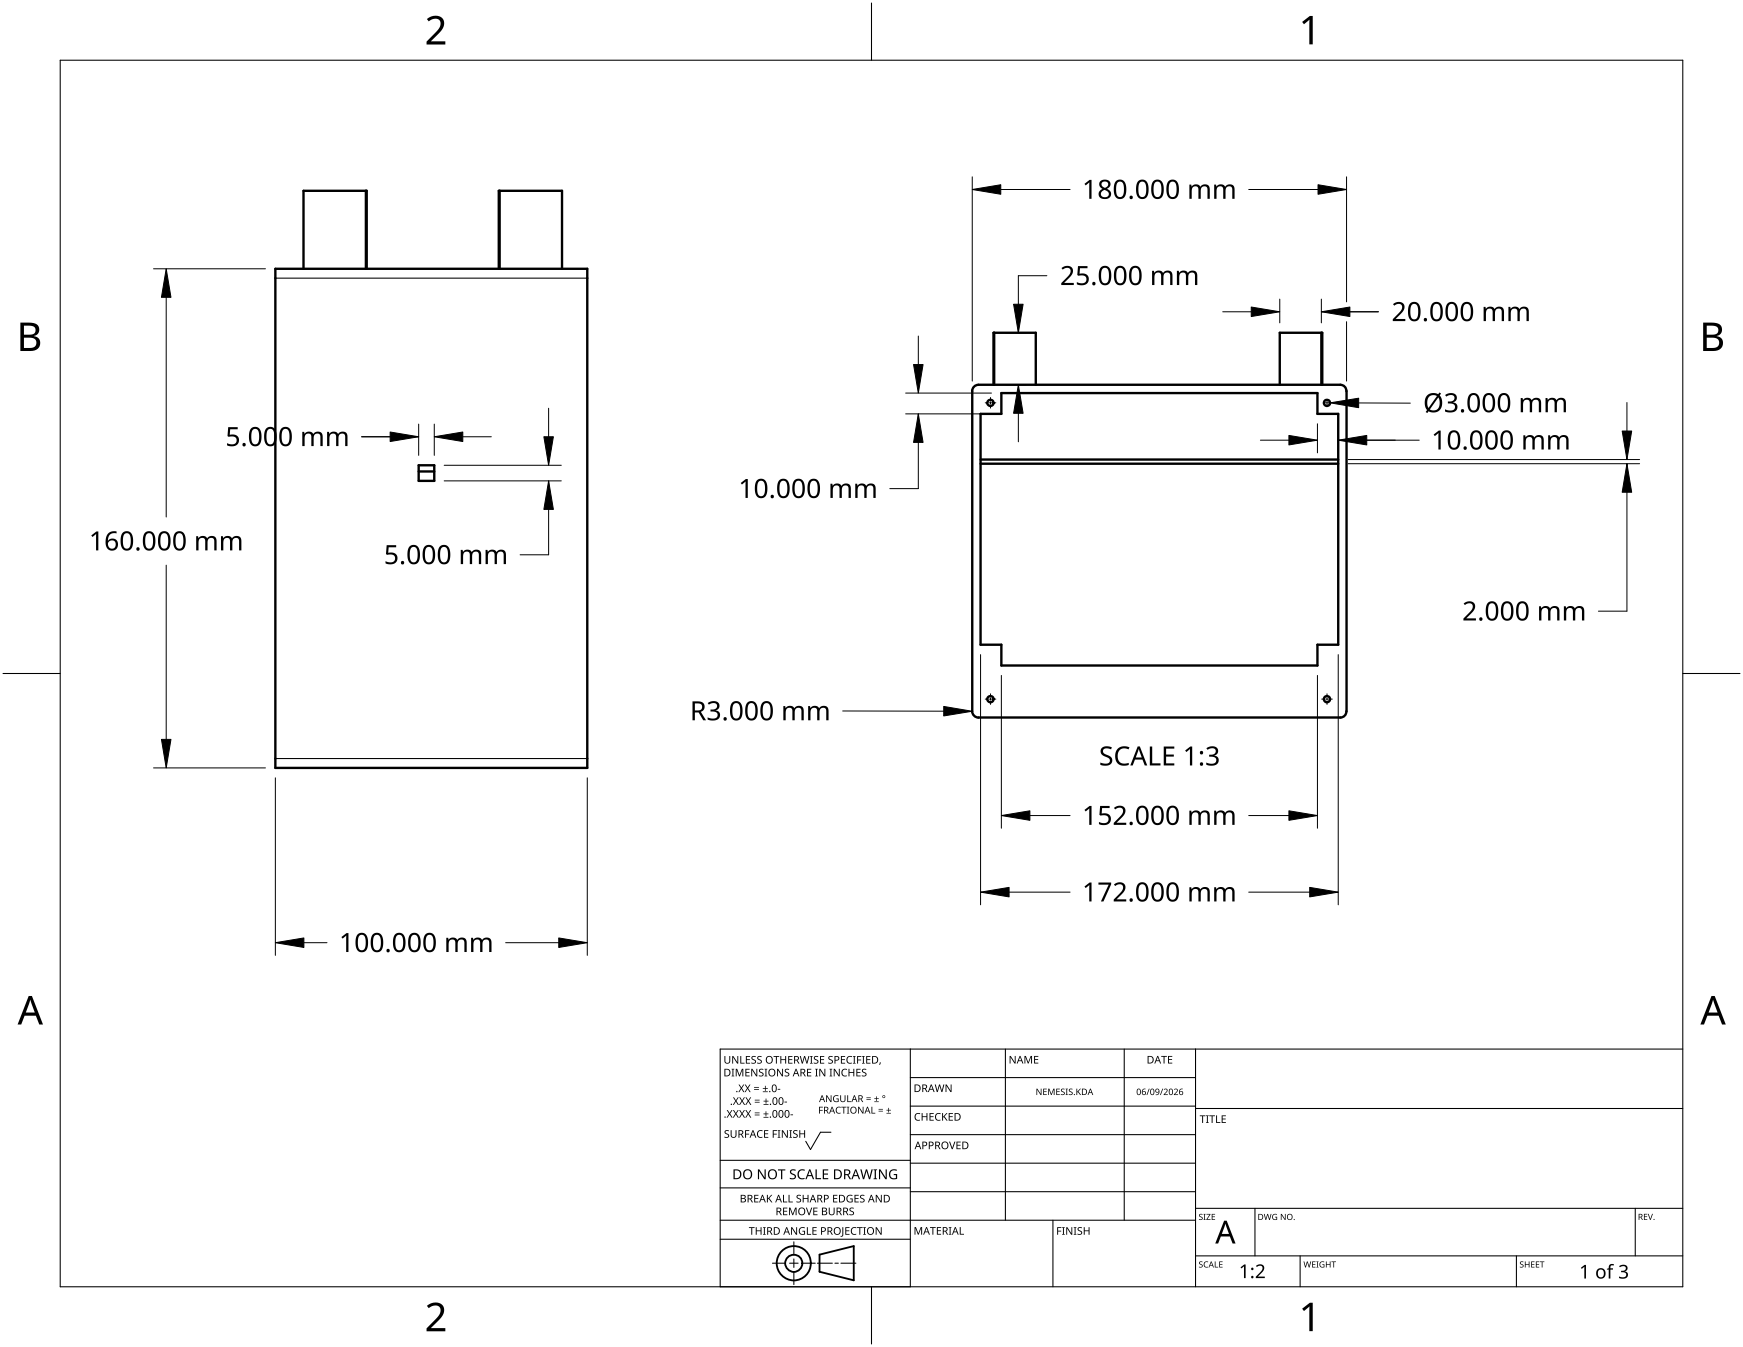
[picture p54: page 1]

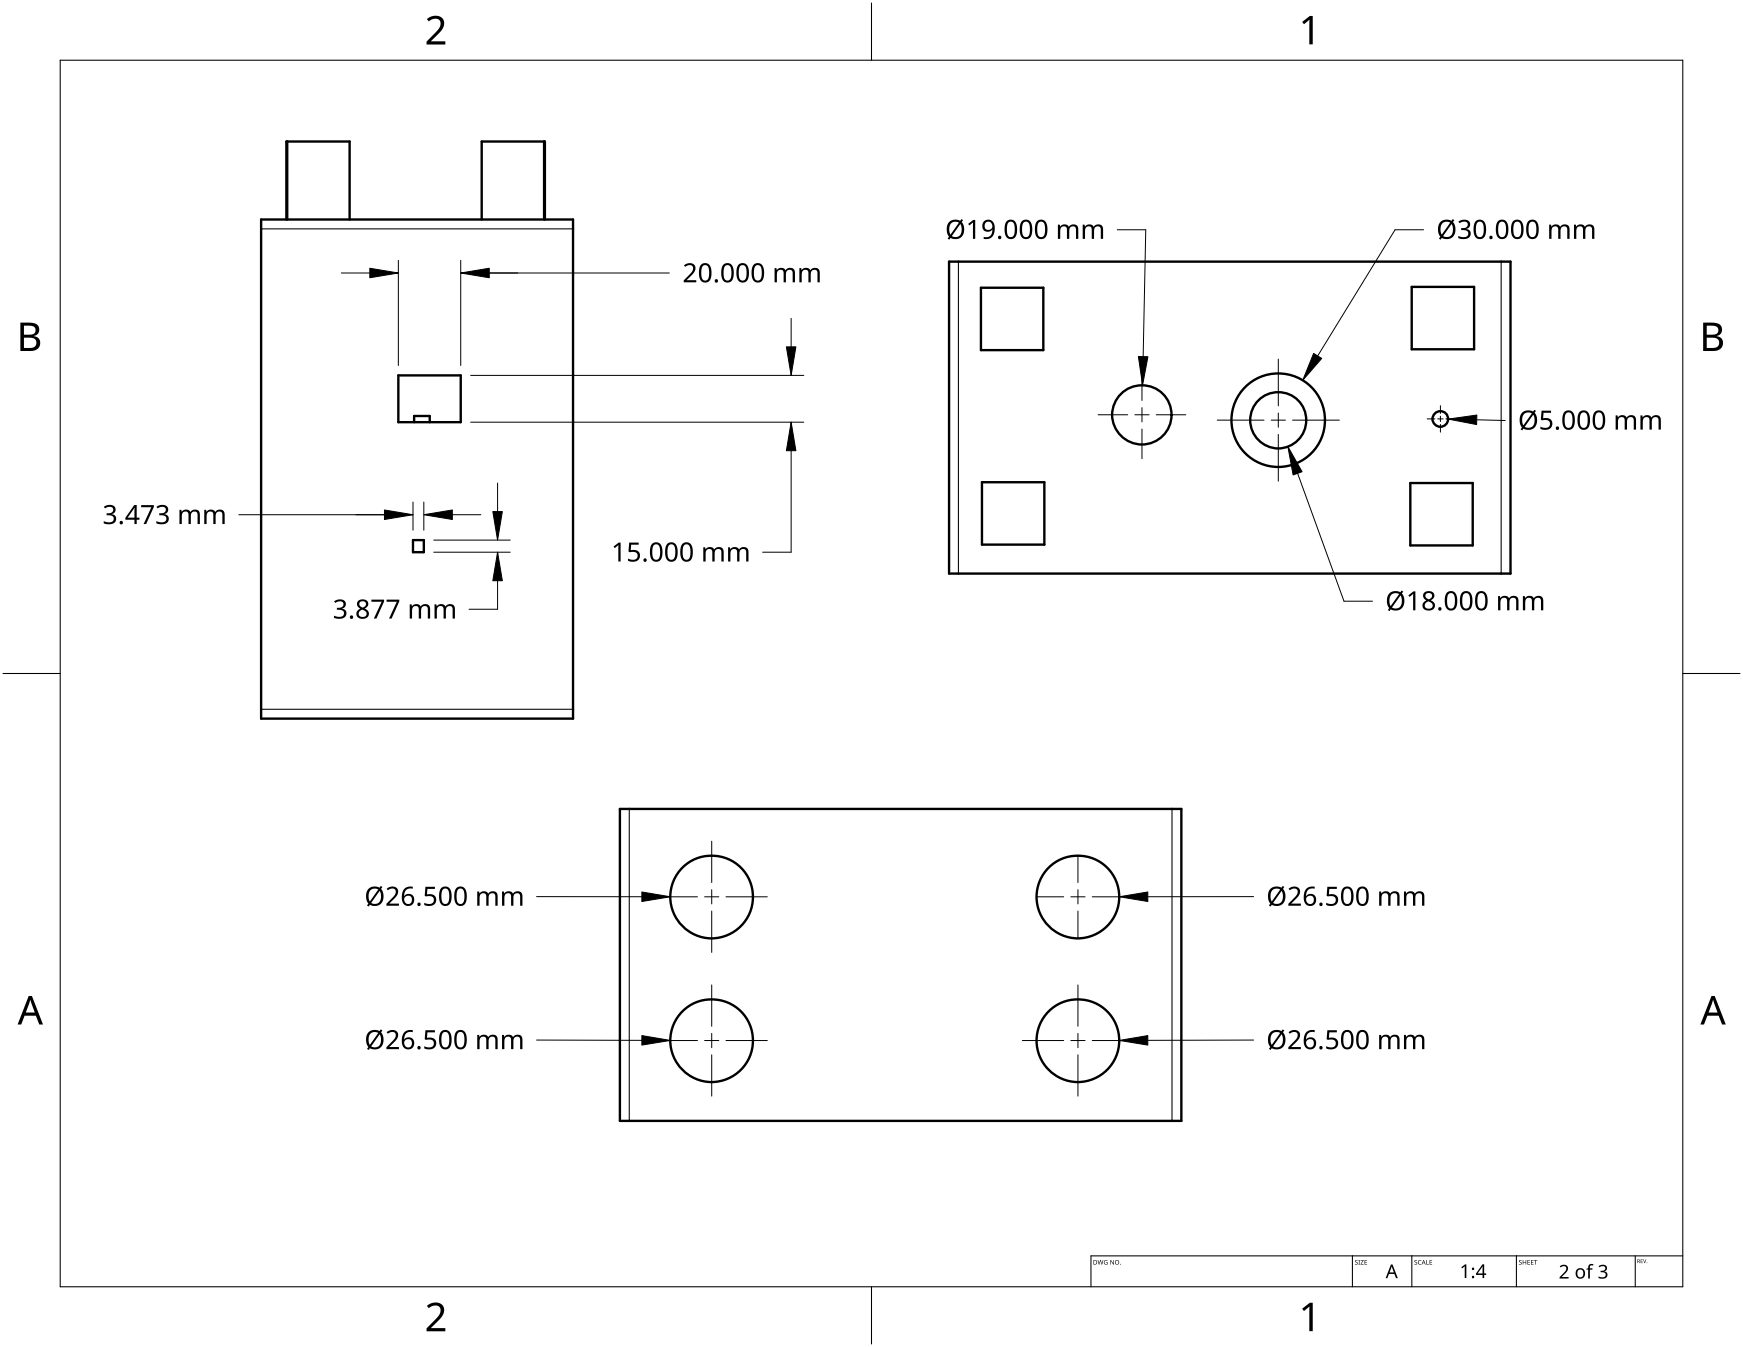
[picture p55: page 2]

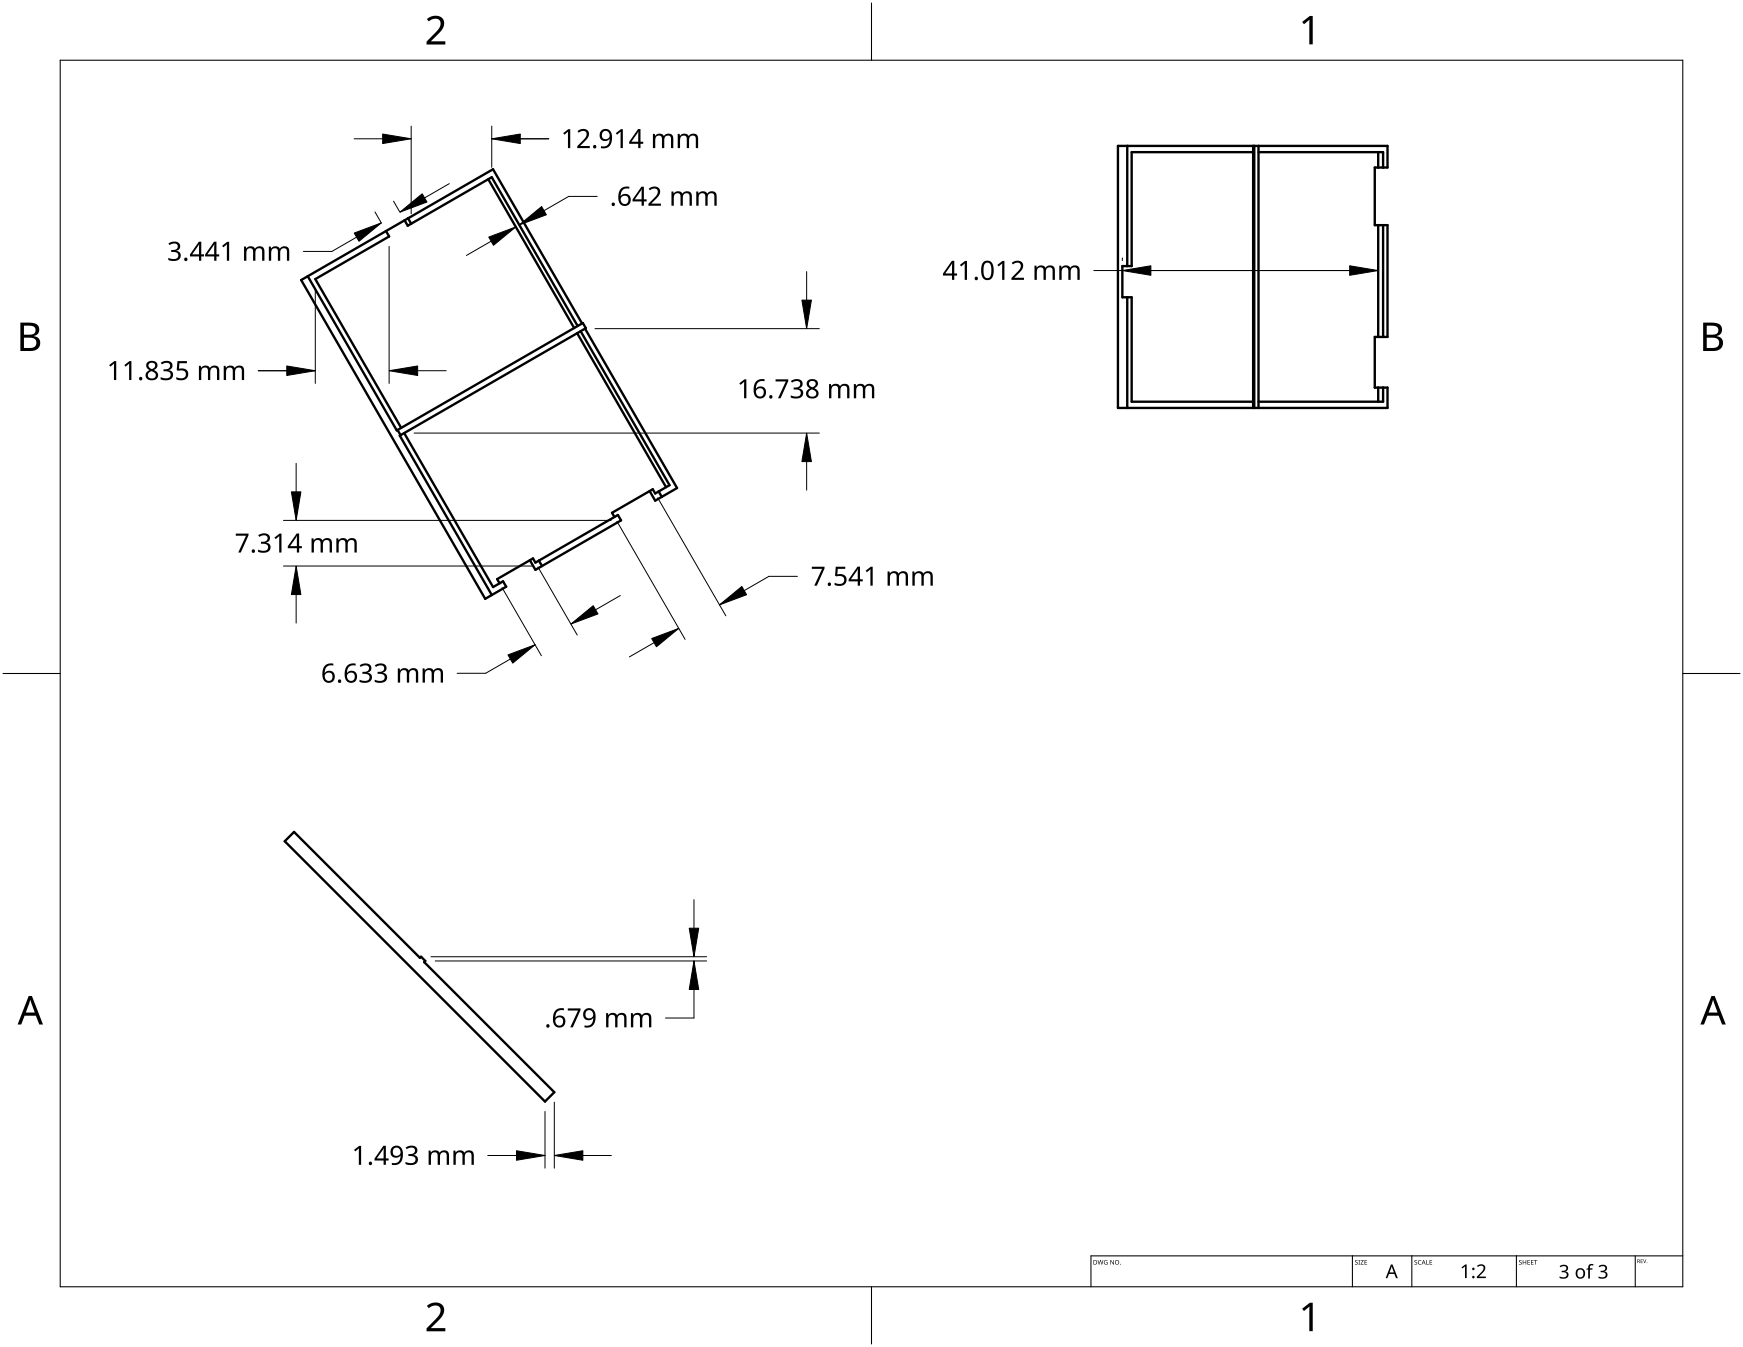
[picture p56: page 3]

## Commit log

2026-03-25 Doménica Pérez: agrego mi foto, mejoro redacción de ODS 13 y la presentación del equipo en README
2026-03-26 Agregué descripción para ODS 6
2026-03-26 Cambios de sofia
2026-03-26 cambiando nombres de carpetas
2026-03-26 cambio de imagen
2026-04-09 Actualizacion de archivos
2026-04-10 Organizacion de carpetas
2026-04-10 subida de imagenes
2026-04-10 arreglo de enlace
2026-04-22 Arreglo de la problematica
2026-04-22 Arreglo de problematica 2.0
2026-04-22 arreglo de readme
2026-04-23 Arreglo de patentes
2026-04-23 Subida del pitch
2026-04-23 Subida del pitch.PDF
2026-04-30 Subiendo el taller_7
2026-04-30 Certificaciones de Dulanto
2026-04-30 Subida de bocetos
2026-04-30 subida de certificado perez
2026-04-30 Subida de certiicados cayco
2026-04-30 Subida de certificados de perez
2026-04-30 Subida de certificado de huillca
2026-04-30 Subida de cetificados
2026-05-05 Correción del pdf del Pitch, se mostraba incompleto
2026-05-06 Presentación de Llaqta Guardian_taller7
2026-05-06 Mejoras en la introducción, problemática y solución
2026-05-07 Actualización de bocetos
2026-05-07 subida de canva
2026-05-14 Diagrama de Flujo TALLER _ SEMANA 9
2026-05-21 Subiendo el esquemático
2026-05-21 Subiendo el modelado
    [Modelado.stl]
2026-05-28 Actualización de modelado 3D
    [Modelado.stl, Modelado3D.stl]
2026-06-11 Create README for Entregable 3: Llaqta Guardian
    Added detailed design and prototyping documentation for Llaqta Guardian, including schematics, design sketches, and 3D modeling files.
2026-06-11 Add updated sketches and descriptions for Llaqta Guardian
    Added detailed sketches and descriptions for the Llaqta Guardian device container, including external and internal views.
2026-06-11 Add updated sketches for Llaqta Guardian device
    Added updated sketches and descriptions for the Llaqta Guardian device container, including external and internal views.
2026-06-11 modelado 3d
    [Assembly 1 (2).stl, Assembly completo.stl, Modelado Caja.stl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]
2026-06-11 Revise README for Entregable 3 with detailed sections
    Updated the README to enhance clarity and structure, including detailed sections on schematics, design sketches, 3D modeling, and manufacturing files.
2026-06-25 Reorganización de carpetas y actualización
    [Assembly 1 (2).stl, Assembly completo.stl, Caja V1.0.STL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]
2026-06-25 README principal agregado
    [Assembly completo.stl, Assembly.stl, Modelado Caja.stl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]
2026-06-29 Corrigiendo formato de tabla
